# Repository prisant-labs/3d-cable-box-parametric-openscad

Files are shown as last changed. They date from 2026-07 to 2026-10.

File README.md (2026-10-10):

# Parametric Cable Management Box

A cable box you size to your stuff, not the other way round. Configurable
openings on every wall, an optional cable-wrapping post, interior stiffening
fins, floor cutouts, optional Gridfinity interfaces, and a slicing mode that
splits oversized boxes into pieces that clip together.

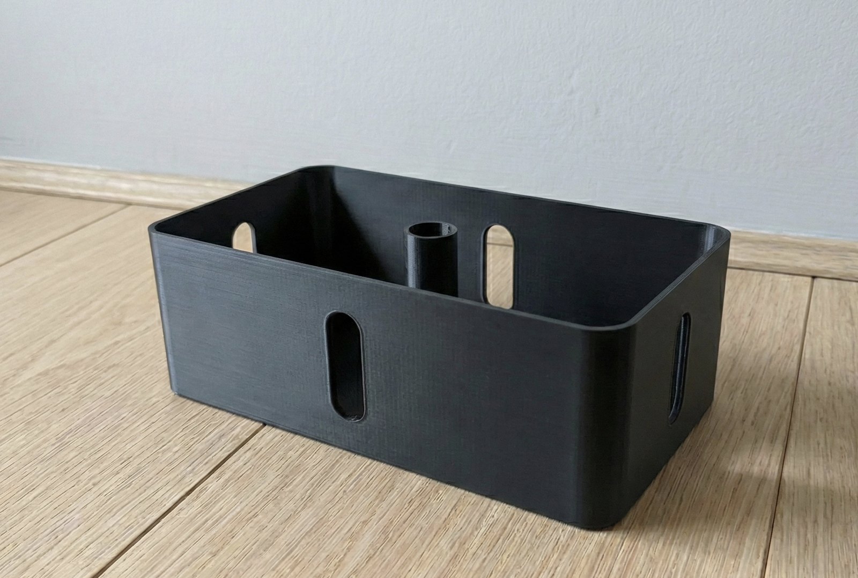
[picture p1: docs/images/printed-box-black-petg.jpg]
A printed cable box in black PETG


*Printed in black PETG with `All_Openings_Up=0`, which sits the openings flush
with the floor so a cable resting on the desk slides straight in.*





## Get a box

**Just want to print one?** Pick a preset in the
[preset library](https://projects.prisantlabs.com/3d-cable-box-parametric-openscad/library/), which has 3D previews and
STL downloads, or take the files straight from [`library/`](library/). Nine
presets cover the common jobs, from a compact desk tidy to a six-outlet surge
strip split for a 180 mm bed. No software needed beyond your slicer.

Both track `main`, so they match the current model. The
[Releases page](https://github.com/prisant-labs/3d-cable-box-parametric-openscad/releases) holds fixed, tested snapshots, and from `v2.0.0-rc.4` on
each release attaches all nine presets as `cable-box-presets.zip`. Until 2.0.0
ships as final, GitHub's "Latest" release is still `v1.4.1`, from before the
2.0.0 changes, so take the newest "Pre-release" for the current geometry.

Printing a feature for the first time, such as a Gridfinity base, snap clips,
or magnets? Print a small [fit test box](docs/PRINTING.md#fit-test-box) with
the same settings first, before you commit to a full box.

**Want to change something?** The model needs
[BOSL2](https://github.com/BelfrySCAD/BOSL2):

```bash
# Windows and macOS
git clone https://github.com/BelfrySCAD/BOSL2.git ~/Documents/OpenSCAD/libraries/BOSL2

# Linux
git clone https://github.com/BelfrySCAD/BOSL2.git ~/.local/share/OpenSCAD/libraries/BOSL2
```

Then open `cable-box-parametric.scad` in [OpenSCAD](https://openscad.org/)
(2021.01 or newer), press <kbd>F3</kbd> for the Customizer, adjust,
<kbd>F6</kbd> to render, then export an STL.

Would rather not install anything? Every release attaches a **standalone
bundle** with BOSL2 inlined. Unzip both files into the same folder and open the
bundled `.scad`.

If you open the plain `.scad` without BOSL2 installed, the model stops with a
message telling you so, rather than rendering nothing and exiting successfully.

**Want to see what everything does first?** Open the
[visual options guide](https://projects.prisantlabs.com/3d-cable-box-parametric-openscad/options-guide.html). Every parameter is rendered
from the model, in one self-contained file you can also
[download](docs/options-guide.html) to use offline.

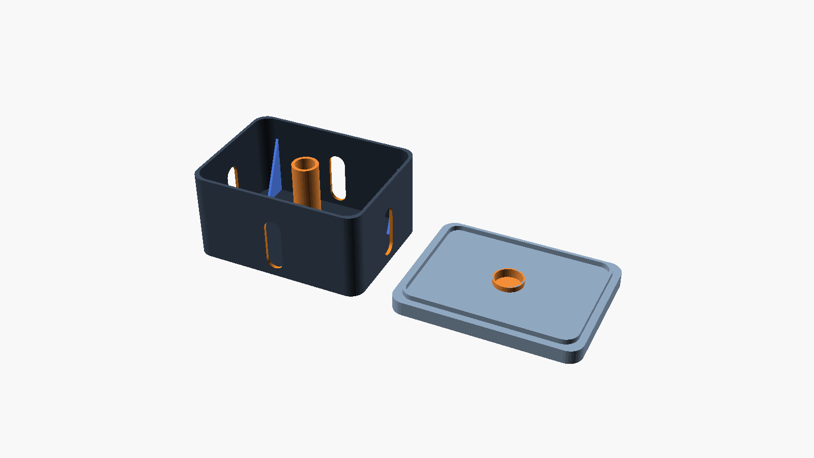
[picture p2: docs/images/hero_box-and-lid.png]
Box and lid


## What it does

| | |
|---|---|
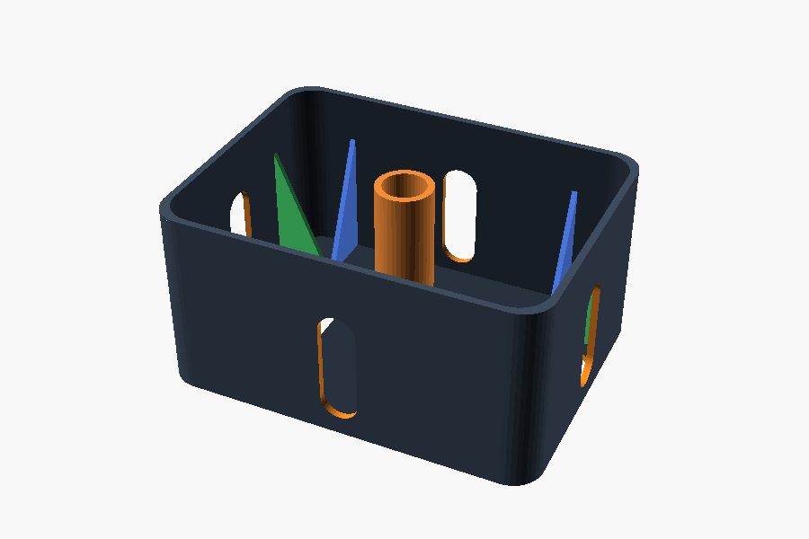
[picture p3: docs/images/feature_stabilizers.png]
Stabilizer fins and floor cutouts
|  | **Fins and floor cutouts.** Interior ribs stiffen long walls and automatically skip positions that would block an opening. Floor cutouts arrange along either axis and split around the centre post. |
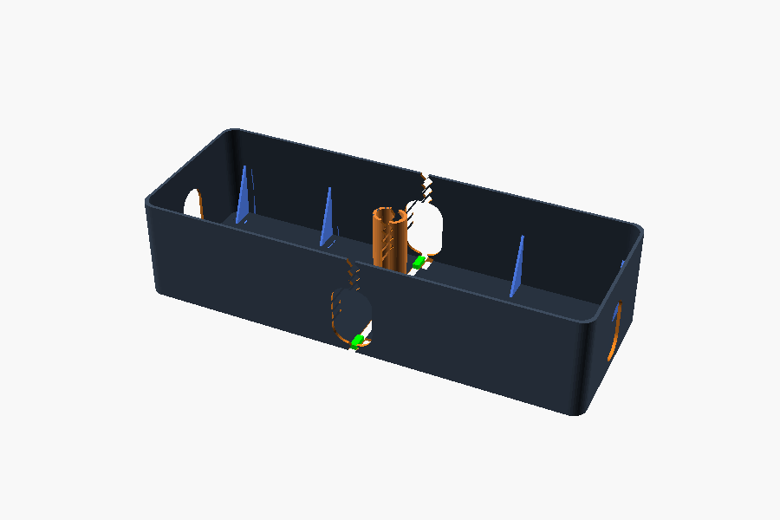
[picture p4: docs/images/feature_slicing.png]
Slicing into two clipping halves
|  | **Bigger than your printer?** Slicing mode splits the box and lid into pieces joined by tab or snap clips, so a 265 mm box prints on a 180 mm bed. |
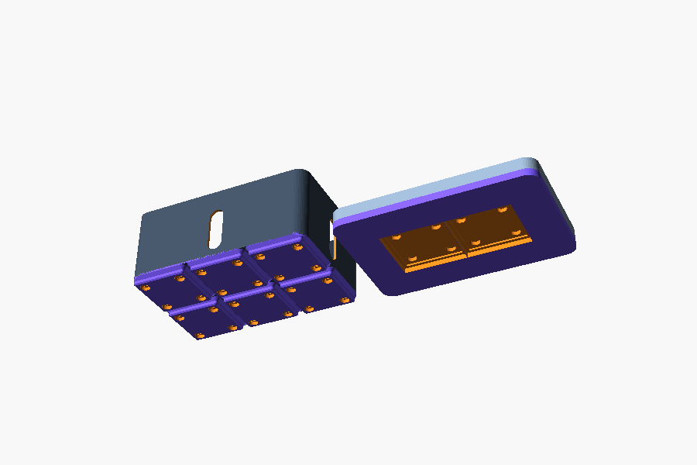
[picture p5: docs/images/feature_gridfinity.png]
Gridfinity interfaces on the underside
|  | **Gridfinity, optionally.** Solid feet built to the spec's profile, so the box drops into a standard 42 mm baseplate, with the footprint rounded up to whole cells. A baseplate socket on the lid lets bins sit on the closed box. Optional magnet and screw pockets, whose bridging layers follow `Print_Layer_Height`. The lid top is experimental for now: test prints show its sockets do not yet print or fit as cleanly as a standard baseplate. |
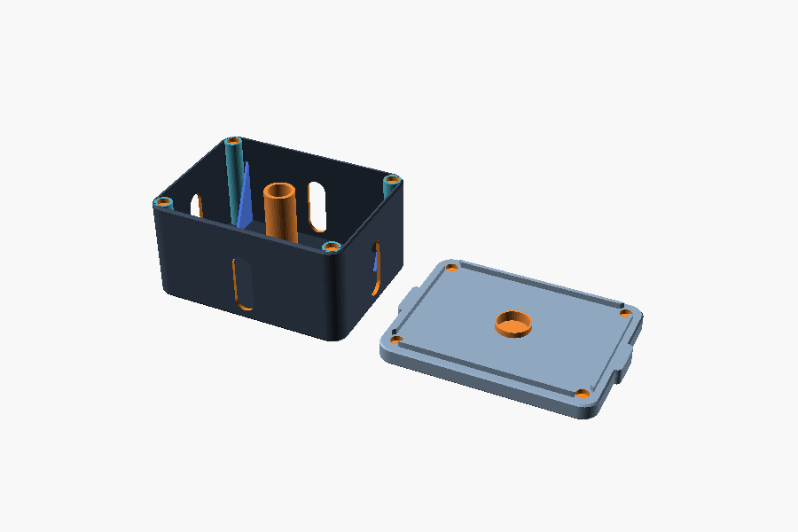
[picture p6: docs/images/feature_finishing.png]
Rounded edges, lid grips and corner magnet bosses
|  | **Finishing touches.** A rounded bottom edge and a chamfered rim, a scallop or tab grip so a tight lid comes off without a tool, and corner magnets that hold the lid shut. For printing without supports, `All_Opening_Top_Style=Teardrop` gives openings 45 degree tops, and `Bottom_Edge_Style` can meet the bed at 45 degrees. All are off by default. |

Plus: per-wall opening sizes and positions, an open or closed-bottom centre
post, adjustable lid fit, and corner radii from crisp to soft.

### Seam joints

Sliced boxes join with one of two clip styles:

- **`Tab`** (default) is a friction fit. Simple, and tuned with `Clip_Tolerance`.
- **`Snap`** is a cantilever clip with an engagement bump. The arm flexes, so it
  absorbs print inaccuracy instead of jamming, and the bump resists pull-out
  rather than relying on interference.

`Snap` is opt-in for now. Clip correctness is the one thing here that rendering
cannot check: a joint too tight to assemble passes every automated test. The
default flips once a print says it should.

Above the floor, each seam is cut as a 45 degree sawtooth through the walls, so
the joined pieces cannot slide vertically and their rims meet flush. The teeth
print without supports, and `Seam_Tooth_Depth=0` gives a flat seam instead.

### Composing with it

The box and lid are BOSL2 attachables, so accessories attach to named features
instead of computed coordinates:

```scad
Render_On_Include = false;   // or -D Render_On_Include=false
include <cable-box-parametric.scad>

m_box()
    attach("wall-back")
        my_bracket();
```

Anchors: `floor`, `rim`, `wall-front`, `wall-back`, `wall-left`, `wall-right`,
`post-top`, plus `lid-face` and `lip` on the lid. `lid-face` names the face that
ends up exposed when the box is closed, so nobody has to re-derive which side of
a face-down-printed lid is up.

## Presets

Nine ready-to-print configurations live in [`library/`](library/), each with a
complete `config.json`, STLs, renders, and notes. They are also browsable with
3D previews at
[the preset library on the docs site](https://projects.prisantlabs.com/3d-cable-box-parametric-openscad/library/).

| Preset | Fits | Size (mm) |
|---|---|---|
| [`usb-charger`](library/usb-charger/) | GaN multi-port charger and cables | 120 x 75 x 45 |
| [`desk-compact`](library/desk-compact/) | Short power strip, few cables | 140 x 80 x 55 |
| [`gridfinity-module`](library/gridfinity-module/) | Gridfinity 3 x 2 desk module | 125.5 x 83.5 x 60 |
| [`laptop-brick`](library/laptop-brick/) | Laptop charger plus 3 cables | 175 x 105 x 70 |
| [`under-desk-passthrough`](library/under-desk-passthrough/) | Cable junction, no post | 180 x 85 x 50 |
| [`monitor-junction`](library/monitor-junction/) | Two monitor bricks | 210 x 95 x 62 |
| [`router-shelf`](library/router-shelf/) | Router or modem plus PSU | 230 x 130 x 75 |
| [`surge-strip-6`](library/surge-strip-6/) | Six-outlet surge protector | 265 x 100 x 62 |
| [`surge-strip-6-sliced`](library/surge-strip-6-sliced/) | Same, split for a 180 mm bed | 265 x 100 x 62 assembled; largest piece 136 x 100 |

All nine are also collected into `cable-box-parametric.json` next to the model,
so opening `cable-box-parametric.scad` and pressing <kbd>F3</kbd> offers every
preset in the Customizer's dropdown.

Load one from the command line, from the merged file:

```bash
openscad -o out.stl cable-box-parametric.scad \
  -p cable-box-parametric.json -P desk-compact
```

Or from a single preset's own copy:

```bash
openscad -o out.stl cable-box-parametric.scad \
  -p library/desk-compact/config.json -P desk-compact
```

Both are OpenSCAD's native parameter-set format, so a set you save from the
desktop Customizer drops straight back in, and settings survive a round trip.

## Documentation

Published at
**[projects.prisantlabs.com/3d-cable-box-parametric-openscad](https://projects.prisantlabs.com/3d-cable-box-parametric-openscad/)**.

| Doc | What's in it |
|---|---|
| [Options guide (HTML)](https://projects.prisantlabs.com/3d-cable-box-parametric-openscad/options-guide.html) | Every parameter, rendered. Self-contained; [download it](docs/options-guide.html) to use offline. |
| [Options guide (Markdown)](docs/OPTIONS_GUIDE.md) | The same, readable on GitHub. |
| [Parameter reference](docs/PARAMETER_REFERENCE.md) | Exhaustive tables for every parameter. |
| [Workflows](docs/WORKFLOWS.md) | Setup, calibration, slicing, troubleshooting. |
| [Printing guide](docs/PRINTING.md) | Materials, orientation, fit test boxes, and fit tuning. |
| [FAQ](docs/FAQ.md) | Common questions and fixes. |
| [Validation rules](docs/VALIDATION_RULES.md) | Every assertion, what triggers it, how to resolve it. |
| [Module reference](docs/MODULE_REFERENCE.md) | Module-by-module geometry breakdown. |
| [Architecture](docs/SCAD_ARCHITECTURE.md) | Data flow and coordinate conventions. |
| [Parameter interactions](docs/PARAMETER_INTERACTIONS.md) | Cross-parameter behaviour. |

## A note on dimensions

`Box_Width`, `Box_Depth`, and `Box_Height` are **outer** dimensions. Usable
interior is smaller by `Wall_Thickness` on each side, and smaller again wherever
stabilizer fins sit. The model echoes the numbers at render time.

Side openings are anchored at their **bottom edge**. The default
`All_Openings_Up = 5` lifts that edge 5 mm above the box floor. Set it to `0`
to put the opening flush with the box bottom, so a cable lying on the desk
passes straight in without climbing a lip.

## Contributing

The most useful contribution right now is a print report. Print a small
[fit test box](docs/PRINTING.md#fit-test-box) and open an issue with the
result, even when it fits, because that is what turns "renders cleanly" into
"prints cleanly".

Presets are the next easiest: add an entry to `PRESETS` in
`scripts/build_library.py` and rerun it. See [`CONTRIBUTING.md`](CONTRIBUTING.md),
[`CODE_OF_CONDUCT.md`](CODE_OF_CONDUCT.md), and [`SECURITY.md`](SECURITY.md).

Behaviour changes need the docs updated in the same PR, and a test scenario if
the change guards a failure mode that would otherwise exit `0`.

## Validation

Model changes are gated by an automated geometry suite, not just a compile check.

```bash
python tests/run_tests.py          # 118 scenarios
bash scripts/scad-smoke.sh         # quick render smoke
bash scripts/check-version.sh      # version consistency
bash scripts/bump-bosl2.sh         # verified BOSL2 dependency upgrades
```

The suite asserts exit codes, assertion text, manifoldness, disconnected-solid
counts, bounding boxes, absence of warnings, and point probes against the
exported mesh. That matters more than it sounds: OpenSCAD will happily return
`0` while producing a model with a detached, unprintable piece in it, or a
correctly-sized part rotated onto the wrong axis.

The runner prints which BOSL2 version OpenSCAD actually loads before running
anything, because a local suite silently testing a different library version
than CI is a real failure mode this project has already hit.

## Licence

[MIT](LICENSE). Print them, sell them, remix them.

Third-party components keep their own terms; see
[`THIRD_PARTY_NOTICES.md`](THIRD_PARTY_NOTICES.md). Gridfinity is by Zack
Freedman and is MIT licensed; the interface geometry here is implemented from
the published specification rather than vendored.

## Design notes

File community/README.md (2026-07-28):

# Community

Community-contributed builds, remixes, and showcases live here.

## What belongs here

- User variants and remixes
- Print photos and setup shots
- Alternative parameter profiles
- Build notes and lessons learned

## Suggested contribution layout

- `community/<github-user-or-handle>/<project-name>/README.md`
- `community/<github-user-or-handle>/<project-name>/images/*`
- `community/<github-user-or-handle>/<project-name>/stl/*` (optional)
- `community/<github-user-or-handle>/<project-name>/config.*` (recommended)

## Contributor README minimum

- Short description and use case
- Parameter highlights
- Printer/material used
- Known fit adjustments
- License/attribution notes if third-party content is included

## Moderation and quality guidance

- Keep content respectful and technically useful.
- Avoid storing sensitive personal information in media or docs.
- Verify that contributed files are license-compatible with the repository policy.

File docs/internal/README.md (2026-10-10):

# Internal Planning Docs

Scoping documents for the work behind each release. They live in the repo
without appearing on the public site: `web/sync-docs.mjs` copies a named list of
pages into the site's content directory, and this directory is not on it, so
nothing here is published unless someone adds it deliberately. (The old
mechanism was `exclude_docs: internal/` in `mkdocs.yml`, which no longer exists.)

Each effort carries an ID and a handle. Always write both on first mention, in
commits, issues, and chat: "E-01 (Gridfinity promotion)", never a bare "E-01".

Status values: **Shipped** in the named release, **Open** for started but
incomplete, **Spec** for written but not begun.

## Efforts

| ID | Handle | Scope | Status | Effort | Depends on |
|---|---|---|---|---|---|
| [E-01](E-01_gridfinity-promotion.md) | **Gridfinity promotion** | Box-underside and lid-topside Gridfinity interfaces | Shipped v1.2.0; lid reworked to a socket in 2.0.0. Geometry replaced by E-12 after the rc.5 prints | S | none |
| [E-02](E-02_bosl2-migration.md) | **BOSL2 migration** | Build on BOSL2 rather than hand-rolled primitives | Shipped: phase 1 v1.3.0, phases 2-3 v1.4.0 | L | none |
| [E-03](E-03_openings-array.md) | **Openings array** | Replace 4 fixed per-wall openings with an array-driven spec | Spec | M | E-02 (easier after) |
| [E-04](E-04_quick-wins.md) | **Quick wins** | Edge treatment, lid removal relief, magnet retention | In `v2.0.0-rc.3`, final in 2.0.0. Opt-in defaults. Edge treatment and magnets confirmed by test prints; relief unprinted | S | none |
| [E-05](E-05_size-by-contents.md) | **Size by contents** | Size the box from what goes in it, not from outer dimensions | Spec | M | none |
| [E-06](E-06_thermal-and-vents.md) | **Thermal and vents** | Ventilation generator plus material guidance for powered contents | Spec | M | E-03 (shares cut logic) |
| [E-07](E-07_preset-library.md) | **Preset library** | A real catalogue of common sizes and configurations | Shipped: catalogue v1.2.0, browser 2.0.0 | M | E-09 (needs artifact automation) |
| [E-08](E-08_web-customizer.md) | **Web customizer** | Browser-based customizer on GitHub Pages | Open. Site shell and preset browser shipped; the WASM playground is not built | M | E-02 (library availability) |
| [E-09](E-09_testing-automation.md) | **Testing automation** | Automated geometry regression testing beyond compile checks | Shipped v1.1.1; 118 scenarios today | M | none |
| [E-10](E-10_versioning.md) | **Versioning** | Version scheme, pre-release flow, traceability from STL to source | Shipped v1.1.1; rc flow used for v1.2.0-rc.1 and v2.0.0-rc.1 through rc.4; releases drafted by `release.yml` | S | none |
| [E-11](E-11_distribution.md) | **Distribution** | MakerWorld, Printables, and the licensing question that gates them | Open. Licence settled (MIT); listing drafted, nothing published | S | E-02 (MakerWorld benefits) |
| [E-12](E-12_gridfinity-to-spec.md) | **Gridfinity to spec** | Rebuild both Gridfinity interfaces on the standard's swept profile, printable without supports | Phase A (box feet) in `v2.0.0-rc.6`, waiting on its print; phase B (lid top) next, for rc.7 | M | none |
| [E-13](E-13_seam-joints.md) | **Seam joints** | A 45 degree sawtooth seam through the walls, so sliced halves cannot slide vertically | In `v2.0.0-rc.6`; waiting on the rc.6 print | S to M | none |
| [E-14](E-14_printability-options.md) | **Printability options** | Opt-in teardrop opening tops, a bottom edge that meets the bed at 45 degrees, and a layer height for the Gridfinity bridging | In `v2.0.0-rc.6`, with every default unchanged; waiting on the rc.6 print | S to M | E-12 phase A (merged) |

Effort key: S = under a day, M = a few days, L = a week or more.

Ideas not yet scoped as an effort, and known problems still open, are in
[BACKLOG.md](BACKLOG.md).

## What is left

The infrastructure efforts are done: testing (E-09), versioning (E-10), the
BOSL2 migration (E-02), the preset library (E-07), and the Gridfinity interfaces
(E-01) have all shipped. What remains splits three ways.

**Answered by test prints, now designed.** The rc.4 and rc.5 test prints
settled the lid fit. They also showed two problems, and both were scoped on
2026-10-07 for the 2.0.0 release-candidate series, ahead of the 2.0.0 release:

- [E-12 (Gridfinity to spec)](E-12_gridfinity-to-spec.md) rebuilds the
  Gridfinity interfaces from E-01 (Gridfinity promotion). They print poorly and
  do not follow the standard's 45 degree profile, as backlog items 15
  (Gridfinity base seating) and 18 (Gridfinity printability) record.
- [E-13 (seam joints)](E-13_seam-joints.md) answers backlog item 20 (seam
  alignment): neither clip style holds sliced halves level. The snap-clip
  default in [E-02-P2 (snap clips)](E-02-P2_snap-clips.md) is decided by the
  same print round.

**Printing without supports.** [E-14 (printability options)](E-14_printability-options.md)
adds three opt-in parameters for printing without supports. It was scoped on
2026-10-08 for 2.1.0, and on 2026-10-09 the maintainer moved it into
`v2.0.0-rc.6`. Every default keeps today's geometry, so no preset changes.

**Feature work, in rough order of value per unit of effort.**

1. **E-04 (quick wins)**, independent of everything and the largest visible
   difference for the smallest change.
2. **E-03 (openings array)**, which E-06 then builds on.
3. **E-06 (thermal and vents)**, sharing E-03's cut-placement logic.
4. **E-05 (size by contents)**, now better informed by the nine presets in
   E-07 than it would have been before them.

**Delivery.** E-11 (distribution) is ready whenever the print clears the claims
in the listing copy. E-08 (web customizer) is the largest single remaining
piece and the only unbuilt part of the site; `library/index.json` was shaped
for it, so its "load a preset" path is already fed.

## Cross-cutting decisions still open

- ~~**Provenance of the original design.**~~ **Decided 2026-10-02: become
  independent rather than credit it going forward.** Releases through
  `v2.0.0-rc.3` derived from a 2022 Creative Commons Attribution design, and
  `THIRD_PARTY_NOTICES.md` says so. The code is rewritten as of 2.0.0. The
  inherited Customizer interface goes in [E-03 (openings array)](E-03_openings-array.md),
  which carries the checklist.

- ~~**License.**~~ **Resolved 2026-07-29: MIT.** Reasoning recorded in
  [E-11 (distribution)](E-11_distribution.md). Matches Gridfinity's own licence,
  suits a model that is really source code, and is GPL-compatible for
  [E-08 (web customizer)](E-08_web-customizer.md).
- ~~**Single-file versus library dependency.**~~ **Resolved 2026-07-31:** real
  BOSL2 dependency, with a two-file bundle attached to releases. See
  [E-02 (BOSL2 migration)](E-02_bosl2-migration.md).
- ~~**Whether `Model_Version` lives in the SCAD.**~~ **Resolved:** yes, added in
  v1.1.1 with a CI consistency gate. See [E-10 (versioning)](E-10_versioning.md).

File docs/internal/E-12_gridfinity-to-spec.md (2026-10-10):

# E-12: Gridfinity to spec

**Handle:** Gridfinity to spec. Rebuild both Gridfinity interfaces on the
standard's swept profile, so the box seats in a real baseplate and both parts
print without supports.

**Status:** Scoped 2026-10-07. Phase A (box feet) implemented 2026-10-08
and shipped in `v2.0.0-rc.6`; phase B (lid-top baseplate) not started, for
rc.7. Replaces the geometry of
[E-01 (Gridfinity promotion)](E-01_gridfinity-promotion.md); E-01's two toggles
and its user-facing parameters stay.
**Effort:** M
**Depends on:** nothing. Ships in the 2.0.0 release-candidate series together
with [E-13 (seam joints)](E-13_seam-joints.md).

## Why

The rc.5 prints and a check of the code on 2026-10-07 found three defects.

1. **The base cannot enter a standard baseplate.** Each cell is a
   square-cornered 41.5 mm block. Its corners reach 29.35 mm from the cell
   centre, but the pocket's rounded corner reaches only 28.04 mm. The pocket
   also narrows to 37.7 mm within 2.15 mm of its top. This settles
   [backlog item 15 (Gridfinity base seating)](BACKLOG.md) by arithmetic,
   without needing a print.
2. **Both interfaces print poorly**, as
   [backlog item 18 (Gridfinity printability)](BACKLOG.md) records. The base is
   hollowed from below, with a 90 degree step and a 37.45 mm ceiling. The lid
   prints face-down, so each socket floor is a 37.45 mm bridge. The box body
   also overhangs its feet with a flat ledge. The ledge was 4.25 mm on the
   50 mm coupon. On the default 100 by 75 mm box it is 8.25 mm on two sides
   and 16.75 mm on the other two.
3. **The base's magnet and screw holes hold nothing.** They sit inside the
   hollow cavity's footprint, so they cut only its 0.45 mm ceiling. This was
   found by arithmetic on `m_gridfinity_bottom_holes`, not by a print.

The research behind this effort is local to the maintainer's checkout:
`_local/research/2026-10-06_gridfinity-spec-and-projects.md`, and the saved
spec and generator sources in `_local/research/gridfinity-reference/`. The spec
numbers below were checked on 2026-10-07 against both the spec diagram and
kennetek's `standard.scad`.

## Decisions (2026-10-07)

1. **Build to the spec profile, solid.** Every reviewed generator builds feet
   and pockets solid by default. A hollow base is always a separately named
   option in those projects, never the default.
2. **The base footprint rounds up to whole cells.** When
   `Enable_Gridfinity_Bottom` is on, the box's outer width and depth become
   the smallest `N * 42 - 0.5` mm that is at least the typed size. The model
   echoes the size it used. This reverses E-01's choice to centre a clipped
   grid under a box of any size.
   - The reason: a box wider than its feet must overhang them, and nothing can
     fill the space under that overhang. Once the box is seated, the
     neighbouring baseplate pockets occupy it.
   - The overhang also blocks those neighbouring pockets, so rounding up costs
     no baseplate area. A 75 mm deep box overhangs 16.75 mm on each side and
     blocks three rows of cells. Rounded up to 83.5 mm, it fills exactly two.
   - Rejected: a 45 degree bevel on the box's bottom edge, which is as tall as
     the margin (up to about 25 mm) and takes a wedge out of the interior.
   - Rejected: a flat ledge printed with supports.
3. **A Gridfinity lid prints pocket-side up, with a solid plug.** When
   `Enable_Gridfinity_Lid_Top` is on, the exported lid is flipped, so its
   pockets face up and print with no bridge.
   - The lid's underside then sits on the bed, so the plug ring is filled
     solid. Otherwise the panel would bridge the whole box opening.
   - A plug that is solid in the model prints as infill, so it costs little
     filament.
   - A Skirt lid gets the same fill and becomes a groove lid.
   - Rejected: Gridfinity feet under the lid with a stacking lip on the box
     rim, as in vector76's `base_lid()`. It suits only grid-sized boxes, and a
     lip on a 1.85 mm wall needs a support wedge.
   - Rejected: catches or hinges, as in the three reference models the
     maintainer named. They abandon the drop-in lid.
4. **One effort with two phases.** The base and the lid share the profile code
   and one fit test, so splitting them would buy nothing.
5. **Ships in the 2.0.0 release-candidate series.** Both phases change the
   output for unchanged inputs, which
   [E-10 (versioning)](E-10_versioning.md) classes as major. Landing them
   before 2.0.0 lets one major version absorb them.

## Decisions (2026-10-08, phase A)

6. **Build each foot with `offset_sweep()`, and emit all the feet as one
   polyhedron.** A benchmark on OpenSCAD 2021.01 with CGAL compared four ways
   to build a foot: `offset_sweep()`, the same sweep computed once, kennetek's
   piecewise sweep, and two convex hulls. At 3 x 2 and 6 x 4 cells they finished
   within about 1 s of each other, so the build method does not matter. The
   cost is CGAL's union of the rounded feet with the box, and 2021.01 unions a
   module's children one at a time. Joining every foot into one polyhedron
   makes it a single union, which gives the same mesh with the feet's render
   time cut by about 45 percent. Pinned to one performance core, the finished
   model, corner clip included, renders the default box with feet in 7.9 s
   against rc.5's 4.3 s, and the 6 x 4 router-shelf box in 20.6 s against
   6.6 s. The harness and results are local to the
   maintainer's checkout, in `_local/research/e12-foot-benchmark/`.
7. **Clip the corner feet to the box's outline (maintainer).** The default
   `Box_Corner_Radius` of 8.1 mm is rounder than a foot's 3.75 mm corner, so
   the four corner feet stood outside the wall. The crossing arcs also left
   slivers that CGAL could not re-import, so every probe on the default box
   failed. Clipping keeps the user's corner radius and makes those feet
   smaller, which a baseplate still accepts. The clip is built the way the
   shell is, so the arcs share vertices. Rejected: capping `Box_Corner_Radius`
   at 3.75 mm when the base is on, which would change how every Gridfinity box
   looks.
8. **The bridging layers sit above the 2.4 mm pocket.** kennetek puts them
   inside the pocket's top 0.4 mm, which leaves a full-width pocket only 2.0 mm
   deep. This effort's acceptance criterion asks for a 6.5 x 2.4 mm pocket, so
   the two 0.2 mm layers run from 2.4 to 2.8 mm and the screw hole starts above
   them.
9. **`Gridfinity_Magnet_Diameter` defaults to `6.25`.** Every pocket adds
   `Gridfinity_Profile_Clearance`, and 6.25 plus the default 0.25 is the spec's
   6.5 mm. Changing the default rather than the formula keeps the meaning of
   every value a user has already set.

## Spec dimensions

All values are in millimetres. They come from the gridfinity.xyz spec diagram
(CC BY-NC-SA), cross-checked against kennetek's MIT `standard.scad`.
Dimensions are facts, so the geometry is written here from the numbers alone.

| Feature | Value |
|---|---|
| Grid pitch | 42 |
| Foot, top footprint per cell | 41.5 square, 3.75 corner radius |
| Foot profile, from the bottom | 0.8 at 45 degrees, 1.8 vertical, 2.15 at 45 degrees (4.75 tall) |
| Foot, bottom footprint | 35.6 square, 0.8 corner radius |
| Baseplate pocket, top footprint per cell | 42 square, 4.0 corner radius |
| Baseplate pocket profile, from the bottom | 0.7 at 45 degrees, 1.8 vertical, 2.15 at 45 degrees (4.65 tall) |
| Magnet pocket | 6.5 diameter, 2.4 deep |
| Hole offset from the cell centre | 13 on each axis |

## Phase A: box feet

- Replace `m_gridfinity_bottom_solid` and `m_gridfinity_bottom_cavities` with
  one solid swept foot per cell.
- Build the sweep with BOSL2's `offset_sweep()` and an `os_profile()` point
  list, if it renders acceptably on OpenSCAD 2021.01 with CGAL. Otherwise, use
  a hand-written sweep, as kennetek does. Benchmark this first, on the largest
  library preset.
- Derive the rounded footprint once, near the top of the model. Every
  reference to `Box_Width` or `Box_Depth` that shapes the box must use the
  derived pair. The echo that reports a changed size must avoid the words
  `WARNING` and `DEPRECATED`, which the suite fails on.
- Cut magnet pockets up from each foot's bottom face, at 13 mm from the cell
  centre on each axis. At the defaults, the effective pocket must be 6.5 mm
  across. Today's parameters give 6.2 + 0.25 = 6.45 mm.
- Screw holes pass up through the foot. Where a magnet pocket sits over a
  screw hole, its ceiling uses stepped bridging layers, so it prints without
  supports. kennetek's `make_hole_printable()` (MIT) shows the technique.
- Keep the existing asserts against bottom openings and the open post, and
  keep the render-time lift by `Gridfinity_Base_Offset`.
- `Gridfinity_Edge_Keepout` no longer affects the base. It still sets the lid
  top's margin when the base is off.

## Phase B: lid-top baseplate

- Cut spec baseplate pockets down into a solid slab. Each pocket's floor is the
  flat top of solid material, the way vector76's `base_lid()` builds it.
- Lid-top magnet pockets go down from each pocket floor, as they do now.
- **Cell count.** When the base is also on, the lid holds the same cells as the
  base, so a second box stacks on the first. The lid's outer footprint is then
  `N * 42 + 3.5` mm, which leaves 1.75 mm beside the outermost pockets. When
  only the lid top is on, the keepout rule stays.
- **Solid plug.** Fill the plug (or, for a Skirt lid, the region inside the
  skirt) solid to `Lid_Lip_Gap_Height`. The magnet-boss notches and the post
  socket stay as cuts. They become short bridges of about 12 mm and 15 mm.
- **Flip.** Export the lid rotated 180 degrees about X, so the plug's face sits
  on z = 0. The preview layout and the `lid-face` anchor in `m_lid_part` must
  follow the flip.
- **Seam clips.** On a sliced lid, the flip moves the seam clips off the bed.
  They must start on the bed in the flipped orientation. Coordinate this with
  [E-13 (seam joints)](E-13_seam-joints.md).

## Tests

Write each scenario first, and confirm it fails against rc.5, as `AGENTS.md`
requires.

- **Conformance to the standard, not only to itself.** A new assembly test
  builds a reference foot and a reference pocket from the spec numbers typed
  into the test file, independent of the model's constants. The rc.4 coupon
  seated in the model's own socket, which proved only that the model agreed
  with itself.
  - The model's feet seated in the reference pocket overlap nothing, and a
    "seated" probe shows they reach full depth.
  - The reference foot seated in the model's lid pocket overlaps nothing, and
    reaches full depth.
- **Stacking.** One box's feet seated in another box's lid-top pockets overlap
  nothing.
- **Profile probes.** Material and empty probes check the foot's width at the
  profile's corners: 0.8, 2.6, and 4.75 mm above the foot's bottom.
- **Footprint.** Bounding-box checks show the rounded size, for example
  75 mm typed giving 83.5 mm.
- **Solids.** The box with feet and the lid with pockets each export as one
  solid, sliced and unsliced.
- **No regression.** With both toggles off, every part is mesh-identical to
  rc.5 under the canonical comparison that `build_library.py` uses.

## Acceptance criteria

- [x] The model's feet seat fully in a spec-built reference pocket with no
      overlap. Phase A: `tests/assembly/gridfinity_seated.scad`.
- [ ] A spec-built reference foot seats fully in the lid-top pocket with no
      overlap.
- [ ] One box's feet seat in another box's lid-top pockets.
- [x] The base footprint rounds up to whole cells, and the model echoes the
      size it used.
- [ ] Neither part has a flat overhang or bridge wider than about 15 mm in its
      print orientation. The box meets this after phase A; the lid waits for
      phase B.
- [x] The magnet pockets are 6.5 by 2.4 mm at the defaults. Probes check the
      pocket's position and depth; the 6.5 mm diameter rests on the parameter
      arithmetic, because a probe cannot tell it from rc.5's 6.45.
- [x] With both toggles off, every part is mesh-identical to rc.5. Checked
      for phase A on seven configurations: box, lid, box and lid, a slice, an
      edge-treated box, a lid-top-only lid, and the router-shelf preset.
- [x] `docs/VALIDATION_RULES.md`, `docs/PARAMETER_REFERENCE.md`,
      `docs/PRINTING.md` (print orientation), and `docs/FAQ.md` change in the
      same commit as the model. Phase B must update them again.

## Human print test

Phase A prints from `v2.0.0-rc.6`. Phase B prints from rc.7.

- [ ] rc.6: a box with Gridfinity feet seats in a real baseplate, either
      bought or printed from kennetek's generator.
- [ ] rc.6: the box prints without supports on the maintainer's P1S.
- [ ] rc.7: a standard Gridfinity bin seats in the lid-top pockets.
- [ ] rc.7: the lid prints without supports on the maintainer's P1S.
- [ ] rc.7: the solid-plug lid still fits its box at the default 0.15 mm
      gap.

## Risks

- **Render time.** Measured for phase A (Decision 6): acceptable, and a
  hand-written sweep would not have been faster.
- **A seam through a foot.** With an odd cell count, a slice seam runs through
  a foot. At the defaults, the seam at x = 0 halves the middle foot. Each half
  prints flat and the halves rejoin when the pieces are joined, and
  `gridfinity_bottom_sliced` shows each piece is still one solid. A printed
  sliced box on a baseplate has not been tried.
- **The footprint touches every size reference.** One derived pair, a search
  for every `Box_Width` and `Box_Depth` use, and the full suite contain this.
- **The flip changes the lid's frame.** Relief, magnets, seam clips, and
  slicing are all written in the face-down frame. Scenarios for a Gridfinity
  lid need probes written in the flipped frame.

## Licensing

Dimensions come from the spec diagram, which is CC BY-NC-SA. The geometry is
written here from those numbers, not copied. Techniques may come from kennetek's
and vector76's MIT projects. ostat's project has been GPLv3 since 2024-12-26,
so it is for reading only.

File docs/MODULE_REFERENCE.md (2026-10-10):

# Module Reference

This page describes each custom module in `cable-box-parametric.scad`, what it builds, and where it is used.

## Top-Level Render Flow

- Entry point: `full_render()`
- Main branches:
  - Slicing disabled: render `m_box_with_openings()` and/or `m_lid()`
  - Slicing enabled: render `m_box_slice(i)` and/or `m_lid_slice(i)`

## Core Box and Lid

### `m_box_base()`

Builds base box solids and subtractive cavities before side openings are cut.

Includes:

- Outer shell and inner hollow shell
- Optional center post outer/inner solids
- Optional stabilizers
- Optional bottom openings subtract
- Optional Gridfinity feet, with their magnet pockets and screw holes subtracted

Used by:

- `m_box_with_openings()`

### `m_box_with_openings()`

Wraps `m_box_base()` and subtracts side openings for enabled walls.

Behavior:

- Applies global offsets and per-side offsets
- Uses per-side width/height overrides when override values are greater than `0`

Used by:

- non-sliced render path
- `m_box_slice()`

### `m_lid()`

Builds the lid: the body from `m_lid_body()`, plus the optional center-post
collar and socket, magnet pockets, Gridfinity lid top, and finger relief.

Behavior:

- Handles the post socket if `Enable_Post=true`. The socket bore is
  `Post_Diameter + 2*Lid_Lip_Gap`, so the post has the same clearance as the
  lip.

Used by:

- non-sliced render path
- `m_lid_slice()`

### `m_lid_body()`

Builds the lid's slab and its lip, in the style `Lid_Style` selects. Both
styles share the footprint `Lid_Outer_Width` x `Lid_Outer_Depth` and the total
height `Lid_Height + Lid_Lip_Gap_Height`.

- `Skirt`: one shell with a pocket cut into its top `Lid_Lip_Gap_Height`. The
  pocket is the box's outline plus `Lid_Lip_Gap` per side, so the skirt wraps
  the outside of the wall.
- `Plug`: a slab with a ring on top. The ring's outside is the box interior
  minus `Lid_Lip_Gap` per side, it is `Wall_Thickness` thick, and it is
  notched around the magnet bosses when `Enable_Lid_Magnets=true`.

Before 2.0.0-rc.5 the lip was a ring that overlapped the outer half of the box
wall, so the lid stood on the rim. The `assembly_*` scenarios seat the lid on
the box through `tests/assembly/lid_seated.scad` and fail on any overlap.

### `m_opening(side, width, height, corner_radius)`

Generates a side opening profile and extrudes through wall thickness.

Behavior:

- Orientation depends on `side`
- `corner_radius < 0` uses fully rounded slot ends
- `corner_radius = 0` produces a square-corner opening
- `corner_radius > 0` produces a rounded rectangle (clamped to valid half-extents)
- Works with vertical, horizontal, and square dimensions
- With `All_Opening_Top_Style="Teardrop"`, the two top corner circles of the
  hull become BOSL2 `teardrop()` shapes capped at the circle's top
  (`cap_h = r`), so the top prints without support and the opening keeps its
  height. `teardrop()` extrudes along Y with its point at +Z, so the side walls
  spin it onto X. Square openings are unchanged

## Stabilizers

### `m_stabilizer_fin(width, depth, height)`

Creates one triangular-wedge fin as a polyhedron.

### `m_stabilizers_front_back()`

Places stabilizers on front/back walls.

Key logic:

- Alignment modes: `Centered`, `Distributed`, `Custom`
- `Centered`/`Custom` pitch is controlled by `Stabilizer_FB_Spacing`
- Optional opening avoid zones per wall
- Avoid fallback: if all candidate positions are suppressed and distributed positions exist, it falls back to distributed

### `m_stabilizers_left_right()`

Places stabilizers on left/right walls with matching alignment/avoid behavior.

Key logic:

- Alignment modes: `Centered`, `Distributed`, `Custom`
- `Centered`/`Custom` pitch is controlled by `Stabilizer_LR_Spacing`
- Optional opening avoid zones per wall
- Avoid fallback: if all candidate positions are suppressed and distributed positions exist, it falls back to distributed

### `m_stabilizers()`

Wrapper that dispatches both stabilizer placement modules when enabled.

## Bottom Openings

### `m_bottom_opening_shape(width, length, corner_radius)`

Builds one bottom opening footprint with optional rounded corners.

### `m_bottom_openings()`

Primary dispatcher for bottom openings.

Chooses:

- arrangement axis handling (`Along X`, `Along Y`)
- secondary-axis alignment
- post-avoid path vs normal path

When post-avoid is enabled, primary and secondary alignment settings still apply while openings are kept outside the post-clearance zone.

### `m_place_openings_along_x(opening_size, y_pos, available_x)`

Places arrayed bottom openings along X with primary alignment logic.

### `m_place_openings_along_y(opening_size, x_pos, available_y)`

Places arrayed bottom openings along Y with primary alignment logic.

### `m_place_openings_avoid_post_x(opening_size, y_pos)`

Splits opening placement around center post clearance when arranged along X.

### `m_place_openings_avoid_post_y(opening_size, x_pos)`

Splits opening placement around center post clearance when arranged along Y.

## Slicing and Clips

### `m_floor_clip_male()`

Creates one male clip tab for box slice seams. `m_place_floor_clips` stands it
on `z=0`, so it spans z 0 to `Clip_Tab_Height` and the piece sits flat on its
floor. Before 2.0.0-rc.5 it was centred on the floor and hung 0.575 mm below
it.

### `m_floor_clip_female()`

Creates one female clip pocket using `Clip_Tolerance` and `SPACER` clearances.

### `m_place_floor_clips(x_pos, is_male)`

Places floor seam clips across depth based on `Clips_Per_Edge`.

### `m_edge_treated_shell(size, fillet, chamfer, bottom_style = "Fillet")`

The outer shell of the box or the lid slab. With both treatments at `0` it is
the `cuboid()` it has always been, which is how an untreated model is guaranteed
unchanged rather than merely expected to be. With a treatment it becomes a BOSL2
`offset_sweep()` over the same rounded rectangle, which resolves how a
horizontal fillet meets the vertical corner radius. `offset_sweep` expresses "no
profile" by omitting the argument, so the cases are enumerated rather than
passed a flat value.

`bottom_style` picks the bottom profile through `bottom_edge_profile()`. Only
the box passes `Bottom_Edge_Style`. The lid keeps the default, so that setting
never reaches the lid.

### `bottom_edge_profile(style, r)`

A function that returns the `offset_sweep()` bottom profile for a
`Bottom_Edge_Style`: `os_circle(r)` for `Fillet`, `os_teardrop(r)` for
`Teardrop`, and `os_chamfer(width = r)` for `Chamfer`. The teardrop is a
one-eighth arc that ends in a 45 degree chamfer, inset `0.59 * r` at the bed
instead of `r`. Every profile is at most `r` deep and `r` tall.

### `m_gridfinity_bottom_solid()` and `m_box_outline_prism(h)`

The Gridfinity feet under the box. One foot is swept once, at load time, into
`GF_FOOT_VNF` with BOSL2 `offset_sweep()`. `m_gridfinity_bottom_solid()` copies
it to every cell and emits all the copies as one polyhedron, because CGAL on
OpenSCAD 2021.01 unions separate children one at a time. It then clips the feet
to the box's outline with `m_box_outline_prism()`. That prism is built the same
way `m_edge_treated_shell()` builds the walls, so the corner arcs of the two
share vertices exactly. A clip whose arcs only nearly matched the wall's would
leave slivers that CGAL cannot read back.

### `m_gridfinity_bottom_holes()`

Magnet pockets cut up from each foot's bottom face, two stepped bridging layers
above each pocket, and the screw hole from there to the box's underside. The
first bridging layer is a slot across the pocket and the second a square, so
each layer's material spans a supported edge. Each layer is
`Print_Layer_Height` tall, so it matches one sliced layer.

### `m_lid_relief(is_cut)`

Finger relief on the lid's outer face, one shape per enabled wall, at the wall
centre. `is_cut = true` yields the scallop, a cylinder whose axis lies on the
face so the groove is a half cylinder and `Lid_Relief_Depth` is both its depth
and its half width. `is_cut = false` yields the tab, a rounded block centred on
the face so it overlaps rather than merely touching, for the same reason the
seam clips overlap their slice.

### `m_magnet_corner_positions()`

Places children at the four inside corners, each pushed `WELD` into the two
walls it sits against. The positions are symmetric in both axes, which is what
makes box and lid pockets align however the lid is flipped.

### `m_box_magnet_bosses()`, `m_box_magnet_pockets()`, `m_lid_magnet_pockets()`

The magnet features. Bosses run the full box height rather than stopping under
the rim, so they print from the bed up instead of overhanging, and stiffen the
corner. The box pocket opens at the rim; the lid pocket opens on the face that
meets it and reaches down into the slab, leaving the lid's exposed face solid.

### `m_place_lid_clips(x_pos, is_male)`

Places lid seam clips with lid-specific Z and depth extents.

The clip sits `SPACER` (0.04 mm) below the top of the lid panel rather than
flush with it. Flush, the clip's top face and the panel's top face are one
coplanar face, and on the slice seam the clip's corners become extra collinear
vertices along a straight edge; OpenSCAD then tessellates zero-area triangles
there, which slicers tolerate but CGAL rejects on re-import. Male and female
clips share the offset, so the fit is unaffected.

### `m_box_slice(slice_num)`

Cuts the box into one slice and applies seam clip logic. With
`Seam_Tooth_Depth > 0` each seam is cut by `m_seam_cutter` using
`box_seam_bands`; at `0` it takes the original flat cube cutters unchanged.

### `m_lid_slice(slice_num)`

Cuts the lid into one slice and applies seam clip logic, using
`lid_seam_bands` for its seam teeth.

### `m_seam_cutter(x_seam, keep_left, bands, z_lo, z_hi, reach)`

Removes everything on one side of a seam: the right side when `keep_left` is
true, the left side otherwise. Its edge is a profile in the XZ plane, extruded
along Y. Inside each `[s, e]` band of z the edge is a 45 degree sawtooth,
closed off by 45 degree lines at both ends; outside the bands it is a straight
vertical cut. The two pieces' edges sit `Clip_Tolerance` apart inside the
bands.

The sawtooth has no undercut, so the pieces still engage by pushing together
along X, as the floor clips do. A jigsaw or dovetail cut would only slide
together along Y, which the floor clips cannot.

### `box_seam_bands(x_seam)` and `lid_seam_bands(x_seam)`

Return the z bands that carry teeth at a seam.

- Box: the walls from the floor's top face to the rim, less the height range
  of any front or back opening that crosses the seam's tooth strip.
- Lid: the slab below the band the lid's seam clips occupy, or no bands when a
  front or back lid relief sits on the seam.

Bands shorter than one tooth depth are dropped.

## Attachment Interface

`m_box()` and `m_lid_part()` expose the box and lid as BOSL2 attachables, so
accessories can be placed against a named feature rather than a coordinate
expression.

```scad
Render_On_Include = false;   // or pass -D Render_On_Include=false
include <cable-box-parametric.scad>

m_box()
    attach("wall-back")
        my_bracket();
```

### `m_box(anchor, spin, orient)`

Defaults to `anchor=BOTTOM`, which reproduces the standard placement with the
box sitting on `z=0`. The declared envelope includes any Gridfinity base.

| Anchor | Where it is |
|---|---|
| standard `TOP`, `BOTTOM`, `LEFT`, `RIGHT`, `FRONT`, `BACK` | the outer bounding volume |
| `"floor"` | interior floor surface, pointing up |
| `"rim"` | top of the wall, pointing up |
| `"wall-front"`, `"wall-back"`, `"wall-left"`, `"wall-right"` | inner face of that wall at floor level, pointing into the interior |
| `"post-top"` | top of the centre post, pointing up |

### `m_lid_part(anchor, spin, orient)`

| Anchor | Where it is |
|---|---|
| `"lid-face"` | the face that ends up **exposed** when the box is closed, pointing away from the lid |
| `"lip"` | the free edge of the engagement lip, a skirt or a plug, which meets the box |

`"lid-face"` is worth understanding. The lid prints face-down: its engagement
lip points up, into the box, so the exposed face is the model's `z=0` face and
anything mounted on it grows downward. Getting this backwards is a real bug this
project has already shipped once, in the v1.2.0 Gridfinity lid interface. The
anchor exists so nobody has to re-derive it.

## Final Dispatcher

### `full_render()`

This is the only top-level renderer called at file end.

Behavior summary:

- If `Enable_Slicing=false`:
  - render unsliced box/lid by `Part_To_Render`
- If `Enable_Slicing=true` and `Slice_Piece_To_Render=0`:
  - preview all slices spaced by `Slice_Preview_Spacing`
- If `Enable_Slicing=true` and `Slice_Piece_To_Render>0`:
  - render only selected slice index

## Practical Change Guidance

When editing geometry, validate in this order:

1. `m_box_base()` and `m_lid()` produce valid unsliced solids
2. Side openings subtract correctly in `m_box_with_openings()`
3. Sliced paths still produce manifold outputs (`m_box_slice`, `m_lid_slice`)
4. Assertions still guard invalid states
5. Run smoke scripts after every behavior change

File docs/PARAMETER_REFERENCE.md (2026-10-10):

# Parameter Reference

This document is the canonical reference for every Customizer section and parameter in `cable-box-parametric.scad`.

## Scope and Source of Truth

- Model source: `cable-box-parametric.scad`
- Repository: `https://github.com/prisant-labs/3d-cable-box-parametric-openscad`
- License: `MIT`
- Third-party attribution: `THIRD_PARTY_NOTICES.md`

If this document and the SCAD file ever disagree, treat the SCAD file as the functional source and update this document.

## Conventions

- Units: millimeters unless stated otherwise.
- `0` as override value usually means "use default/global value".
- "Primary" alignment means along the arrangement axis.
- "Secondary" alignment means perpendicular to the arrangement axis.

## Section Index

1. Overall
2. Box
2a. Edge Treatment
3. Post
4. Lid
4a. Lid Relief
4b. Lid Magnets
5. Openings
6. Left Openings Overrides
7. Right Openings Overrides
8. Back Openings Overrides
9. Front Openings Overrides
10. Stabilizers - Main Settings
11. Stabilizers - Front/Back Walls
12. Stabilizers - Left/Right Walls
13. Bottom Openings - Main
14. Bottom Openings - Alignment
15. Bottom Openings - Custom Margins
16. Slicing - For Smaller Print Beds
17. Gridfinity
18. Printing
19. Hidden

## 1) Overall

| Parameter | Type | Default | Allowed values | Description | Notes |
|---|---|---:|---|---|---|
| `Part_To_Render` | enum | `"Box Only"` | `"Box Only"`, `"Lid Only"`, `"Box and Lid"` | Chooses which model body is generated. | In non-slicing mode, box and lid are separated in view for export. |

### `Part_To_Render` options

| Option | Behavior |
|---|---|
| `"Box Only"` | Renders only the box body. |
| `"Lid Only"` | Renders only the lid. |
| `"Box and Lid"` | Renders both bodies in one scene. |

## 2) Box

| Parameter | Type | Default | Description | Practical guidance |
|---|---|---:|---|---|
| `Box_Width` | number | `100` | Outer box width (X axis). | Increase for longer cable bundles or power bricks. |
| `Box_Depth` | number | `75` | Outer box depth (Y axis). | Increase for front/back routing space. |
| `Box_Height` | number | `50` | Outer box height (Z axis). | Set high enough for cable bend radius and connectors. |
| `Box_Corner_Radius` | number | `8.1` | Roundness of outer vertical edges. | Effective ceiling is `(min(Box_Width, Box_Depth) - Wall_Thickness*2) / 2`, set by the inner cavity rather than the outer shell. Larger values are clamped and reported via `echo`. |
| `Wall_Thickness` | number | `1.85` | Wall thickness for shell and post walling. | Typical FDM baseline: `1.2` to `2.4` depending nozzle/material. |

## 2a) Edge Treatment

Horizontal edges are square by default. These soften them. Both sizes default
to `0`, and at `0` the model renders exactly as it did before these existed.

| Parameter | Type | Default | Description | Practical guidance |
|---|---|---:|---|---|
| `Bottom_Edge_Fillet` | number | `0` | Size of the treatment on the box's outer bottom edge, in the shape `Bottom_Edge_Style` picks. | Around `1.0` softens the profile and visually absorbs elephant foot. Capped at `Wall_Thickness`, and ignored entirely when a Gridfinity base is active, because that profile is dimensioned by the standard. |
| `Bottom_Edge_Style` | enum | `"Fillet"` | Shape of that bottom edge: `"Fillet"`, `"Teardrop"`, or `"Chamfer"`. | `Fillet` is a quarter round, and its lowest layers overhang the bed, so keep it modest. `Teardrop` is a one-eighth round that ends in a 45 degree chamfer, so it keeps the rounded look and prints without an overhang. `Chamfer` is a plain 45 degree bevel. All three are `Bottom_Edge_Fillet` deep and tall, and only the box's bottom edge uses this setting. |
| `Top_Edge_Chamfer` | number | `0` | Chamfer on the box's top rim and on both exposed lid edges. | Around `0.6` takes the sharp edge off the rim you handle every time the lid comes off. Capped at `Wall_Thickness`, since the rim is only that wide. Ignored on the lid when a Gridfinity lid top is active. |

## 3) Post

| Parameter | Type | Default | Description | Interactions |
|---|---|---:|---|---|
| `Enable_Post` | boolean | `true` | Adds a center post for cable organization. | Affects bottom opening post-avoid behavior and lid post interface. |
| `Closed_Post` | boolean | `false` | Makes the post floor solid instead of open through the box bottom. | When `false` the post is a tube open at both ends. When `true` the bore starts above the floor, leaving a `Wall_Thickness` base. |
| `Post_Diameter` | number | `15` | Outer post diameter. | Also drives center clearance used by bottom post-avoid logic. |

## 4) Lid

| Parameter | Type | Default | Description | Tuning strategy |
|---|---|---:|---|---|
| `Lid_Style` | enum | `"Plug"` | `"Plug"` drops a ring just inside the box wall; `"Skirt"` wraps a wall around the outside of the box. | Plug keeps the lid's overhang as a finger grip, is notched around magnet bosses, and asserts if stabilizer fins or the post would reach it. Skirt touches nothing inside the box. |
| `Lid_Height` | number | `8.1` | Height of lid wall above top plane. | Increase for stronger lid walls and clip volume in sliced mode. |
| `Lid_Lip_Gap` | number | `0.15` | Clearance on each side between the lip and the box wall it fits against. Also opens the lid's post socket by the same amount. | Tight fit: reduce by `0.05`; loose fit: increase by `0.05`. The default fitted well with both lid styles on a Bambu Lab P1S printing PLA+. |
| `Lid_Lip_Gap_Height` | number | `3` | How far the lip, skirt or plug, reaches past the rim into the box. | Taller lip improves hold; too tall may increase insertion force. With a Plug, stabilizer fins must stop this far below the rim. |

The lid's footprint is `Box_Width + 2*(Wall_Thickness + Lid_Lip_Gap)` by
`Box_Depth + 2*(Wall_Thickness + Lid_Lip_Gap)` for both styles, which is
exactly a skirt's outside. A lip covers the top `Lid_Lip_Gap_Height` of any
side opening that runs to the rim.

## 4a) Lid Relief

A friction-fit lid has nothing to grip. These give the lid somewhere to be held.

| Parameter | Type | Default | Description | Practical guidance |
|---|---|---:|---|---|
| `Lid_Relief_Style` | string | `"None"` | `None`, `Scallop` or `Tab`. | `Scallop` is a concave groove in the lid's outer face: tidier, and it does not change the envelope. `Tab` is a protruding grip: more effective, and it widens the lid by `Lid_Relief_Depth` on each enabled side. |
| `Lid_Relief_Width` | number | `20` | Length of the relief along the wall. | Must stay clear of the rounded corners; the model asserts if it does not. |
| `Lid_Relief_Depth` | number | `2.5` | How far a scallop cuts in, or a tab stands out. | A scallop is a half cylinder, so this is both its depth and its half width; it must be under half of `Lid_Height`. |
| `Lid_Relief_On_Left` | boolean | `true` | Relief on the left wall. | Inert while `Lid_Relief_Style` is `None`. |
| `Lid_Relief_On_Right` | boolean | `true` | Relief on the right wall. | Mirrors the `Opening_On_*` convention. |
| `Lid_Relief_On_Front` | boolean | `false` | Relief on the front wall. | |
| `Lid_Relief_On_Back` | boolean | `false` | Relief on the back wall. | |

A side is skipped automatically when an opening on that wall reaches the box
rim. The relief is in the lid and openings are in the box, so they normally
cannot meet; a full-height opening is the exception, and a tab standing over a
hole grips nothing. The rim check uses the opening's real top edge, so it
counts that wall's `Move_Opening_*_Up` as well as `All_Openings_Up`.

`Lid_Relief_Width` is checked against each enabled wall's own length:
`Box_Width` for Front and Back, `Box_Depth` for Left and Right.

## 4b) Lid Magnets

| Parameter | Type | Default | Description | Practical guidance |
|---|---|---:|---|---|
| `Enable_Lid_Magnets` | boolean | `false` | Mating magnet pockets in the box and lid. | Held in bosses at the four inside corners, because the rim is only `Wall_Thickness` wide and a 6 mm magnet does not fit in it. Corners are also free of openings, stabilizers, the post and slice seams. |
| `Lid_Magnet_Diameter` | number | `6.2` | Pocket diameter. | Takes a nominal 6 mm magnet. Magnet diameters vary by supplier; increase if a press fit cracks the boss. |
| `Lid_Magnet_Depth` | number | `2.4` | Pocket depth in each half. | Each pocket takes its own magnet: one magnet per pocket, up to 2.4 mm thick at the default. The lid keeps material above its pocket, so the magnet is captured rather than visible. |
| `Lid_Magnet_Wall` | number | `1.2` | Material around each pocket. | Also sets the boss diameter, which is `Lid_Magnet_Diameter + 2 * Lid_Magnet_Wall`. |

**Insert the magnets with opposing poles facing.** The geometry is symmetric in
both axes so the pockets align however the lid is flipped onto the box, which
also means it cannot enforce polarity for you.

Bosses run the full box height rather than hanging from the rim, so they print
off the bed with no overhang and stiffen the corner.

## 5) Openings

| Parameter | Type | Default | Description | Interactions |
|---|---|---:|---|---|
| `All_Opening_Width` | number | `10` | Default opening width on enabled side walls. | Used unless side-specific width override is greater than `0`. |
| `All_Opening_Height` | number | `30` | Default opening height on enabled side walls. | Must be `> 0`, and `<= Box_Height` while any side opening is on. This is the true opening height; the cut is anchored at its bottom edge, not centered on the box floor. |
| `All_Opening_Corner_Radius` | number | `-1` | Default corner radius for side openings. | `-1` keeps fully rounded ends; `0` is square; positive values are clamped to valid half-extents. |
| `All_Opening_Top_Style` | enum | `"Round"` | Shape of each side opening's top: `"Round"` or `"Teardrop"`. | `Round` arcs flatten near the top, and that part prints as an overhang. `Teardrop` turns each rounded top corner into a 45 degree flank with a short flat cap, so the top prints without support. The opening keeps its typed width and height. The cap is about `0.41` times the width for fully rounded ends. A square opening is unchanged. Applies to all four walls. |
| `All_Openings_Right` | number | `0` | Global side-opening offset along each wall's local left/right direction. | Combines with each side-local `Move_Opening_*_to_Right` parameter. |
| `All_Openings_Up` | number | `5` | Height of each side opening's bottom edge above the box floor. | `0` sits the opening flush with the box bottom, so a cable resting on the desk passes straight in. Raise it to lift openings off the surface. Combines with side-specific vertical offsets. An opening lifted past the rim is cut open as a notch, and the model reports it with an `echo`. |
| `Opening_On_Right` | boolean | `true` | Enables right wall opening. | Uses global size unless right override is set. |
| `Opening_On_Left` | boolean | `true` | Enables left wall opening. | Uses global size unless left override is set. |
| `Opening_On_Front` | boolean | `true` | Enables front wall opening. | Uses global size unless front override is set. |
| `Opening_On_Back` | boolean | `true` | Enables back wall opening. | Uses global size unless back override is set. |

## 6) Left Openings Overrides

| Parameter | Type | Default | Description |
|---|---|---:|---|
| `Override_Opening_Width_Left` | number | `0` | Left opening width override; `0` keeps global width. |
| `Override_Opening_Height_Left` | number | `0` | Left opening height override; `0` keeps global height. |
| `Override_Opening_Corner_Radius_Left` | number | `-1` | Left opening corner radius override; `-1` keeps global corner radius. |
| `Move_Opening_Left_to_Right` | number | `0` | Left wall opening depth shift; positive moves toward front (`-Y`). |
| `Move_Opening_Left_Up` | number | `0` | Left opening vertical offset. |

## 7) Right Openings Overrides

| Parameter | Type | Default | Description |
|---|---|---:|---|
| `Override_Opening_Width_Right` | number | `0` | Right opening width override; `0` keeps global width. |
| `Override_Opening_Height_Right` | number | `0` | Right opening height override; `0` keeps global height. |
| `Override_Opening_Corner_Radius_Right` | number | `-1` | Right opening corner radius override; `-1` keeps global corner radius. |
| `Move_Opening_Right_to_Right` | number | `0` | Right wall opening depth shift; positive moves toward back (`+Y`). |
| `Move_Opening_Right_Up` | number | `0` | Right opening vertical offset. |

## 8) Back Openings Overrides

| Parameter | Type | Default | Description |
|---|---|---:|---|
| `Override_Opening_Width_Back` | number | `0` | Back opening width override; `0` keeps global width. |
| `Override_Opening_Height_Back` | number | `0` | Back opening height override; `0` keeps global height. |
| `Override_Opening_Corner_Radius_Back` | number | `-1` | Back opening corner radius override; `-1` keeps global corner radius. |
| `Move_Opening_Back_to_Right` | number | `0` | Back wall opening lateral shift; positive moves toward left (`-X`). |
| `Move_Opening_Back_Up` | number | `0` | Back opening vertical offset. |

## 9) Front Openings Overrides

| Parameter | Type | Default | Description |
|---|---|---:|---|
| `Override_Opening_Width_Front` | number | `0` | Front opening width override; `0` keeps global width. |
| `Override_Opening_Height_Front` | number | `0` | Front opening height override; `0` keeps global height. |
| `Override_Opening_Corner_Radius_Front` | number | `-1` | Front opening corner radius override; `-1` keeps global corner radius. |
| `Move_Opening_Front_to_Right` | number | `0` | Front wall opening lateral shift; positive moves toward right (`+X`). |
| `Move_Opening_Front_Up` | number | `0` | Front opening vertical offset. |

## 10) Stabilizers - Main Settings

| Parameter | Type | Default | Description | Interactions |
|---|---|---:|---|---|
| `Enable_Stabilizers` | boolean | `true` | Enables interior support fins. | If `false`, all stabilizer parameters are ignored. |
| `Stabilizer_Width` | number | `1.5` | Fin thickness along wall direction. | Increasing count and width together can reduce usable interior area. |
| `Stabilizer_Depth` | number | `15` | Fin extension from wall into interior. | Larger values add stiffness but can obstruct cable routing. |
| `Stabilizer_Height` | number | `35` | Fin height from floor upward. | Keep below full box height if upper interior clearance is needed. With the default Plug lid, fins must stop `Lid_Lip_Gap_Height` below the rim. |

## 11) Stabilizers - Front/Back Walls

| Parameter | Type | Default | Allowed values | Description |
|---|---|---:|---|---|
| `Stabilizers_Front_Back_Count` | integer | `3` | `0+` | Number of fins on each of front and back walls. |
| `Stabilizers_Front_Back_Alignment` | enum | `"Centered"` | `"Centered"`, `"Distributed"`, `"Custom"` | Placement strategy for front/back fins. |
| `Stabilizer_FB_Spacing` | number | `3` | `>= 0` | Gap between adjacent front/back fins in `Centered` and `Custom` modes. |
| `Stabilizer_FB_Margin_Left` | number | `15` | any | Left margin used in `Distributed` and `Custom`. |
| `Stabilizer_FB_Margin_Right` | number | `15` | any | Right margin used in `Distributed` and `Custom`. |
| `Stabilizer_Avoid_Front_Opening` | boolean | `true` | true/false | Skips front-wall fin positions that overlap opening area. |
| `Stabilizer_Avoid_Back_Opening` | boolean | `true` | true/false | Skips back-wall fin positions that overlap opening area. |

### `Stabilizers_Front_Back_Alignment` options

| Option | Behavior |
|---|---|
| `"Centered"` | Builds a centered fin cluster using `Stabilizer_FB_Spacing`. |
| `"Distributed"` | Distributes fins between left/right margins. |
| `"Custom"` | Starts from the custom start margin and uses fixed pitch (`Stabilizer_Width + Stabilizer_FB_Spacing`) when it fits; otherwise falls back to distributed placement inside margins. |

## 12) Stabilizers - Left/Right Walls

| Parameter | Type | Default | Allowed values | Description |
|---|---|---:|---|---|
| `Stabilizers_Left_Right_Count` | integer | `0` | `0+` | Number of fins on each of left and right walls. |
| `Stabilizers_Left_Right_Alignment` | enum | `"Centered"` | `"Centered"`, `"Distributed"`, `"Custom"` | Placement strategy for left/right fins. |
| `Stabilizer_LR_Spacing` | number | `3` | `>= 0` | Gap between adjacent left/right fins in `Centered` and `Custom` modes. |
| `Stabilizer_LR_Margin_Front` | number | `15` | any | Front margin used in `Distributed` and `Custom`. |
| `Stabilizer_LR_Margin_Back` | number | `15` | any | Back margin used in `Distributed` and `Custom`. |
| `Stabilizer_Avoid_Left_Opening` | boolean | `true` | true/false | Skips left-wall fin positions that overlap opening area. |
| `Stabilizer_Avoid_Right_Opening` | boolean | `true` | true/false | Skips right-wall fin positions that overlap opening area. |

### `Stabilizers_Left_Right_Alignment` options

| Option | Behavior |
|---|---|
| `"Centered"` | Builds a centered fin cluster using `Stabilizer_LR_Spacing`. |
| `"Distributed"` | Distributes fins between front/back margins. |
| `"Custom"` | Starts from the custom start margin and uses fixed pitch (`Stabilizer_Width + Stabilizer_LR_Spacing`) when it fits; otherwise falls back to distributed placement inside margins. |

## 13) Bottom Openings - Main

| Parameter | Type | Default | Allowed values | Description | Interactions |
|---|---|---:|---|---|---|
| `Enable_Bottom_Openings` | boolean | `false` | true/false | Enables floor cutouts in the box bottom. | If `false`, all bottom opening params are ignored. |
| `Bottom_Openings_Count` | integer | `3` | `1+` recommended | Number of floor openings. | With post avoid enabled, count is split across both sides of post. |
| `Bottom_Opening_Axis` | enum | `"Along X"` | `"Along X"`, `"Along Y"` | Axis used to arrange opening sequence. | Defines which margins are primary vs secondary. |
| `Bottom_Opening_Width` | number | `15` | any positive | Short dimension of each opening. | Combined with orientation to derive actual X/Y footprint. |
| `Bottom_Opening_Depth` | number | `30` | any positive | Long dimension of each opening. | Combined with orientation to derive actual X/Y footprint. |
| `Bottom_Opening_Orientation` | enum | `"Along Y"` | `"Along X"`, `"Along Y"` | Rotates opening shape independent of arrangement axis. | Allows slot rotation without changing arrangement direction. |
| `Bottom_Opening_Corner_Radius` | number | `5` | `>= 0` | Rounding radius for opening corners. | Effective radius is clamped to opening half-extents. |
| `Bottom_Opening_Spacing` | number | `0` | `0+` | Gap between neighboring openings. | `0` enables auto-spacing from alignment mode. |

### `Bottom_Opening_Axis` options

| Option | Behavior |
|---|---|
| `"Along X"` | Places multiple openings across box width. |
| `"Along Y"` | Places multiple openings across box depth. |

### `Bottom_Opening_Orientation` options

| Option | Behavior |
|---|---|
| `"Along X"` | Rotates each opening so long axis points along X. |
| `"Along Y"` | Rotates each opening so long axis points along Y. |

## 14) Bottom Openings - Alignment

| Parameter | Type | Default | Allowed values | Description |
|---|---|---:|---|---|
| `Bottom_Opening_Alignment_Primary` | enum | `"Centered"` | `"Centered"`, `"Distributed"`, `"Start"`, `"End"`, `"Custom"` | Placement mode on arrangement axis. |
| `Bottom_Opening_Alignment_Secondary` | enum | `"Centered"` | `"Centered"`, `"Start"`, `"End"`, `"Custom"` | Placement mode on perpendicular axis. |
| `Bottom_Opening_Avoid_Post` | boolean | `true` | true/false | Splits and offsets openings around post when `Enable_Post=true`. |
| `Bottom_Opening_Post_Margin` | number | `2` | `>= 0` | Minimum gap from post outer wall to nearest opening edge when post avoidance is enabled. |

### `Bottom_Opening_Alignment_Primary` options

| Option | Behavior |
|---|---|
| `"Centered"` | Centers total opening pattern in available area. |
| `"Distributed"` | Evenly distributes openings between computed bounds. |
| `"Start"` | Anchors pattern to start bound (left/front depending axis). |
| `"End"` | Anchors pattern to end bound (right/back depending axis). |
| `"Custom"` | Uses custom margins as explicit primary bounds. |

### `Bottom_Opening_Alignment_Secondary` options

| Option | Behavior |
|---|---|
| `"Centered"` | Centers openings on perpendicular axis. |
| `"Start"` | Anchors openings to start side using relevant margin. |
| `"End"` | Anchors openings to end side using relevant margin. |
| `"Custom"` | Centers the opening line within the custom margin window (left/right or front/back based on axis). |

## 15) Bottom Openings - Custom Margins

| Parameter | Type | Default | Description | Used by |
|---|---|---:|---|---|
| `Bottom_Opening_Margin_Left` | number | `10` | Distance from inner left wall. | `Along X` primary (`Start`/`Custom`), `Along Y` secondary (`Start` and `Custom` window). |
| `Bottom_Opening_Margin_Right` | number | `10` | Distance from inner right wall. | `Along X` primary (`End`/`Custom`), `Along Y` secondary (`End` and `Custom` window). |
| `Bottom_Opening_Margin_Front` | number | `10` | Distance from inner front wall. | `Along Y` primary (`Start`/`Custom`), `Along X` secondary (`Start` and `Custom` window). |
| `Bottom_Opening_Margin_Back` | number | `10` | Distance from inner back wall. | `Along Y` primary (`End`/`Custom`), `Along X` secondary (`End` and `Custom` window). |

## 16) Slicing - For Smaller Print Beds

| Parameter | Type | Default | Description | Constraints and notes |
|---|---|---:|---|---|
| `Enable_Slicing` | boolean | `false` | Enables split-part generation with mating clips. | Recommended when full width exceeds printable bed area. |
| `Slice_Count` | integer | `2` | Number of slices across width. | Must be `>= 2` for meaningful slicing. |
| `Slice_Piece_To_Render` | integer | `0` | `0` previews all pieces; non-zero renders one specific slice index. | Must be an integer in range `0..Slice_Count`. |
| `Clip_Tolerance` | number | `0.2` | Clearance added to female clip geometry. | Increase if clips are too tight. |
| `Clips_Per_Edge` | integer | `2` | Number of clips along each split edge. | Higher values improve alignment but add assembly friction. |
| `Clip_Tab_Width` | number | `10` | Clip extent along split edge. | Increase for strength; reduce if edge space is limited. |
| `Clip_Tab_Depth` | number | `4` | Clip insertion depth. | Deeper clips improve retention but may over-constrain fit. |
| `Clip_Tab_Height` | number | `3` | Clip tab height. | Larger values increase engagement force. Floor clips start at the floor's bottom face, so anything above `Wall_Thickness` rises inside the box rather than hanging below the piece. |
| `Slice_Preview_Spacing` | number | `5` | Gap between pieces in all-slices preview. | Visual layout only; does not affect exported single-part geometry. Snap clips add their travel on top, so pieces never touch in the preview. |
| `Clip_Style` | enum | `"Tab"` | `"Tab"` is the original friction fit; `"Snap"` is a BOSL2 cantilever snap clip. | See the snap clip section below. |
| `Seam_Tooth_Depth` | number | `3` | Depth of the 45 degree sawtooth cut through the walls at each seam. The teeth stop joined pieces sliding vertically. `0` gives a flat seam. | Must be `>= 0`, and less than half a slice width minus `Clip_Tolerance`. See the seam teeth section below. |

### Seam teeth (`Seam_Tooth_Depth`)

Above the floor, each seam zigzags at 45 degrees through the walls, the post,
and any fin it crosses. The teeth have no undercut, so the pieces still push
together along X, the way the floor clips go in. Once joined, the teeth stop
the pieces sliding vertically, and the floor clips stop them sliding along the
seam. Pulling the pieces apart is resisted only by a Snap clip or by glue.

- The tooth period is twice the depth: 6 mm at the default 3 mm.
- The two pieces' profiles sit `Clip_Tolerance` apart, measured along X. That
  gap is also the most a joined pair can move vertically.
- Through the floor the seam stays flat, so the floor clips keep their
  positions. A Gridfinity base is also cut flat.
- Where a front or back opening crosses a seam, the teeth stop at the
  opening's height range, because teeth there would leave slivers against its
  rounded edges. On the default box the seam crosses both openings, so the
  teeth run 15 mm above them and about 3 mm below.
- On the lid, teeth run through the slab below the band the lid's seam clips
  occupy. A front or back lid relief on the seam keeps the lid's seam flat.
- Every tooth face is at most 45 degrees from vertical, so the pieces print
  without supports.

### Slice rendering behavior

| `Slice_Piece_To_Render` value | Result |
|---|---|
| `0` | Renders all slices in a preview layout. |
| `1..Slice_Count` | Renders only the selected slice index (box and/or lid based on `Part_To_Render`). |

### Snap clips (`Clip_Style = "Snap"`)

The original `"Tab"` clip is a rectangle in a slightly larger rectangular hole,
held by friction. `Clip_Tolerance` is its only tuning knob and it trades "will
not go in" against "falls apart" with nothing in between.

`"Snap"` uses a real cantilever clip with an engagement bump. The arm flexes, so
it absorbs print inaccuracy instead of jamming, and the bump resists pull-out
rather than relying on interference.

| Parameter | Type | Default | Description |
|---|---|---:|---|
| `Clip_Snap_Length` | number | `8` | How far the clip travels into its socket. **Must exceed `Clip_Tab_Width / 2`**; below that the arm has no room to flex and the geometry cannot be built. |
| `Clip_Snap` | number | `0.4` | Depth of the engagement bump. Larger holds harder and is harder to separate. |
| `Clip_Arm_Thickness` | number | `1.0` | Arm thickness, which sets stiffness. Too thin snaps off; too thick will not flex. |
| `Clip_Compression` | number | `0.1` | Extra width on the ears for a tighter fit. |
| `Clip_Lock` | boolean | `false` | Makes the joint effectively permanent once assembled. |

Under `"Snap"`, `Clip_Tab_Width` becomes the clip's base width, `Clip_Tab_Height`
its extrusion depth, and `Clip_Tolerance` the clearance added to the socket.
`Clip_Tab_Depth` is not used; snap clips need their own travel, which is what
`Clip_Snap_Length` provides.

The default is deliberately still `"Tab"`. Clip geometry is the one part of this
model whose correctness cannot be established by rendering it: manifoldness,
solid counts, and probes all pass for a joint far too tight to assemble or too
loose to hold. `"Snap"` becomes the default once a print says it should.

## 17) Gridfinity

Two independent, optional interfaces that let the box join a Gridfinity setup.
Both default to off and change no geometry when disabled.

| Parameter | Type | Default | Description | Interactions |
|---|---|---:|---|---|
| `Enable_Gridfinity_Bottom` | boolean | `false` | Adds solid Gridfinity feet under the box, built to the spec's profile, so it drops into a 42 mm baseplate. | Rounds the footprint up to whole cells (see below), and the lid grows with it. Mutually exclusive with `Enable_Bottom_Openings`. Requires `Closed_Post=true` when the post is enabled. Adds `4.75 mm` to total height. |
| `Enable_Gridfinity_Lid_Top` | boolean | `false` | Adds a Gridfinity baseplate to the lid's exposed face: a plate with sockets, so bins or another box sit on the closed box. | Adds `4.75 mm` to lid height. |
| `Gridfinity_Profile_Clearance` | number | `0.25` | Fit clearance on the lid-top sockets, and on every magnet pocket and screw hole. | The feet need none: a spec foot already leaves `0.25 mm` all round in a spec pocket. Increase if lid sockets are tight. |
| `Gridfinity_Edge_Keepout` | number | `4` | Margin from the lid edge before the first lid-top cell. | Prevents thin, fragile cells at the lid's perimeter. The base ignores it, because its feet fill the rounded footprint. |
| `Enable_Gridfinity_Magnet_Screw` | boolean | `false` | Adds magnet pockets to whichever interfaces are enabled; the bottom base also gets screw holes. The lid gets pockets only, because a through screw hole would breach the closed box. Lid pockets open at each socket floor. | Foot pockets open on the foot's bottom face, so magnets go in after printing. |
| `Gridfinity_Magnet_Diameter` | number | `6.25` | Magnet diameter the pockets are cut for. | Each pocket adds `Gridfinity_Profile_Clearance`, so the default gives the spec's `6.5 mm` pocket for a `6 mm` magnet. |
| `Gridfinity_Magnet_Depth` | number | `2.4` | Magnet pocket depth. | In a foot, two bridging layers, each `Print_Layer_Height` tall, sit above the pocket, so the depth can be at most `4.75 - 2 * Print_Layer_Height`: `4.35 mm` at the default. In the lid, capped so `0.8 mm` of material always remains above the pocket. |
| `Gridfinity_Screw_Diameter` | number | `3.2` | Through screw hole diameter. | Sized for M3, and adds `Gridfinity_Profile_Clearance`. In a foot it runs up to the box's underside, and the floor above stays closed. |

### How the base is laid out

With `Enable_Gridfinity_Bottom` on, the footprint rounds up to whole cells.
`Box_Width` and `Box_Depth` each become the smallest `(N - 1) * 42 + 41.5` mm
that is at least the typed value, which is the outside of `N` spec feet. The
model echoes the size it built when that differs from what you typed:

```
ECHO: "Gridfinity base: box footprint rounded up to 125.5 x 83.5 mm (3 x 2 cells) from Box_Width x Box_Depth = 100 x 75"
```

The default `100 x 75` footprint therefore becomes `125.5 x 83.5`, a 3 x 2
grid. Rounding up costs no baseplate area. A box wider than its feet would
overhang them, and on a baseplate that overhang blocks the neighbouring cells
anyway.

Every foot is solid. Where the box corner is rounder than a foot's `3.75 mm`
corner, as at the default `Box_Corner_Radius` of `8.1`, the four corner feet are
trimmed to the box's outline. They are then smaller than a spec foot, which a
baseplate still accepts.

The lid top keeps the older layout: as many whole cells as fit inside the lid
less `Gridfinity_Edge_Keepout` on each side, centred.

### Height convention

The base is **added below** the box, not carved out of the floor. `Box_Height`
continues to describe the box body, so enabling Gridfinity never silently
reduces interior volume; it increases total height instead. The model is lifted
so the exported object still sits on `z=0`.

### Why `Closed_Post` is required

With an open post, the bore runs through the box floor. A Gridfinity base under
that floor would block it, leaving a bore that goes nowhere. Rather than
silently produce that, the model asserts. Set `Closed_Post=true`, or disable the
post.

## 18) Printing

| Parameter | Type | Default | Description | Interactions |
|---|---|---:|---|---|
| `Print_Layer_Height` | number | `0.2` | The layer height you slice at. | Today only the two bridging steps above each Gridfinity foot's magnet pocket read it. Each step is one layer tall. A slicer samples each layer near its middle height, so a step shorter than your real layers can fall between samples and vanish, and the pocket's ceiling then sags. Set it to your layer height. Checked only when `Enable_Gridfinity_Bottom` and `Enable_Gridfinity_Magnet_Screw` are both on: it must be above `0` and at most `0.6 mm`. |

## 19) Hidden

| Parameter | Type | Default | Description |
|---|---|---:|---|
| `Model_Version` | string | current release | Echoed at render so an exported STL can be traced back to its source. |
| `Render_On_Include` | boolean | `true` | Set `false` to use the file as a library: modules and anchors become available without geometry appearing. See the attachment section in `MODULE_REFERENCE.md`. |
| `$fn` | integer | `40` | Circle/arc resolution for cylinders and rounded geometry. |
| `GF_*` | various | Gridfinity spec | Gridfinity standard dimensions (pitch, the foot's footprint and profile, socket sizes, hole offsets). Hidden because changing one produces a part that no longer mates with other Gridfinity gear, but still overridable with `-D` if you need to. |
| `SPACER` | number | `0.04` | Internal modeling offset used for robust boolean operations and tiny clearances. |

## Built-In Validation

The model enforces these assertions. `docs/VALIDATION_RULES.md` explains each one
and how to resolve it.

Box and wall:

- `Box_Width`, `Box_Depth`, and `Box_Height` must be `> 0`.
- `Wall_Thickness` must be `> 0` and `Wall_Thickness*2` must be less than `min(Box_Width, Box_Depth)`.
- `Box_Corner_Radius` must be `>= 0`.
- With `Bottom_Edge_Fillet` above `0`, `Bottom_Edge_Style` must be `Fillet`,
  `Teardrop`, or `Chamfer`.

Post:

- `Post_Diameter` must exceed `Wall_Thickness*2` so the post has a wall.
- `Post_Diameter` must be less than `min(Inner_Width, Inner_Depth)`.

Lid:

- `Lid_Style` must be `Skirt` or `Plug`.
- With `Lid_Style=Plug`, the interior must hold two `Wall_Thickness` ring walls plus `Lid_Lip_Gap` on each side.
- With `Lid_Style=Plug` and stabilizers on, `Stabilizer_Height + Wall_Thickness` must not exceed `Box_Height - Lid_Lip_Gap_Height`.
- With `Lid_Style=Plug` and the post on, `Post_Diameter/2 + Lid_Lip_Gap` must not reach the plug ring's inside face.

Stabilizers:

- `Stabilizer_Height + Wall_Thickness` must not exceed `Box_Height`.
- `Stabilizer_Depth*2` must be less than `min(Inner_Width, Inner_Depth)`.
- `Stabilizer_Width` must be `> 0`.
- Stabilizer counts must be `>= 0`.
- `Stabilizer_FB_Spacing` and `Stabilizer_LR_Spacing` must be `>= 0`.

Openings:

- `All_Opening_Height` and `All_Opening_Width` must both be `> 0`.
- `All_Opening_Height` must not exceed `Box_Height`.
- Side opening width/height overrides must be `>= 0`.
- Opening corner radius defaults/overrides must be `>= -1`.
- While any side opening is on, `All_Opening_Top_Style` must be `Round` or
  `Teardrop`.

Bottom openings:

- `Bottom_Openings_Count` must be `>= 1` when bottom openings are enabled.
- `Bottom_Opening_Width` and `Bottom_Opening_Depth` must be `> 0` when enabled.
- `Bottom_Opening_Post_Margin` must be `>= 0`.

Slicing and clips:

- `Slice_Piece_To_Render` must be an integer in range `0..Slice_Count`.
- When slicing is enabled, `Slice_Count` must be `>= 2`.
- When slicing is enabled, `Clips_Per_Edge` must be `>= 1`.
- `Clip_Tolerance` must be `>= 0`.
- `Clip_Tab_Width`, `Clip_Tab_Depth`, and `Clip_Tab_Height` must be greater than `0`.
- When slicing is enabled, `Seam_Tooth_Depth` must be `>= 0`, and
  `Seam_Tooth_Depth + Clip_Tolerance` must be less than half a slice width.
- When slicing is enabled and the lid-top Gridfinity interface is not active,
  `Lid_Height` must be at least `Clip_Tab_Height` plus 0.04 mm, so the lid's
  seam clips stay inside the lid.

Gridfinity:

- `Enable_Gridfinity_Bottom` cannot be combined with `Enable_Bottom_Openings`,
  and it requires `Closed_Post=true` when the post is on.
- With the base and magnets on, `Print_Layer_Height` must be above `0` and at
  most `0.6 mm`.
- With the base and magnets on, `Gridfinity_Magnet_Depth` must be `> 0` and at
  most `4.75 - 2 * Print_Layer_Height` (`4.35 mm` at the default), so the
  pocket and its two bridging layers fit inside a foot.

## Clamped Rather Than Asserted

`Box_Corner_Radius` is clamped instead of rejected, because a too-large radius
has an obvious correct interpretation (round the corners as much as the geometry
allows). When clamping occurs the model emits an `echo` naming the requested and
the applied value, so the difference is visible in the OpenSCAD console.

The footprint under a Gridfinity base is rounded up the same way, with an
`echo` naming the typed and the built size. See "How the base is laid out"
above.

## Recommended Baseline Profiles

### General-purpose desktop cable box

- `Box_Width=120`
- `Box_Depth=80`
- `Box_Height=55`
- `Wall_Thickness=1.8`
- `Lid_Lip_Gap=0.15`
- `Enable_Post=true`

### Power-brick-heavy setup

- `Box_Width=160`
- `Box_Depth=100`
- `Box_Height=60`
- `All_Opening_Width=14`
- `All_Opening_Height=36`
- `Enable_Stabilizers=true`
- `Stabilizers_Front_Back_Count=4`

### Small print bed fallback

- `Enable_Slicing=true`
- `Slice_Count=3`
- `Slice_Piece_To_Render=1` (export each slice individually)
- `Clip_Tolerance=0.25` (start conservative, tune after test print)

## Documentation Maintenance Rules

When parameters are added, removed, renamed, or default values change:

1. Update this file in the same commit as SCAD changes.
2. Update `docs/FAQ.md` if behavior impact is likely user-visible.
3. Update `README.md` if workflow or folder structure changes.

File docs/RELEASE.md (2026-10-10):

# Release Checklist

A version here promises something specific: the same parameters produce the same
geometry. See [E-10 (versioning)](internal/E-10_versioning.md) for what each
level of bump means. The steps below exist because a version that lies makes a
bug report untraceable.

## Before you start

Set `OPENSCADPATH` if this machine has more than one BOSL2 install, or OpenSCAD
may silently load a stale copy and the renders will not match CI:

```bash
export OPENSCADPATH="$HOME/Documents/OpenSCAD/libraries"
```

Confirm which one is being used before trusting any output.

## 1. Decide the level

- **Patch** - a fix that leaves geometry unchanged for every existing parameter
  set. Metadata, docs, and generated artifacts count here.
- **Minor** - new parameters or features whose defaults leave existing geometry
  untouched.
- **Major** - the same parameter set now renders differently. Changing a default
  is a major bump, even when the new default is better.

## 2. Bump the version

- [ ] `Model_Version` in `cable-box-parametric.scad`.
- [ ] Add the matching `## [x.y.z] - YYYY-MM-DD` section to `CHANGELOG.md`.
      `scripts/check-version.sh` reads the topmost released section, so put the
      new one at the top.

## 3. Regenerate everything that embeds the version

Three artifacts carry `Model_Version` and are generated, so they go stale
silently:

```bash
python scripts/regen_missing_bosl2_fixture.py    # tests/fixtures/missing_bosl2.scad
python scripts/build_bundle.py                   # dist/ standalone bundle + sidecar
python scripts/build_library.py                  # presets, renders, GLBs, indexes
```

`build_library.py` is slow because it re-renders STLs. Use `--no-stl` when only
metadata or renders changed. It reports how many renders it wrote versus left
alone; unchanged renders are deliberately not rewritten, because OpenSCAD's
rasteriser is not byte-deterministic and would otherwise dirty every image.

Two more generators do not embed the version, but they go stale the same way.
Rerun them when default geometry or the preview palette changes:

```bash
python scripts/build_options_guide.py            # docs/images/options/ + options-guide.html
python scripts/build_readme_images.py            # README hero and feature images
```

- [ ] Regenerate whichever apply, and check `git status` matches expectations.
- [ ] If a preset's parameters changed, rebuild without `--no-stl`.

## 4. Verify

```bash
bash scripts/check-version.sh      # scad, changelog and tag must agree
python tests/run_tests.py          # full geometry suite
```

- [ ] Version consistency check passes.
- [ ] Test suite passes.
- [ ] Preview still draws. The suite renders only through CGAL, so it cannot
      see the F5 preview. Export a preview PNG of a feature-heavy box, with
      magnets, Gridfinity feet, and teardrop openings on, and confirm that it
      shows the box. An `intersection()` inside a repeated cutter once pushed
      preview past OpenSCAD's 100,000-element limit and drew an empty scene:

      ```bash
      openscad -o /tmp/preview.png cable-box-parametric.scad \
        -D 'Enable_Gridfinity_Bottom=true' -D 'Closed_Post=true' \
        -D 'Enable_Gridfinity_Magnet_Screw=true' -D 'Enable_Lid_Magnets=true' \
        -D 'All_Opening_Top_Style="Teardrop"'
      ```
- [ ] Docs reflect any parameter or behaviour change
      (`PARAMETER_REFERENCE.md`, `FAQ.md`, `README.md`).
- [ ] Licence and third-party notices current (`THIRD_PARTY_NOTICES.md`).
- [ ] For a major or minor bump, validate one physical print for fit and wall
      integrity. Clip geometry in particular cannot be validated by rendering:
      manifoldness and solid counts pass for a joint far too tight to assemble.

## 5. Tag and publish

A workflow does this now, not a person with a zip tool. Human judgement stays
in two places: deciding the tag, and reading the drafted notes before anyone
else can.

- [ ] Merge the release pull request, so `main` carries everything being
      released and has passed CI.
- [ ] Tag `main` with an annotated tag: `git tag -a vX.Y.Z -m "..."` (or
      `vX.Y.Z-rc.N` for a release candidate).
- [ ] Push the tag: `git push origin vX.Y.Z`.
- [ ] Watch the `release` workflow run. It repeats the version check, the
      geometry suite, and the standalone-bundle render, then packages the
      assets below and opens a **draft** release with generated notes
      attached. Nothing is public at this point.
- [ ] Open the draft and read the notes. `scripts/release_notes.py` writes
      them from `CHANGELOG.md`; see "Promoting a release candidate to final"
      below for what it does differently on a candidate versus a final tag.
      Edit the notes if a reader who was not in the room needs more context
      than the changelog prose gives.
- [ ] Confirm the attached assets match the list below, then publish.

You can dry-run the workflow without tagging anything, from the Actions tab:
`workflow_dispatch` takes a `tag` input and runs every step except creating
the release itself.

### Release assets

`scripts/package_release.py` builds these and the workflow attaches them to
the draft:

- `cable-box-parametric.scad` - requires BOSL2.
- `cable-box-parametric.json` - all nine presets' parameter sets, for the
  Customizer.
- `cable-box-standalone-bundle.zip` - the bundle plus its `builtins.scad`
  sidecar, which must stay in the same folder, plus a short `README.txt`
  saying so.
- `cable-box-presets.zip` - every preset's `config.json`, `notes.md`, and its
  three STLs (box, lid, box-and-lid). Earlier releases attached two sample
  STLs by hand and the other seven presets had none; this replaces that with
  all nine, every time.

### Promoting a release candidate to final

A candidate tag (`vX.Y.Z-rc.N`) and the final tag (`vX.Y.Z`) read
`CHANGELOG.md` differently, because a candidate ships before anyone has
folded its changes into a dated section.

- **Candidate notes** are stitched together: a header naming it a release
  candidate for `X.Y.Z` and saying further print validation would be helpful
  before the final release; then
  whatever is still in `[Unreleased]`, under "New in this candidate"; then
  the `[X.Y.Z]` section if one exists, both under one heading, "Full X.Y.Z
  changelog so far". `[Unreleased]` can span several candidates, so the
  script cannot know what is new since the previous one.
- **Before publishing a candidate**, add a short "What's new since rc.N"
  summary at the top of the draft, by hand. Readers of a candidate mostly
  want that, and only a person can judge it.
- **Final notes** are just the `[X.Y.Z]` section, verbatim.
  `scripts/release_notes.py` refuses to write them while `[Unreleased]` still
  has entries, because a final release that leaves work behind in
  `[Unreleased]` is a release whose own notes lost part of it.

Before tagging a final release:

- [ ] Move every entry out of `[Unreleased]` and into the `[X.Y.Z]` section,
      merging with whatever earlier candidates already put there.
- [ ] Set that section's date to the real release date, replacing the
      placeholder.
- [ ] Confirm `Model_Version` in `cable-box-parametric.scad` still reads
      `X.Y.Z`. Promotion changes the changelog, not the version.
- [ ] Tag `vX.Y.Z`. Both `scripts/check-version.sh` and
      `scripts/release_notes.py` now read a changelog with nothing left in
      `[Unreleased]`.

## 6. Snapshot

```bash
bash scripts/backup-release.sh vX.Y.Z
```

- [ ] Writes `_local/backup/vX.Y.Z/` and refreshes the mirror. Local only, never
      committed. Git and the Releases page are the authoritative archive; this
      covers losing access to GitHub itself.

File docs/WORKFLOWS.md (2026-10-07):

# Workflows and Tuning Guide

This guide focuses on repeatable workflows for configuring, printing, and validating the parametric cable box.

## 1) Quick Start Workflow

1. Open `cable-box-parametric.scad` in OpenSCAD.
2. Open Customizer (`Window -> Customizer`, or `F3`).
3. Configure dimensions in sections: `Overall`, `Box`, `Post`, `Lid`, and `Openings`.
4. Press `F6` (full render).
5. Export STL for the current `Part_To_Render` value.
6. Repeat for `Box Only` and `Lid Only` if needed.

### Starting from a preset instead of the defaults

`cable-box-parametric.json` sits beside the model and carries all nine presets,
so the Customizer's preset dropdown lists them as soon as the model is open.
Pick the closest one and adjust from there rather than starting from scratch.

From the command line:

```bash
openscad -o out.stl cable-box-parametric.scad \
  -p cable-box-parametric.json -P desk-compact
```

This is OpenSCAD's native parameter-set format, so a set saved from the
Customizer can be loaded straight back in, or sent to someone else, or attached
to a bug report.

## 2) Dimensional Planning Workflow

Before changing parameters, measure:

- Largest cable connector width and height.
- Cable bend radius requirement near wall openings.
- Power brick footprint (if stored inside).
- Mounting/placement envelope on desk, shelf, or wall.

Translate measurements:

- `Box_Width` and `Box_Depth` from footprint plus clearance.
- `Box_Height` from tallest interior object plus routing margin.
- `All_Opening_Width` from thickest cable/connector dimension plus slack.
- `All_Opening_Height` from number of cables per wall and routing spread.

## 3) Lid Fit Calibration Workflow

### Objective
Achieve a consistent, repeatable friction fit across your printer/material profile.

### Steps

1. Start with the default `Lid_Lip_Gap=0.15`, a clearance on each side, and
   choose `Lid_Style` (`Skirt` or `Plug`) before you tune it.
2. Print a [fit test box](PRINTING.md#fit-test-box), or a draft pair, at
   final layer height and wall count.
3. Test fit after cooling to room temperature.
4. If too tight, increase by `0.05`.
5. If too loose, decrease by `0.05`.
6. Re-test until desired fit is reached.
7. Record your final value per filament type.

### Typical ranges

- PLA: `0.10` to `0.20`
- PETG: `0.15` to `0.30`
- ABS/ASA: `0.20` to `0.35`

Use these as starting points only. They are not measured, and since 2.0.0
the value is per side rather than a total.

## 4) Side Opening Workflow

### Baseline pattern

1. Set global values: `All_Opening_Width`, `All_Opening_Height`.
2. Enable walls using `Opening_On_*` toggles.
3. Use `All_Openings_Right` and `All_Openings_Up` for global shifts.

### Per-side refinement

1. Set side override width/height (`Override_Opening_*`) only when needed.
2. Use side-local offsets (`Move_Opening_*`) for asymmetry.
3. Keep overrides at `0` when global values are sufficient.

### Validation checklist

- Confirm openings do not intersect rounded corners too aggressively.
- Verify opening height still satisfies model assertion (`height > width` globally).
- Verify opening placement does not conflict with stabilizer zones unless intended.

## 5) Stabilizer Workflow

### When to enable

Use stabilizers when:

- Box walls are tall/thin.
- Internal loads are non-trivial.
- Opening cutouts remove too much wall stiffness.

### Configuration sequence

1. Enable `Enable_Stabilizers=true`.
2. Set geometry: `Stabilizer_Width`, `Stabilizer_Depth`, `Stabilizer_Height`.
3. Configure front/back count and alignment.
4. Configure left/right count and alignment.
5. Enable opening avoidance toggles for affected walls.

### Practical tuning

- Increase count before increasing depth for less interior intrusion.
- Keep depth moderate if routing many cables internally.
- Use `Distributed` with margins to avoid corner crowding.

## 6) Bottom Openings Workflow

### Strategy

Define geometry first, then placement.

1. Set `Enable_Bottom_Openings=true`.
2. Set geometry: width, depth, orientation, corner radius.
3. Choose arrangement axis (`Bottom_Opening_Axis`).
4. Choose primary/secondary alignments.
5. Set spacing (`0` for auto, or explicit value).
6. Apply margins for `Start`, `End`, or `Custom` modes.

### Post interaction

If center post is enabled and `Bottom_Opening_Avoid_Post=true`, openings are split around the post clearance region. This overrides centered behavior for post-safe placement.

## 7) Slicing Workflow (Small Print Beds)

### Use case

Enable slicing when full box/lid dimensions exceed your print bed width.

### Steps

1. Set `Enable_Slicing=true`.
2. Set `Slice_Count` to fit your bed dimensions.
3. Keep `Slice_Piece_To_Render=0` to preview all slices.
4. Switch `Slice_Piece_To_Render` to each index and export STLs one at a time.
5. Print and test one mating seam before full production.

### Clip tuning

- Tight assembly: increase `Clip_Tolerance` by `0.05`.
- Loose assembly: decrease `Clip_Tolerance` by `0.05`.
- Weak seam: increase `Clips_Per_Edge` or `Clip_Tab_Width`.
- Pieces slide vertically: keep `Seam_Tooth_Depth` above `0`, so the wall
  teeth lock them level. `Clip_Tolerance` also sets the teeth's clearance.

## 8) Printing Baseline

### Suggested starting profile (FDM)

- Nozzle: `0.4`
- Layer height: `0.2`
- Perimeters/Walls: `3+`
- Infill: `15%` to `25%`
- Top/Bottom layers: `4+`

### Orientation

- Box: open side up.
- Lid: top cosmetic surface orientation based on visual preference.
- Sliced parts: orient to maximize seam accuracy and clip strength.

## 9) CI Smoke Workflow

### GitHub Actions

- Workflow file: `.github/workflows/scad-smoke.yml`
- Trigger: push affecting `.scad` files or manual dispatch
- Runs OpenSCAD smoke renders on Ubuntu

### Local

- Windows: run `scripts/scad-smoke.ps1`
- Linux/macOS: run `bash scripts/scad-smoke.sh`
- If needed on Bash environments, set `OPENSCAD_BIN` to your OpenSCAD executable path.

Smoke checks include:

- Baseline render
- Lid-only render
- Slicing preview render
- Expected fail case (`Slice_Piece_To_Render` out of range while slicing is enabled)

## 10) Troubleshooting Matrix

| Symptom | Likely cause | Action |
|---|---|---|
| Lid too tight | `Lid_Lip_Gap` too low | Increase by `0.05` and re-test. |
| Lid too loose | `Lid_Lip_Gap` too high | Decrease by `0.05` and re-test. |
| Side openings misaligned | Global + local offsets stacking | Reset one offset layer, then reapply intentionally. |
| Stabilizers intersect opening area | Avoid toggles disabled or margins too small | Enable avoid toggles and/or increase margins. |
| Floor openings collide with post | Post avoid disabled | Set `Bottom_Opening_Avoid_Post=true`. |
| Slice clips too hard to join | `Clip_Tolerance` too low | Increase tolerance incrementally. |
| Slice clips sloppy | `Clip_Tolerance` too high | Reduce tolerance and reprint seam test. |

## 11) Documentation and Contribution Workflow

When you add or change parameters:

1. Update `cable-box-parametric.scad` comments.
2. Update `docs/PARAMETER_REFERENCE.md`.
3. Update `docs/FAQ.md` for new troubleshooting cases.
4. Update `README.md` if user workflow changes.
5. If sharing user-generated builds or forks, place them in `community/`.

Do not hand-add files to `library/`. Everything there is generated: add an entry
to `PRESETS` in `scripts/build_library.py` and rerun it, which regenerates that
preset's `config.json`, STLs, GLB previews, renders and notes, plus
`library/README.md`, the machine-readable `library/index.json`, and the merged
`cable-box-parametric.json`. Hand-edited files there are overwritten on the next
build, and the point of generating them is that a preset cannot drift from the
model.

`library/index.json` is what the docs site's preset browser reads. It records
each preset's overrides and printed envelope, and the model's full parameter
defaults once at the top, so the effective parameter set is the defaults with
the overrides applied. It carries a `schema` number; bump `INDEX_SCHEMA` in
`scripts/build_library.py` when its shape changes incompatibly, and the site
refuses a version it does not know rather than rendering it wrong.

The GLB previews need [trimesh](https://trimesh.org) (`pip install trimesh`).
It is optional: without it the conversion is skipped with a note and everything
else builds normally. Skip it with `--no-glb`.

The conversion canonicalises each mesh before writing it. OpenSCAD emits the
same geometry in a different facet order on every run, so a straight conversion
produced a different GLB each rebuild and dirtied 27 tracked binaries that had
not changed. Sorting vertices and faces into one defined order removes that
exactly, which is why an unchanged model reconverts to byte-identical files.

It then rotates the mesh from Z-up into glTF's Y-up convention. OpenSCAD models
the printed object Z-up, sitting on the bed at z=0, and trimesh writes vertices
through unchanged, so without the rotation every preview lies on its back in a
viewer. The STLs are unaffected and stay Z-up, which is what a slicer wants; the
rotation exists only in the GLB.

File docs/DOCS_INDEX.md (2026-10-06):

# Documentation Index

Every page in the documentation set and every generated file beside it, with
one line on what each covers, so you can find the right page before you open
one.

- `index.md`: Site landing page for the docs site and local builds.
- `OPTIONS_GUIDE.md`: Every parameter rendered from the model, with images.
- `options-guide.html`: The same guide as one self-contained file that works offline.
- `PARAMETER_REFERENCE.md`: Complete section-by-section and variable-by-variable parameter reference.
- `MODULE_REFERENCE.md`: Module-by-module geometry reference and render flow.
- `SCAD_ARCHITECTURE.md`: Core architecture, data flow, and coordinate-system details.
- `VALIDATION_RULES.md`: Assertion constraints, triggers, and resolution guidance.
- `PARAMETER_INTERACTIONS.md`: Cross-parameter behavior and tuning order.
- `WORKFLOWS.md`: Practical setup, calibration, slicing, and troubleshooting workflows.
- `PRINTING.md`: Printing-specific baseline settings and process guidance,
  including Gridfinity, magnets, edge treatment, and the fit test box.
- `FAQ.md`: Common questions and issue resolution.
- `RELEASE.md`: Release checklist, from version bump through the drafted
  GitHub release that `.github/workflows/release.yml` creates from a tag.
- `../library/README.md`: The nine presets, what each fits, and their sizes.
  The same catalogue with 3D previews and downloads is the
  [preset library](../library/), which resolves to the browser on the docs site
  and to the generated directory when browsing the repository.
- `../library/index.json`: The catalogue as data, generated alongside the
  presets. Each preset's overrides, printed envelope, feature flags and file
  paths, plus the model's full parameter defaults once at the top.
- `../cable-box-parametric.json`: All nine presets as one OpenSCAD parameter-set
  file, so the Customizer lists them when the model is opened. Generated.
- `../web/astro.config.mjs`: Docs site navigation/config (Astro Starlight).
- `../web/sync-docs.mjs`: Syncs this directory into the site at build time, so
  `docs/` stays the single source of truth.
- `.github/workflows/docs-pages.yml`: GitHub Pages publish workflow.
- `.github/workflows/scad-smoke.yml`: GitHub Actions OpenSCAD smoke workflow.
- `scripts/scad-smoke.ps1` / `scripts/scad-smoke.sh`: Local smoke render scripts.

## Local Docs Preview

```bash
cd web
npm ci
npm run dev
```

Open `http://localhost:4321`.

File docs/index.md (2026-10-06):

# Ultimate Cable Box Documentation

This site documents the **primary model**: `cable-box-parametric.scad`.

It is intended to be as implementation-close as possible, so parameter behavior matches what the SCAD actually generates.

## Start Here

- [Parameter reference](PARAMETER_REFERENCE.md): every parameter, section by section
- [Options guide](OPTIONS_GUIDE.md): every option rendered, with images
- [Workflows](WORKFLOWS.md): practical setup and tuning
- [Printing](PRINTING.md): print recommendations and the fit test box
- [FAQ](FAQ.md): common issues and fixes

## Deep Technical Docs

- [Module reference](MODULE_REFERENCE.md): geometry and module breakdown
- [SCAD architecture](SCAD_ARCHITECTURE.md): data flow and render architecture
- [Validation rules](VALIDATION_RULES.md): assertion constraints and why they exist
- [Parameter interactions](PARAMETER_INTERACTIONS.md): high-impact parameter interactions

## Presets

The [preset library](../library/) is nine ready-to-print configurations, each
sized for something you already own. Every entry has an orbitable 3D view of
each part, the parameters that define it, and STL, GLB and `config.json`
downloads. Everything there is generated from the model, so a preset cannot
drift from it.

## Scope Notes

- This docs set describes the primary model at the repo root.
- Gridfinity (base and lid interfaces), snap-fit seam clips, and the preset
  library are part of the model and documented here. Features still awaiting
  physical print validation are marked as such where they appear.

## Local Build

The site is built with [Astro Starlight](https://starlight.astro.build/) from `web/`, which syncs its content from this directory at build time:

```bash
cd web
npm ci
npm run dev
```

Then open `http://localhost:4321`.

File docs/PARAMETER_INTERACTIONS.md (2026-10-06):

# Parameter Interactions

This page captures interactions that most affect model behavior and print outcomes.

## Side Openings

### Global vs per-side dimensions

- Global: `All_Opening_Width`, `All_Opening_Height`, `All_Opening_Corner_Radius`
- Per-side width/height overrides apply when override value is greater than `0`.
- Per-side corner-radius overrides apply when override value is `>= 0`.

Practical effect:

- Override set to `0` means "inherit global".

Corner-radius behavior:

- `All_Opening_Corner_Radius = -1` keeps fully rounded slot ends.
- Side override radius `>= 0` takes precedence (`0` square, `>0` rounded rectangle).

### Global and local offsets combine

Global offset terms are added to side-local terms, but axis semantics differ by wall.

Implication:

- If placement looks wrong, zero global offsets first and tune side-local offsets independently.

The vertical terms combine the same way. An opening's top edge is
`All_Openings_Up + Move_Opening_<wall>_Up + its height`. When that passes
`Box_Height`, the opening is cut open to the rim as a notch and the model
reports it with an `echo`. When it comes within `Wall_Thickness` of the rim,
the lid relief on that wall is skipped.

## Stabilizers and Side Openings

Opening-avoid toggles suppress stabilizers that would overlap opening zones:

- `Stabilizer_Avoid_Front_Opening`
- `Stabilizer_Avoid_Back_Opening`
- `Stabilizer_Avoid_Left_Opening`
- `Stabilizer_Avoid_Right_Opening`

Interaction risks:

- High fin counts + wide openings can remove many fins, making spacing appear irregular.

Tuning order:

1. Set opening sizes/positions
2. Set stabilizer count/alignment
3. Use avoid toggles
4. Adjust spacing (`Stabilizer_FB_Spacing`, `Stabilizer_LR_Spacing`) for `Centered`/`Custom`
5. Adjust margins

## Bottom Openings and Center Post

When both are enabled:

- `Enable_Post=true`
- `Enable_Bottom_Openings=true`
- `Bottom_Opening_Avoid_Post=true`
- Tune `Bottom_Opening_Post_Margin` for required clearance around the post.

Openings are split around center clearance.

Interaction risks:

- High opening count plus large post diameter can crowd one side.
- Orientation and axis combinations can make expected spacing non-intuitive.

## Bottom Axis vs Orientation

These are independent controls:

- `Bottom_Opening_Axis`: sequence direction
- `Bottom_Opening_Orientation`: opening rotation

Result:

- You can arrange along X while each slot is rotated along Y, and vice versa.

## Alignment + Margins

Primary and secondary alignments consume margins differently depending on axis.

Examples:

- `Along X`: left/right margins are primary bounds
- `Along Y`: front/back margins are primary bounds

## Slicing and Clip Fit

Key interaction group:

- `Clip_Tolerance`
- `Clip_Tab_Width`
- `Clip_Tab_Depth`
- `Clip_Tab_Height`
- `Clips_Per_Edge`

Behavior:

- Larger tolerance loosens fit.
- More clips improve registration but increase insertion/removal force and cumulative fit error.

Recommended tuning sequence:

1. Keep default clip dimensions
2. Tune `Clip_Tolerance` first
3. Adjust `Clips_Per_Edge` second
4. Adjust tab geometry only if needed

## Slicing Preview vs Single Slice Export

- `Slice_Piece_To_Render = 0`: preview all slices
- `Slice_Piece_To_Render > 0`: exportable single index

Common mistake:

- Exporting with `0` when intent was one printable part.

## Lid Fit Parameters

- `Lid_Style` chooses whether the lip wraps the outside of the box (`Skirt`) or drops inside the wall (`Plug`)
- `Lid_Lip_Gap` controls mating clearance on each side, for both styles and for the post socket
- `Lid_Lip_Gap_Height` and `Lid_Height` affect engagement and rigidity

Interaction pattern:

- Tightening `Lid_Lip_Gap` may require small increases in height or stronger cooling control for consistent fit.
- A Skirt fits against the box's outside face and a Plug against its inside face, so the same `Lid_Lip_Gap` can feel different between them on one printer. Tune each with its own fit test box.
- With `Lid_Style=Plug`, the ring is notched around `Enable_Lid_Magnets` bosses, and `Stabilizer_Height` and `Post_Diameter` must leave it room; the model asserts otherwise.
- Any side opening that runs to the rim loses its top `Lid_Lip_Gap_Height` under a seated lid, with either style.

## Post and Lid

With `Enable_Post=true`, both box and lid include post-interface geometry.

Interaction implications:

- `Post_Diameter` affects center clearance and mating geometry.
- `Closed_Post` modifies box post cavity behavior but does not remove lid-side post logic.

## Edge Treatment and Gridfinity

Key interaction group:

- `Bottom_Edge_Fillet`
- `Top_Edge_Chamfer`
- `Enable_Gridfinity_Bottom`
- `Enable_Gridfinity_Lid_Top`

Behavior:

- A Gridfinity interface owns the face it sits on, and its profile is
  dimensioned by the Gridfinity standard. Softening that perimeter would move a
  mating surface, so the treatment is suppressed there rather than applied and
  hoped for.
- Suppression is gated on whether an interface actually rendered, not on the
  `Enable_` parameter. A box too small for even one 42 mm cell renders no base,
  and keeps its fillet.
- The box bottom and the lid's exposed face are the two suppressed cases. The
  box rim is never suppressed, because no Gridfinity feature touches it.

## Lid Relief and Side Openings

Key interaction group:

- `Lid_Relief_Style`, `Lid_Relief_On_*`
- `All_Opening_Height`, `Override_Opening_Height_*`, `All_Openings_Up`

Behavior:

- Relief is cut into the lid; openings are cut into the box. At default sizes
  they are nowhere near each other, so most configurations need no thought.
- They meet only when an opening runs to the box rim. Then the relief on that
  wall is dropped: a tab would stand over a hole and a scallop would open into
  it, and neither gives anything to grip.
- The skip is automatic and silent. If a relief you asked for is missing, check
  whether that wall's opening reaches the rim.

## Lid Magnets and Everything Else

Key interaction group:

- `Enable_Lid_Magnets`, `Lid_Magnet_Diameter`, `Lid_Magnet_Wall`
- `Post_Diameter`, `Enable_Slicing`, `Box_Corner_Radius`

Behavior:

- Magnets sit in bosses at the four inside corners. That placement is what keeps
  them clear of everything else: openings sit on wall centres, stabilizers carry
  end margins, the post is central, and slice seams sit at interior x.
- The only collisions left are with the post on a small box, and with the
  opposite corner on a very small one. Both assert rather than merging silently.
- `Box_Corner_Radius` does not need to accommodate the boss. The boss is pushed
  `WELD` into both walls, so it fuses whether or not the rounded corner reaches
  it.
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

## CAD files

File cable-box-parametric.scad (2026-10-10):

/*
Parametric Cable Management Box (OpenSCAD)
Repository: https://github.com/prisant-labs/3d-cable-box-parametric-openscad
License: MIT
SPDX-License-Identifier: MIT

See README.md for usage, docs/PARAMETER_REFERENCE.md for full parameter docs,
and THIRD_PARTY_NOTICES.md for third-party attributions.
*/

// Requires BOSL2: https://github.com/BelfrySCAD/BOSL2
// Install it into your OpenSCAD library folder, or use the single-file bundle
// attached to each GitHub Release, which has BOSL2 inlined and needs nothing.
// BOSL2 is BSD-2-Clause; see THIRD_PARTY_NOTICES.md.
include <BOSL2/std.scad>
include <BOSL2/joiners.scad>

// Fail early and legibly when BOSL2 is missing.
//
// Without this, a missing library produces "Can't open include file" followed by
// a wall of "Ignoring unknown module" warnings, no geometry, and exit code 0.
// Nothing in that says what to install, and the zero exit makes it look like it
// worked. BOSL_VERSION comes from BOSL2 itself, so its absence is the signal.
assert(!is_undef(BOSL_VERSION),
       "BOSL2 is not installed, and this model needs it. Either install BOSL2 into your OpenSCAD library folder (see the README), or download the standalone bundle attached to any release, which has BOSL2 inlined and needs nothing.");

/*[Overall]*/
// Which model output to render.
Part_To_Render = "Box Only"; //["Box Only", "Lid Only", "Box and Lid"]

/*[Box]*/
// Outer width of the box body (mm).
Box_Width = 100;
// Outer depth of the box body (mm).
Box_Depth = 75;
// Outer height of the box body (mm).
Box_Height = 50;
// Corner radius for outer box edges (mm). Clamped to what the inner cavity allows.
Box_Corner_Radius = 8.1;
// Wall thickness for box and post shell (mm).
Wall_Thickness = 1.85;

/*[Edge Treatment]*/
// Size of the treatment on the box's outer bottom edge (mm), in the shape
// Bottom_Edge_Style picks. 0 keeps the hard 90 degree edge. Softens the profile
// and visually absorbs elephant foot.
// Ignored when Enable_Gridfinity_Bottom is on, because the base owns that edge.
Bottom_Edge_Fillet = 0;
// Shape of that bottom edge. Fillet is a quarter round, whose lowest layers
// overhang the bed, so keep it modest. Teardrop keeps the round look but meets
// the bed at 45 degrees. Chamfer is a plain 45 degree bevel.
Bottom_Edge_Style = "Fillet"; //["Fillet", "Teardrop", "Chamfer"]
// Chamfer on the box's top rim and on both exposed lid edges (mm). 0 keeps the
// hard edge. The rim is what you handle every time the lid comes off.
Top_Edge_Chamfer = 0;

/*[Post]*/
// Add a center post for cable wrapping.
Enable_Post = true;
// If true, the post floor is solid instead of open through the box bottom.
Closed_Post = false;
// Outer diameter of the center post (mm).
Post_Diameter = 15;

/*[Lid]*/
// How the lid locates on the box. Plug drops a ring just inside the box wall
// and leaves the lid's edge overhanging as a finger grip; it is notched around
// magnet bosses, and stabilizer fins must stop below it. Skirt wraps a short
// wall around the outside of the box. Both are friction fits tuned with
// Lid_Lip_Gap.
Lid_Style = "Plug"; //["Plug", "Skirt"]
// Thickness of the lid's flat panel (mm). The lip stands Lid_Lip_Gap_Height
// above it.
Lid_Height = 8.1;
// Clearance on each side between the lid's lip and the box wall it fits
// against (mm). Increase if the fit is tight. The lid's post socket gets the
// same clearance.
Lid_Lip_Gap = 0.15;
// How far the lip, skirt or plug, reaches past the rim into the box (mm).
Lid_Lip_Gap_Height = 3;

/*[Lid Relief]*/
// Finger purchase in the lid edge, so a tight lid comes off without a tool.
// Scallop is a concave groove, tidier. Tab is a protruding grip, more
// effective. None keeps the current geometry.
Lid_Relief_Style = "None"; //["None", "Scallop", "Tab"]
// Length of the relief along the wall (mm).
Lid_Relief_Width = 20;
// How far a scallop cuts in, or a tab stands out (mm).
Lid_Relief_Depth = 2.5;
// Which walls carry it. A side is skipped automatically when an opening on that
// wall reaches the box rim, because the two would meet there.
Lid_Relief_On_Left = true;
Lid_Relief_On_Right = true;
Lid_Relief_On_Front = false;
Lid_Relief_On_Back = false;

/*[Lid Magnets]*/
// Magnet retention between box and lid, in four bosses at the inside corners.
// Corners because the rim is only Wall_Thickness wide and a magnet does not fit
// it, and because corners are free of openings, stabilizers, the post and slice
// seams by construction rather than by avoidance logic.
// Magnets must be inserted with opposing poles facing; the geometry is
// symmetric and cannot enforce that for you.
Enable_Lid_Magnets = false;
// Magnet pocket diameter (mm). 6.2 takes a nominal 6 mm magnet.
Lid_Magnet_Diameter = 6.2;
// Pocket depth in each half (mm). Two of these stack when the box is closed.
Lid_Magnet_Depth = 2.4;
// Material around each pocket (mm), which also sets the boss diameter.
Lid_Magnet_Wall = 1.2;

/*[Openings]*/
// Default opening width for all enabled side openings (mm).
All_Opening_Width=10;
// Default opening height for all enabled side openings (mm).
All_Opening_Height=30;
// Default corner radius for all side openings (mm). Use -1 for fully rounded ends.
All_Opening_Corner_Radius=-1;
// Shape of each side opening's top. Round arcs near the top print as an
// overhang. Teardrop turns each rounded top corner into a 45 degree flank with a
// short flat cap, so it prints without support; the opening keeps its typed
// width and height. A square opening (corner radius 0) is unchanged.
All_Opening_Top_Style="Round"; //["Round", "Teardrop"]
// Global side-opening offset along each wall's local left/right direction (mm).
All_Openings_Right=0;
// Height of each side opening's bottom edge above the box floor (mm). 0 sits it flush with the box bottom.
All_Openings_Up=5;
Opening_On_Right=true;
Opening_On_Left=true;
Opening_On_Front=true;
Opening_On_Back=true;

/*[Left Openings Overrides]*/
// Left opening width override (mm). Use 0 to keep default width.
Override_Opening_Width_Left=0;
// Left opening height override (mm). Use 0 to keep default height.
Override_Opening_Height_Left=0;
// Left opening corner radius override (mm). Use -1 to keep default corner radius.
Override_Opening_Corner_Radius_Left=-1;
// Left wall opening depth shift (mm). Positive moves toward front (-Y).
Move_Opening_Left_to_Right=0;
// Left opening vertical offset (mm).
Move_Opening_Left_Up=0;

/*[Right Openings Overrides]*/
// Right opening width override (mm). Use 0 to keep default width.
Override_Opening_Width_Right=0;
// Right opening height override (mm). Use 0 to keep default height.
Override_Opening_Height_Right=0;
// Right opening corner radius override (mm). Use -1 to keep default corner radius.
Override_Opening_Corner_Radius_Right=-1;
// Right wall opening depth shift (mm). Positive moves toward back (+Y).
Move_Opening_Right_to_Right=0;
// Right opening vertical offset (mm).
Move_Opening_Right_Up=0;

/*[Back Openings Overrides]*/
// Back opening width override (mm). Use 0 to keep default width.
Override_Opening_Width_Back=0;
// Back opening height override (mm). Use 0 to keep default height.
Override_Opening_Height_Back=0;
// Back opening corner radius override (mm). Use -1 to keep default corner radius.
Override_Opening_Corner_Radius_Back=-1;
// Back wall opening lateral shift (mm). Positive moves toward left (-X).
Move_Opening_Back_to_Right=0;
// Back opening vertical offset (mm).
Move_Opening_Back_Up=0;

/*[Front Openings Overrides]*/
// Front opening width override (mm). Use 0 to keep default width.
Override_Opening_Width_Front=0;
// Front opening height override (mm). Use 0 to keep default height.
Override_Opening_Height_Front=0;
// Front opening corner radius override (mm). Use -1 to keep default corner radius.
Override_Opening_Corner_Radius_Front=-1;
// Front wall opening lateral shift (mm). Positive moves toward right (+X).
Move_Opening_Front_to_Right=0;
// Front opening vertical offset (mm).
Move_Opening_Front_Up=0;

/*[Stabilizers - Main Settings]*/
// Add wall fins for extra rigidity.
Enable_Stabilizers = true;
// Fin thickness along the wall (mm).
Stabilizer_Width = 1.5;
// Fin depth from wall into the box interior (mm).
Stabilizer_Depth = 15;
// Fin height from box floor upward (mm).
Stabilizer_Height = 35;
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

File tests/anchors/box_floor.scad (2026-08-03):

// The "floor" anchor must land on the interior floor surface, pointing up, so a
// marker attached to it sits inside the box rather than under it or on the rim.
include <../../cable-box-parametric.scad>

m_box()
    attach("floor")
        cuboid([20, 20, 10]);

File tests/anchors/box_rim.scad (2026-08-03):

// The "rim" anchor must land on top of the wall, so a marker sits above the box.
include <../../cable-box-parametric.scad>

m_box()
    attach("rim")
        cuboid([20, 20, 10]);

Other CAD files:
tests/anchors/lid_face.scad
tests/assembly/gridfinity_seated.scad
tests/assembly/lid_seated.scad
tests/assembly/slices_joined.scad
tests/fixtures/missing_bosl2.scad

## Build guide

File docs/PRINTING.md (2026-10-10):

# Printing Guide

Settings, orientation, and fit tuning for printing the box and lid, plus the
small calibration prints that check a fit before you commit to a full box.

## Baseline FDM Settings

- Nozzle: `0.4 mm`
- Layer height: `0.20 mm`
- Walls/perimeters: `3+`
- Top/bottom layers: `4+`
- Infill: `15%` to `25%`
- Material: PLA or PETG recommended for first-fit calibration

## Orientation

- Box: print it as exported, open top facing up.
- Lid: print it as exported. The lid turns over in use, so the face on the bed
  becomes the top of the closed box and gets the bed's finish. The lip, the
  magnet pockets, and the post socket all face up and print without support.
- Sliced parts: print each piece as exported, so the seam faces stay vertical
  and the clips keep their designed dimensions.

## Fit Test Box

A small box made with your own settings checks a fit before you spend the
filament on a full box. Start from your configuration and change only the
size and the extras:

- `Box_Width=50`, `Box_Depth=50`, `Box_Height=12`, and `Lid_Height=4`
- `Enable_Post=false`, `Enable_Stabilizers=false`, and every `Opening_On_*`
  set to `false`
- `Part_To_Render="Box and Lid"`, so both parts export together

Keep every value that affects the fit: `Wall_Thickness`, `Box_Corner_Radius`,
`Lid_Style`, `Lid_Lip_Gap`, and `Clip_Tolerance`.

To test one feature, turn on only that feature. Use `Enable_Lid_Magnets=true`
for the magnets. For a seam, use `Box_Width=80`, `Box_Height=15`,
`Enable_Slicing=true`, `Slice_Count=2`, and `Slice_Piece_To_Render=0`, which
exports both halves side by side. For Gridfinity, test a one-cell box against
real Gridfinity parts: set `Box_Width=41.5` and `Box_Depth=41.5`, because the
base rounds a 50 mm box up to 2 x 2 cells.

## Fit Calibration Procedure

1. Print a [fit test box](#fit-test-box), or one full box and lid pair, in
   the target material and with your usual settings.
2. Test the fit after the parts cool fully.
3. Adjust `Lid_Lip_Gap` by `0.05 mm` increments.
4. Repeat until the fit is right, then use the same value for the real box.

The default `Lid_Lip_Gap` of `0.15 mm` fitted well with both lid styles, with
and without magnets, on a Bambu Lab P1S printing PLA+.

## Slicing Mode Print Procedure

1. Enable slicing and choose `Slice_Count`.
2. Export each piece with `Slice_Piece_To_Render=1..Slice_Count`.
3. Print one seam pair first: a two-slice [fit test box](#fit-test-box), or
   the two pieces that share a seam.
4. Tune `Clip_Tolerance` by `0.05 mm` as needed. It sets the clearance of
   both the clips and the seam teeth.
5. Print the full set only after the seam fits.
6. Push the pieces together along the seam. The teeth hold them level, and the
   floor clips hold them in line. For a permanent box, put cyanoacrylate glue
   on the tooth faces before joining; the 45 degree faces give about 1.4 times
   the glue area of a flat seam.

Every piece sits flat on its floor, so sliced pieces print without support.
The seam teeth are at most 45 degrees from vertical, so they need no support
either.
Releases up to and including 2.0.0-rc.4 centred each male floor clip on the
floor, and 0.575 mm of it hung below the piece. A slicer then stood the whole
piece on its clips. Re-export any sliced pieces from those releases.

## Side Openings

- Round tops, the default, flatten near the top of each arc, and that part
  prints as an overhang anchored on one side. It spans about 1.5 mm of height
  at the default 10 mm width, and about 3.5 mm at 24 mm.
- `All_Opening_Top_Style=Teardrop` turns each rounded top corner into a 45
  degree flank with a short flat cap, so the top prints without support. The
  opening keeps its typed width and height. The cap is a bridge about 0.41
  times the opening's width, 4 mm at the default, and slicers print a bridge
  anchored at both ends well.
- A square opening, `All_Opening_Corner_Radius=0`, already has a straight
  bridge for a top, so `Teardrop` leaves it unchanged.

## Gridfinity

- The box's feet are solid and stand on the bed. Their sides lean out at 45
  degrees or rise straight, so they need no support. Releases through
  2.0.0-rc.5 hollowed the base from below and left a 37 mm bridge in every
  cell.
- With the base on, the footprint rounds up to whole cells, so the box's walls
  stand directly on the outer feet and no ledge overhangs them. Releases
  through 2.0.0-rc.5 left a flat ledge of 4 mm or more around the base, which
  printed as loose loops without supports.
- Foot magnet pockets open onto the bed, so the magnets go in after printing.
  Above each pocket, two bridging layers carry the pocket's ceiling across the
  screw hole. Each is `Print_Layer_Height` tall, 0.2 mm by default. Set it to
  the layer height you slice at. A slicer samples each layer near its middle
  height, so a step shorter than your real layers can be skipped, which
  defeats the technique.
- The lid socket opens onto the bed when the lid prints as exported, so it
  needs no support. Its floor, about 37 mm across, prints as a bridge. In test
  prints that bridge sagged, and a sagging floor makes the socket shallower, so
  tune bridging here.
- The feet are built to the spec's numbers, and a spec foot leaves 0.25 mm all
  round in a spec baseplate pocket. Test a one-cell box against a real
  baseplate before a full box anyway.

## Magnets

- Pockets open at the box rim and at the lid's mating face, so both print
  facing up and the magnets go in after printing. No pause is needed.
- Each pocket takes one magnet: a nominal 6 mm disc up to 2.4 mm thick.
- Insert the magnets with opposing poles facing. The pockets are symmetric, so
  the model cannot enforce polarity. Glue one pair at a time and check that the
  pair attracts before the adhesive sets.
- If a press fit cracks a boss, raise `Lid_Magnet_Diameter` slightly or
  thicken `Lid_Magnet_Wall`.

## Edge Treatment

- With the default `Bottom_Edge_Style=Fillet`, `Bottom_Edge_Fillet` curves the
  box's bottom edge inward toward the bed, so its lowest layers overhang the
  bed slightly. Look at those layers on a small test box before you use a
  large fillet on a full box.
- `Bottom_Edge_Style=Teardrop` keeps the rounded look but finishes in a 45
  degree chamfer at the bed, so the first layers do not overhang.
  `Bottom_Edge_Style=Chamfer` is a plain 45 degree bevel, which also hides
  elephant's foot.
- `Top_Edge_Chamfer` faces up and prints without support.

## Common Print Quality Notes

- If walls feel weak, increase `Wall_Thickness` or perimeter count.
- If clips fracture, increase `Clip_Tab_Width` or use tougher material.
- If top corners warp (ABS/ASA), use enclosure and bed adhesion aids.
- If the tops of rounded openings droop, set `All_Opening_Top_Style=Teardrop`.
  If a square opening's top bridge sags, reduce bridge speed and increase
  cooling.

## Post-Processing

- Deburr opening edges lightly before cable routing.
- Dry-fit lid and seams before full cable load.
- If required, lightly sand mating features; avoid over-removal.

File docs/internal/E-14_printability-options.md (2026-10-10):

# E-14: Printability options

**Handle:** Printability options. Three opt-in parameters that remove the
overhangs a support-free print still has: the tops of the wall openings, the
bottom edge fillet, and the bridging layers in each Gridfinity foot.

**Status:** Implemented 2026-10-09 and shipped in `v2.0.0-rc.6`; waiting on
the rc.6 print round. Scoped 2026-10-08, and the maintainer accepted all five
decisions on 2026-10-09.
**Effort:** S to M, as three independent S parts.
**Depends on:** [E-12 (Gridfinity to spec)](E-12_gridfinity-to-spec.md)
phase A for part 14c. Ships inside 2.0.0 rather than as 2.1.0; the release
plan below says why.

## Why

Most of the model already prints without supports. The magnet bosses run up
from the floor, the seam teeth stay within 45 degrees of vertical, and E-12
phase A gave the box solid feet with 45 degree sides. A code read on
2026-10-08 found three places that still overhang, or that work only at one
slicer setting.

- **Side openings.** `m_opening` builds each opening as a hull of four
  circles. With the default fully rounded ends, the top of each opening is a
  semicircle. Near its top the arc is flatter than 45 degrees, over a height of
  `r * (1 - cos 45)`, about `0.29 * r`. That is 1.5 mm at the default 10 mm
  width and 3.5 mm at 24 mm, the widest preset opening. All nine presets use
  fully rounded ends, at widths from 12 to 24 mm. A slicer prints that part of
  the arc as an overhang anchored on one side, and that is where strands droop.
- **Bottom edge fillet.** `m_edge_treated_shell` sweeps `Bottom_Edge_Fillet`
  with `os_circle()`, so the fillet meets the bed almost horizontally.
  `docs/PRINTING.md` already warns that its lowest layers overhang the bed.
- **Gridfinity bridging.** Above each foot's magnet pocket, two stepped layers
  carry the pocket's ceiling. Their height is the hidden constant
  `GF_BRIDGE_LAYER = 0.2`. Slicers sample each layer near its middle height, so
  a 0.2 mm step can fall between the samples of a 0.28 mm layer. The slicer
  then drops that step, and the bridging no longer works. The Risks section
  says how the rc.1 print confirms this.

## Considered and dropped: a stabilizer slope guard

On 2026-10-08 a fourth part was proposed: an advisory echo when
`Stabilizer_Depth` exceeds `Stabilizer_Height`. The reasoning was that the fin
would then overhang past 45 degrees. That reasoning was wrong.
`m_stabilizer_fin` puts the full `Stabilizer_Depth` rectangle on the floor and
narrows to a line on the wall at the top. Each layer sits inside the layer
below it, so the sloped face points upward like a ramp. A shallow fin shows
visible steps on that face, but it never overhangs. No change is needed.

## Decisions (proposed 2026-10-08, accepted 2026-10-09)

The maintainer accepted all five as written.

1. **Every new parameter defaults to today's geometry.** The defaults are
   `"Round"`, `"Fillet"`, and `0.2`. Under
   [E-10 (versioning)](E-10_versioning.md), a parameter whose default preserves
   output is additive, a minor bump on its own. Inside 2.0.0 it therefore
   changes no existing preset.
2. **A teardrop opening keeps its typed height.** The flat cap sits exactly
   where the round top is today. Part 14a explains why.
3. **One global opening style, with no per-wall overrides.**
   [E-03 (openings array)](E-03_openings-array.md) replaces the per-wall
   opening block, so every per-wall parameter added now is one more that E-03
   has to migrate.
4. **The layer-height parameter gets a general name, `Print_Layer_Height`.**
   Today only the Gridfinity bridging reads it. A narrower name would need a
   rename when a second feature reads it, and a rename is a major bump.
5. **Default changes wait for E-03.** Making `Teardrop` the default changes
   output for unchanged inputs, which is a major bump. E-03 is already the
   planned major that breaks the opening interface, so the default changes
   there at no extra cost. The bottom edge default, if it changes, rides the
   same major release.

## 14a. Teardrop tops for side openings

**Parameter.** `All_Opening_Top_Style`, in the Openings tab, with the values
`["Round", "Teardrop"]` and the default `"Round"`.

**Shape.** `Round` is today's hull. `Teardrop` replaces each of the hull's two
top corner circles with a capped teardrop: the circle, two 45 degree flanks,
and a flat cap at the height of the circle's top. The two bottom circles stay
round, because the bottom of a hole needs no support.

| Opening | Top today | Top with `Teardrop` |
|---|---|---|
| Fully rounded, `r = w / 2` (the default) | A semicircle | Two 45 degree flanks and a flat cap `2 * (sqrt(2) - 1) * r` wide, about `0.41 * w` |
| Partial radius, `0 < r < w / 2` | Two quarter arcs and a straight bridge `w - 2 * r` wide | Two 45 degree flanks; the straight bridge grows to `w - 2 * r + 0.83 * r` |
| Square, `r = 0` | A straight bridge | Unchanged |

The flat cap is a bridge anchored at both ends, which slicers print well. At
the preset widths it is 5.0 mm wide at 12 mm and 9.9 mm wide at 24 mm.

**Why the cap stays at the typed height.** The teardrop stays inside the typed
width and height, so `opening_top(side)` does not change. Three things read
it:

- The rim-notch echo, which reports an opening whose top edge is above the
  rim.
- `opening_reaches_rim()`, which skips a lid relief on any wall whose opening
  reaches the rim.
- `box_seam_bands()`, where the E-13 (seam joints) teeth skip the height
  band, up to `opening_top(side)`, of any front or back opening that crosses a
  seam. Teeth through an opening would cut slivers against its edges.

A pointed teardrop would rise `(sqrt(2) - 1) * r` above the typed height,
about 5 mm at 24 mm wide. It would silently change which openings reach the
rim. A pointed teardrop that lowers its circle to keep the height was also
rejected. It removes the cap's bridge, but it narrows the upper part of the
opening that the user sized for cables.

**Build.** The two top corners are BOSL2 `teardrop(h, r, ang = 45, cap_h = r)`.
BOSL2's `teardrop()` extrudes along Y with its point toward +Z, which fits the
front and back walls. The left and right walls add `spin = 90`. The corners
are hulled with the two bottom `cyl()` corners, as today. The build uses no
`intersection()`, so preview's CSG tree stays small. Still export a preview
PNG of a box with all four openings set to `Teardrop`, because E-12 phase A
blanked the preview with a cutter that repeated for each hole.

**Openings this does not change.** An opening that reaches the rim is a notch,
so it has no top to change. Bottom openings lie on the bed, so they keep their
shape.

**Validation.** Assert that `All_Opening_Top_Style` is `"Round"` or
`"Teardrop"`, naming the parameter, in the style of the `Lid_Style` assert at
line 545.

**Tests.**

- `opening_top_teardrop_cuts_shoulders`: the default box with
  `All_Opening_Top_Style="Teardrop"`. For the default front opening, the top
  circle has `r = 5` and its centre at z = 30, and the cap is at z = 35. A probe
  in the front wall at x = 2.2 and z = 34.7 is outside the circle, 5.19 mm from
  its centre, and inside the flank, whose half-width there is 2.37. Expect
  empty; `Round` leaves material there, so the scenario fails against `main`.
  In the same scenario, a material probe at x = 0 and z = 35.2 proves that the
  cap did not rise.
- `opening_top_teardrop_partial_radius`: `All_Opening_Corner_Radius=3` on a
  20 mm opening. One shoulder probe at a top corner, worked out the same way.
- Both scenarios expect one solid.
- `validation_opening_top_style_unknown`: an unknown style fails and names
  the parameter.

As built, `m_opening` sinks every cut 0.04 mm (`SPACER`), so the scenarios
use a circle centre of 29.96 and a cap of 34.96, and probes with margins of
at least 0.06 mm.

## 14b. Bottom edge style

**Parameter.** `Bottom_Edge_Style`, next to `Bottom_Edge_Fillet`, with the
values `["Fillet", "Teardrop", "Chamfer"]` and the default `"Fillet"`.
`Bottom_Edge_Fillet` keeps its name and sets the size for every style. A
rename would be a major bump.

**Shape.** Each style is a bottom profile for the `offset_sweep()` calls in
`m_edge_treated_shell`, chosen by one helper function.

| Style | BOSL2 profile | Inset at the bed | Height |
|---|---|---|---|
| `Fillet` | `os_circle(r = Bottom_Edge_Fillet)`, as today | `r` | `r` |
| `Teardrop` | `os_teardrop(r = Bottom_Edge_Fillet)` | `2 * (1 - sqrt(2) / 2) * r`, about `0.59 * r` | `r` |
| `Chamfer` | `os_chamfer(width = Bottom_Edge_Fillet)` | `r` | `r` |

`os_teardrop` is a one-eighth arc down from the wall, followed by a 45 degree
chamfer to the bed. Above `0.29 * r` it matches the fillet, so it keeps the
rounded look. `Chamfer` also serves as elephant's-foot relief. Both functions
exist at the pinned `BOSL2_REF` (`afe82db`).

**Scope.** This changes only the box's bottom edge. The lid's slab is built
by the same `m_edge_treated_shell`, so the style is passed in as an argument
from the box's call only, and the lid keeps the default. A mesh comparison
with `Bottom_Edge_Style` set on a chamfered lid confirms that. As built, the
lid's exposed edge is a round of radius `Top_Edge_Chamfer`, not a chamfer;
[backlog item 21 (lid edge is round)](BACKLOG.md) records it. With the
Gridfinity base on,
`Bottom_Fillet_Effective` is 0, so every style is suppressed, as the fillet is
today. The existing asserts still bound every style, because each style's
inset and height are at most `r`: `Bottom_Edge_Fillet <= Wall_Thickness`, and
`Bottom_Edge_Fillet + Top_Edge_Chamfer < Box_Height`.

**Validation.** Assert that `Bottom_Edge_Style` is one of the three values,
naming the parameter. Gate the assert on `Bottom_Edge_Fillet > 0`, because the
style means nothing without a fillet.

**Tests.** At the default 1.85 mm wall, the fillet is capped at 1.85 mm, and
the differences between styles are only tenths of a millimetre. The scenarios
therefore set `Wall_Thickness=3` and `Bottom_Edge_Fillet=3`. The insets below
are measured in from the outer face, along a straight side.

- `bottom_edge_teardrop_meets_bed_at_45`: `Bottom_Edge_Style="Teardrop"`. At
  z = 0.05 to 0.1, the fillet's surface is 2.23 mm in and the teardrop's is
  1.66 mm in. A probe 1.9 to 2.0 mm in expects material, and it fails against
  `main`.
- `bottom_edge_chamfer`: `Bottom_Edge_Style="Chamfer"`. At z = 2.0, the
  fillet's surface is 0.17 mm in and the chamfer's is 1.0 mm in. A probe 0.3 to
  0.5 mm in expects empty, and it fails against `main`.
- Both scenarios expect one solid. A sliced `Teardrop` piece was checked by
  hand for one solid.
- `validation_bottom_edge_style_unknown`: an unknown style with a fillet set
  fails and names the parameter.

## 14c. Print layer height for the Gridfinity bridging

**Parameter.** `Print_Layer_Height`, default `0.2`, in a new Printing tab
placed just before the Hidden section. Its comment says: "The layer height you
slice at. Today only the two bridging steps above each Gridfinity foot's
magnet pocket read it."

**Change.** `Print_Layer_Height` replaces `GF_BRIDGE_LAYER` at every use: the
constant at line 342, the magnet-depth assert at lines 659 to 662, and
`m_gridfinity_bottom_holes` at lines 1749 to 1763. The constant is then
removed. E-12 phase B adds no stepped bridges, according to its plan. If phase
B does need one, it uses the same constant, so that this rename stays
mechanical.

**The rule for users.** Each step must be at least one real layer tall, so the
slicer samples it at least once. Setting `Print_Layer_Height` to the layer
height you slice at meets that rule. A larger value also works, at the cost of
a thicker step. A smaller value can lose a step.

**Validation.** Gate both checks on `Enable_Gridfinity_Bottom` and
`Enable_Gridfinity_Magnet_Screw`, because nothing else reads the value yet.

- `Print_Layer_Height` must be greater than 0 and at most 0.6 mm. A 0.6 mm
  layer is 75 percent of a 0.8 mm nozzle, the largest common size.
- The existing depth assert becomes
  `Gridfinity_Magnet_Depth + 2 * Print_Layer_Height <= GF_BASE_HEIGHT`, and
  its message names both parameters.

**Tests.**

- `gridfinity_bridge_steps_follow_layer_height`: the Gridfinity base with
  magnets and `Print_Layer_Height=0.28`. Measured up from the foot's bottom,
  the slot step spans 2.40 to 2.68 mm and the square step 2.68 to 2.96 mm. Put
  a probe inside the slot's footprint but outside the square's, 2.2 mm from the
  hole centre along the slot, at z = 2.62 to 2.66. It expects empty. At 0.2 mm
  that height falls in the square step and is material, so the scenario fails
  against `main`.
- `validation_print_layer_height_zero`: `Print_Layer_Height=0` with the
  Gridfinity base and magnets on. It expects exit code 1 and a message naming
  `Print_Layer_Height`.
- `validation_gridfinity_magnet_depth_too_deep` keeps passing, because its
  message still names `Gridfinity_Magnet_Depth`.

## Acceptance criteria

- [x] Each new scenario fails against `main` before its part lands, as
      `AGENTS.md` requires. All eight failed first, for the predicted reason.
- [x] With every new parameter at its default, every part is mesh-identical
      to `main` under the canonical comparison. Eleven configurations were
      checked: the seven E-12 phase A used, the Gridfinity feet with magnets,
      a chamfered lid with and without `Bottom_Edge_Style` set, and square
      openings under `Teardrop`. The full library build wrote 0 renders and
      left 28 alone, and its 27 rewritten STLs were canonically identical.
- [x] Every non-default style exports as one solid, sliced and unsliced.
- [x] A preview PNG of a box with four `Teardrop` openings, Gridfinity feet,
      and both kinds of magnets shows the box, with a normalized tree of 127
      elements. `docs/RELEASE.md` step 4 now carries this check.
- [x] The same change updates `docs/VALIDATION_RULES.md`,
      `docs/PARAMETER_REFERENCE.md`, `docs/PRINTING.md`, `docs/FAQ.md`,
      `docs/MODULE_REFERENCE.md`, and `CHANGELOG.md`. `docs/PRINTING.md`
      replaces its bottom-fillet warning with the new styles, and it adds the
      opening tops and the layer-height rule. `docs/MODULE_REFERENCE.md`
      covers the new bottom-profile helper.
- [x] `README.md`'s feature table names the three new options.
- [x] `scripts/build_options_guide.py` gains entries and images for
      `Teardrop` openings and for the `Teardrop` and `Chamfer` bottom edges.
- [x] `tests/fixtures/missing_bosl2.scad` is regenerated, and the library
      metadata build is re-run. `library/index.json` gains the three defaults.
- [x] The scenario count, now 118, is updated wherever it appears:
      `AGENTS.md`, `README.md`,
      [E-09 (testing automation)](E-09_testing-automation.md), and
      `docs/internal/README.md`.

## Human print test (v2.0.0-rc.6)

The coupons are built with the maintainer's calibration tooling in
`_local/calibration/`, which is not in the repository.

- [ ] **Openings.** A short box with 22 mm openings, the router-shelf width,
      printed once with `Round` tops and once with `Teardrop` tops. The
      `Teardrop` tops show no drooped strands. The `Round` box is the control.
- [ ] **Bottom edge.** A 40 x 40 x 15 mm box with `Wall_Thickness=3` and
      `Bottom_Edge_Fillet=3`, printed in each style. `Teardrop` and `Chamfer`
      show no curled or lifted first layers.
- [ ] **Bridging.** A one-cell Gridfinity box with magnets, sliced at 0.28 mm
      with `Print_Layer_Height=0.28`, and again at the default 0.2 as a
      control. Add one sliced at 0.16 mm with `Print_Layer_Height=0.16`. The
      matched pockets bridge cleanly, and a 6 x 2 mm magnet still seats fully.

## Release plan

**Changed on 2026-10-09: E-14 ships in `v2.0.0-rc.6`, not as 2.1.0.** The
maintainer asked for a tagged release carrying E-14. 2.0.0 was not final, so a
2.1.0 tag could not come first, and the maintainer chose the 2.0.0 series. The
plan written on 2026-10-08 kept E-14 out of 2.0.0 to avoid adding scope there.
That concern now applies only to the defaults: every E-14 default keeps
today's geometry, so the 2.0.0 major gains three options and changes no preset.

1. **Done 2026-10-09.** One pull request carries all three parts. Its eight
   scenarios failed against `main` first, then passed. The full suite ran on
   OpenSCAD 2021.01 with CGAL, the mesh-identity criterion held, and the docs
   changed in the same pull request.
2. **Tag `v2.0.0-rc.6`** with E-12 phase A, E-13 (seam joints), and E-14.
   `Model_Version` stays `2.0.0`. The draft gets a hand-written "What's new
   since rc.5" and a "Known issues" section before it is published as a
   prerelease.
3. **Print the coupons** in the human print test above, in the same round as
   E-12's and E-13's rc.6 prints. If a print fails, fix the part in a later
   candidate.
4. **E-12 phase B ships in rc.7.** E-14 does not wait for it.
5. **2.0.0 final** follows `docs/RELEASE.md`, "Promoting a release candidate
   to final", once the print rounds pass.

**Later: the default changes.** Making `Teardrop` the default opening top, or
the default bottom edge style, is a major bump under E-10. E-03 (openings
array) is already the planned major that replaces the opening block, so both
defaults change there, and E-03's opening row gains a top-style field.

## Candidate fourth part (proposal, not in scope)

**14d. A teardrop Scallop relief on the lid.** `m_lid_relief` cuts the
`Scallop` as a horizontal cylinder of radius `Lid_Relief_Depth`, 2.5 mm by
default, at half the lid's height. The upper arc of a horizontal cylindrical
cut overhangs whichever way the lid lies on the bed. The same teardrop
treatment would fix it, with the point toward +Z in the lid's print
orientation. E-12 phase B flips that orientation, so this part must come after
the flip, which ships in 2.0.0.

The gain is small. At the default depth, the part of the arc flatter than 45
degrees spans about 0.7 mm of height, and
[E-04 (quick wins)](E-04_quick-wins.md) records the relief as never printed.
It stays out of scope until the maintainer chooses it.

## Risks

- **Slicer sampling.** Part 14c assumes that a slicer samples each layer at
  its middle height. PrusaSlicer, Bambu Studio, and OrcaSlicer do; Cura does
  at its default "Middle" slicing tolerance. The 0.28 mm print in the human
  print test is what confirms the rule.
- **Preview.** Every new cutter must stay free of `intersection()`. E-12 phase
  A showed that an intersection inside a repeated cutter can exceed preview's
  100,000-element limit, and no scenario would notice.
- **More material removed above each opening.** The teardrop shoulders remove
  a little wall above each opening. The cap stays at the typed height, so the
  wall above the opening keeps its height, and the shoulders reach no higher
  than the top of the round version.
- **Default changes are deferred, not free.** Anyone who wants the
  supportless shapes must opt in until E-03 lands. The options guide and
  `docs/PRINTING.md` should point at the new parameters, so users find them.

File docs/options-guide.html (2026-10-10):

Parametric Cable Box

# Every option, shown

A visual reference for the parametric cable management box. Each parameter below is rendered from the model itself, so what you see is what it builds.

Model 2.0.0 OpenSCAD 2021.01+ MIT licensed Self-contained, works offline

## Getting started

Two ways in, depending on whether you want to adjust anything.

If you want | Do this
A ready-to-print file | Grab an STL from library/ or from the GitHub Releases page. No software needed beyond a slicer.
To change the dimensions | Open cable-box-parametric.scad in OpenSCAD, press F3 for the Customizer, adjust, then F6 to render and export.
To start from a preset | Load a config.json from library/ in the Customizer's preset dropdown, then tweak.

Dimensions are outer dimensions. Box_Width, Box_Depth, and Box_Height describe the outside of the shell. Usable interior is smaller by Wall_Thickness on each side, and smaller again wherever stabilizer fins sit.

## Overall

What gets generated.

Box Only

Lid Only

Lid Only

Box and Lid

Box and Lid

## Box

Shell dimensions and wall.

Default 100 x 75 x 50

Default 100 x 75 x 50

Wide: 200 x 75 x 50

Tall: 100 x 75 x 90

Tall: 100 x 75 x 90

Corner radius 2 (crisp)

Corner radius 8.1 (default)

Corner radius 25 (soft)

Corner radius 25 (soft)

Wall 1.2 mm

Wall 3.0 mm

## Centre post

The cable-wrapping core.

Post enabled (default)

Post disabled

Post disabled

Post diameter 30

Closed_Post: solid floor under the post

Closed_Post: solid floor under the post

## Lid

Fit and engagement.

Default lid: Lid_Style Plug, a ring inside the wall

Lid_Style Skirt wraps the box

Lid_Height 16

Lid_Height 16

Lid_Lip_Gap_Height 8

## Edges, lid grip and magnets

Optional finishing features. All are off by default.

Bottom_Edge_Fillet 1.5

Bottom_Edge_Fillet 1.5

Bottom_Edge_Style Teardrop: meets the bed at 45 degrees

Bottom_Edge_Style Chamfer

Top_Edge_Chamfer 0.8

Top_Edge_Chamfer 0.8

Lid_Relief_Style Scallop

Lid_Relief_Style Tab

Lid_Relief_Style Tab

Enable_Lid_Magnets: corner bosses

## Side openings

Where cables enter and leave.

Default: 10 wide x 30 tall, 5 up from the floor

Width 30

Height 15

Height 15

All_Openings_Up 0: flush with the floor

All_Openings_Up 12: lifted further off the floor

Corner radius 0: square corners

Corner radius 0: square corners

Corner radius -1: fully rounded (default)

All_Opening_Top_Style Teardrop: tops print without support

All_Opening_Top_Style Teardrop: tops print without support

Front and back only

Front and back only

Per-side override: wide front opening

## Stabilizer fins

Interior ribs that stiffen the walls.

Disabled

Disabled

3 fins, centred (default)

5 fins, distributed

All four walls

All four walls

Taller and deeper fins

## Floor openings

Cutouts through the box floor.

Disabled (default)

Disabled (default)

3 openings along X

3 openings along X

Arranged along Y

6 openings, distributed

## Slicing for small beds

Split the model into pieces that push together. Floor clips hold them in line, and 45-degree teeth in the walls hold them level.

2 pieces, preview layout

2 pieces, preview layout

3 pieces

Exporting a single piece

Exporting a single piece

4 clips per seam

Flat seam, without teeth

Flat seam, without teeth

## Gridfinity

Optional interfaces, both shown from below.

Disabled (default)

Feet under the box, rounded up to whole cells

Feet under the box, rounded up to whole cells

Profile on the lid

Both, with magnet and screw holes

Both, with magnet and screw holes

Generated from cable-box-parametric.scad 2.0.0 by scripts/build_options_guide.py. Rebuild it after changing the model so the images stay honest.

Gridfinity is by Zack Freedman, MIT licensed. Geometry here is implemented from the published specification.

Toggle theme

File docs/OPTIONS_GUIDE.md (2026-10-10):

# Options Guide

Visual reference for every parameter, rendered from the model at `2.0.0`.

A self-contained HTML version with the images embedded is at [`options-guide.html`](options-guide.html); it works offline.

For the exhaustive parameter tables, see [`PARAMETER_REFERENCE.md`](PARAMETER_REFERENCE.md).

## Overall

What gets generated.

### Box Only

`Part_To_Render=Box Only`

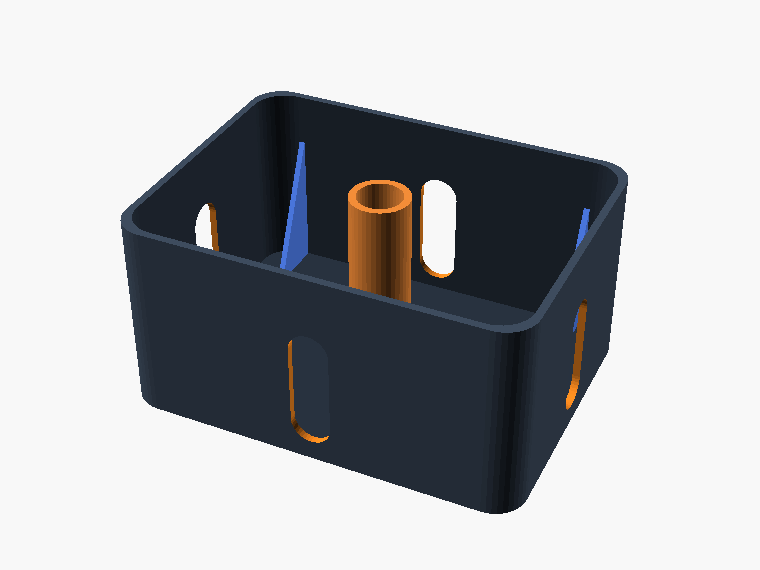
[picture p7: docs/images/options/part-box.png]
Box Only


### Lid Only

`Part_To_Render=Lid Only`

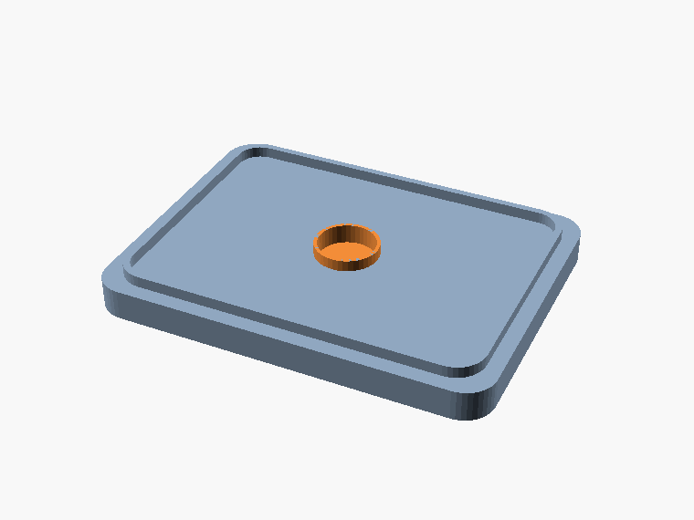
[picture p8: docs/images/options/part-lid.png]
Lid Only


### Box and Lid

`Part_To_Render=Box and Lid`

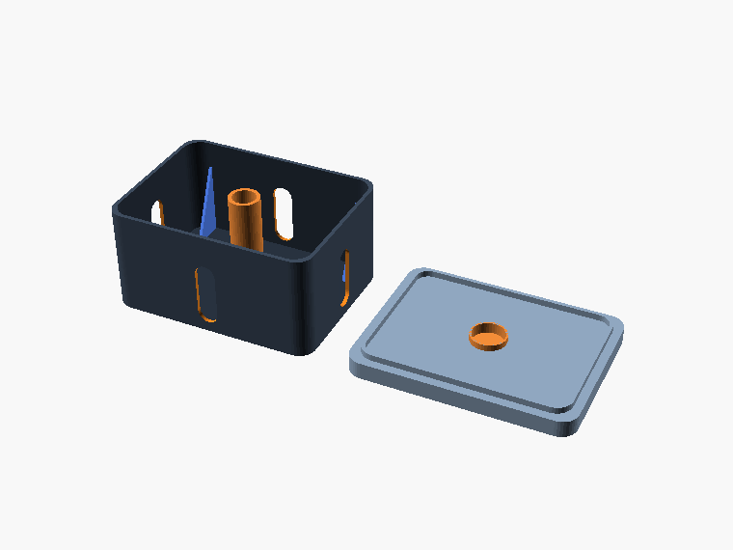
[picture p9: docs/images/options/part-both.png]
Box and Lid


## Box

Shell dimensions and wall.

### Default 100 x 75 x 50

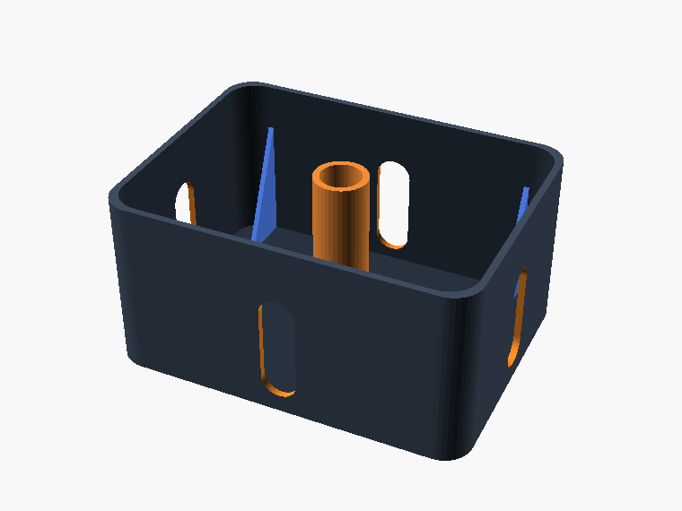
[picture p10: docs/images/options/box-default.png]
Default 100 x 75 x 50


### Wide: 200 x 75 x 50

`Box_Width=200`

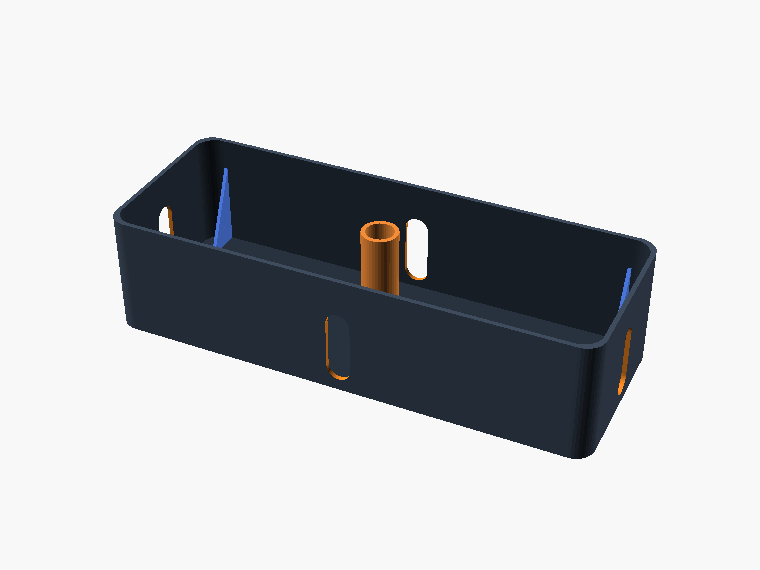
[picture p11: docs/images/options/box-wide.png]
Wide: 200 x 75 x 50


### Tall: 100 x 75 x 90

`Box_Height=90`

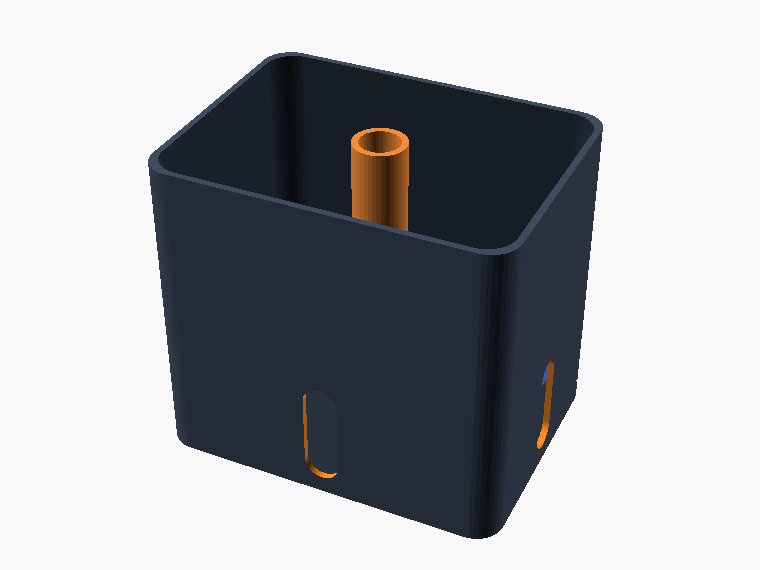
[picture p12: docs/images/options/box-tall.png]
Tall: 100 x 75 x 90


### Corner radius 2 (crisp)

`Box_Corner_Radius=2`

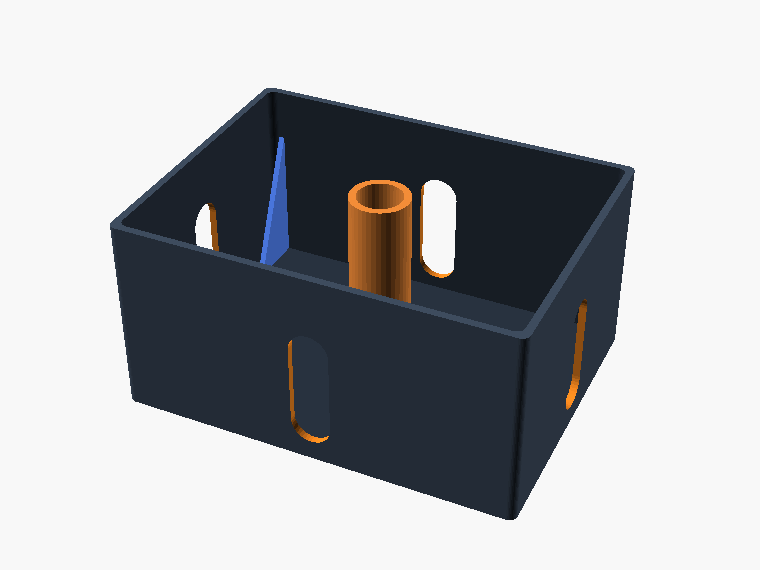
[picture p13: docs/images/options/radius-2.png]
Corner radius 2 (crisp)


### Corner radius 8.1 (default)

Corner radius 8.1 (default)

### Corner radius 25 (soft)

`Box_Corner_Radius=25`

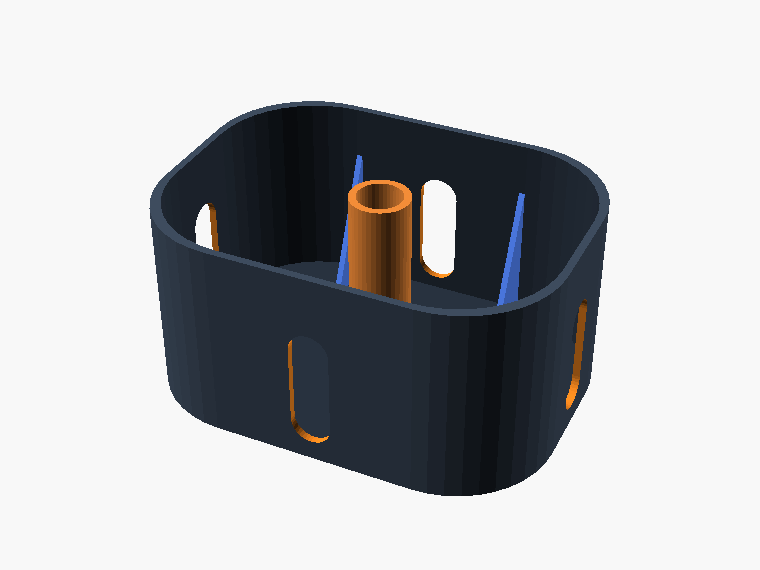
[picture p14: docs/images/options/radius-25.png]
Corner radius 25 (soft)


### Wall 1.2 mm

`Wall_Thickness=1.2`

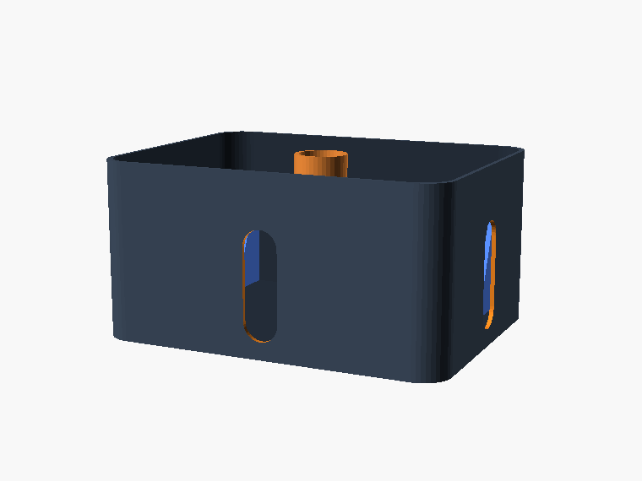
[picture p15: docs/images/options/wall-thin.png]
Wall 1.2 mm


### Wall 3.0 mm

`Wall_Thickness=3.0`

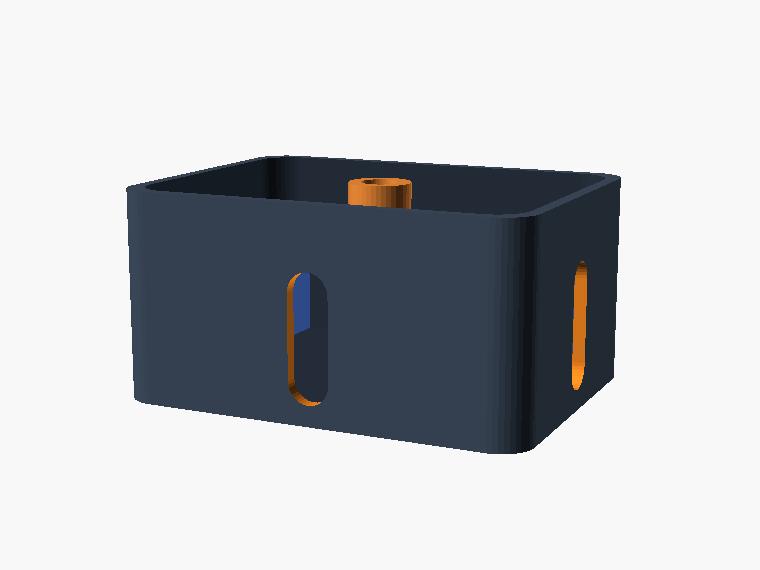
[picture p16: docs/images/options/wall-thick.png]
Wall 3.0 mm


## Centre post

The cable-wrapping core.

### Post enabled (default)

Post enabled (default)

### Post disabled

`Enable_Post=False`

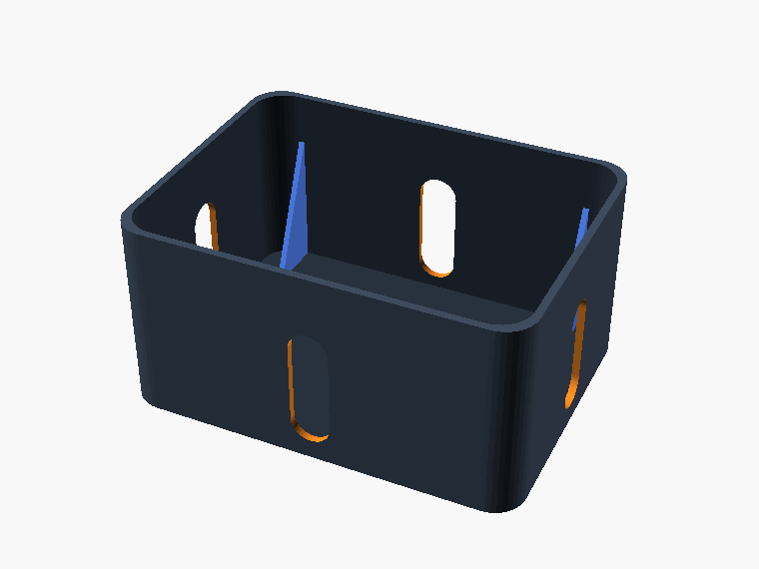
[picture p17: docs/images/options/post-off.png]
Post disabled


### Post diameter 30

`Post_Diameter=30`

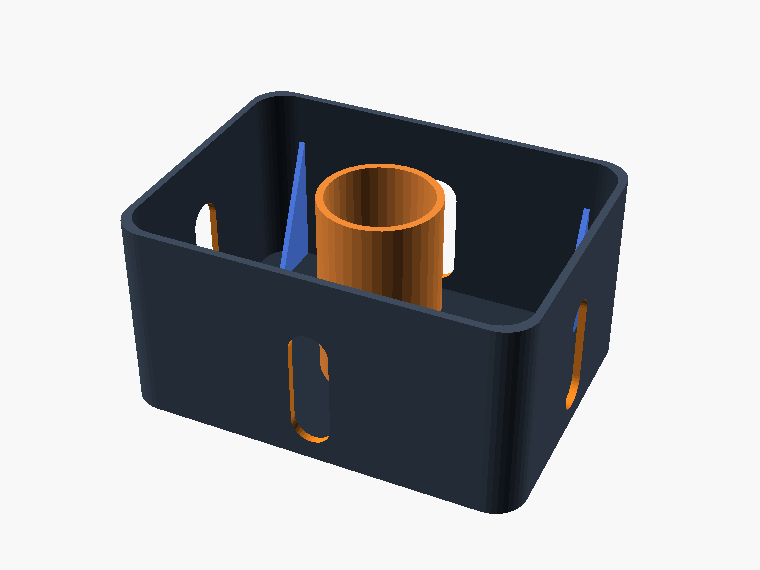
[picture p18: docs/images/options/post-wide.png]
Post diameter 30


### Closed_Post: solid floor under the post

`Closed_Post=True`

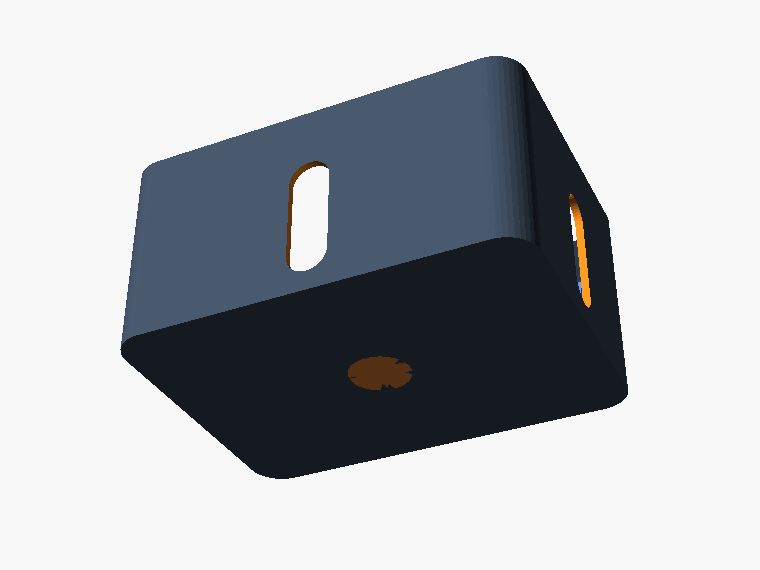
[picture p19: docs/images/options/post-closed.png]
Closed_Post: solid floor under the post


## Lid

Fit and engagement.

### Default lid: Lid_Style Plug, a ring inside the wall

`Part_To_Render=Lid Only`

Default lid: Lid_Style Plug, a ring inside the wall

### Lid_Style Skirt wraps the box

`Part_To_Render=Lid Only`, `Lid_Style=Skirt`

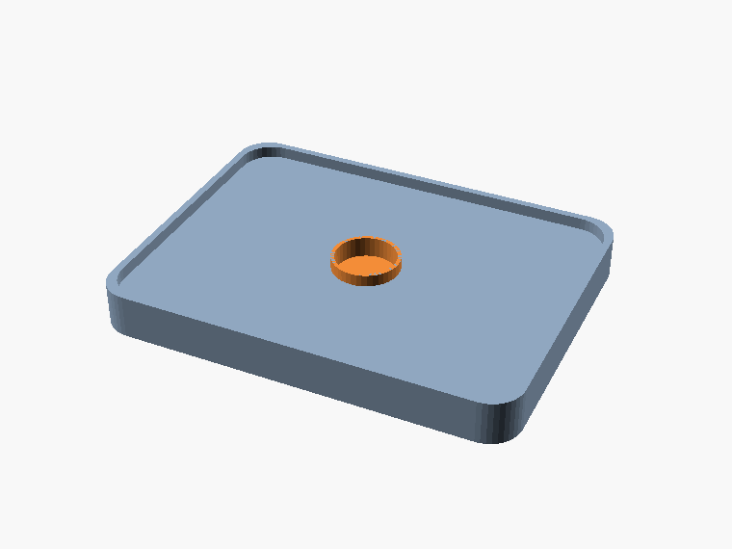
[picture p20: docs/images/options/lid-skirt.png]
Lid_Style Skirt wraps the box


### Lid_Height 16

`Part_To_Render=Lid Only`, `Lid_Height=16`

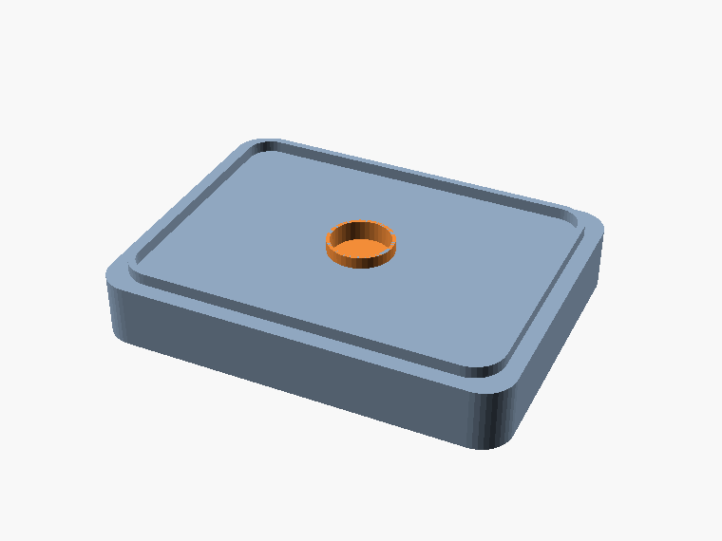
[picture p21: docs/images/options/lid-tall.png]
Lid_Height 16


### Lid_Lip_Gap_Height 8

`Part_To_Render=Lid Only`, `Lid_Lip_Gap_Height=8`

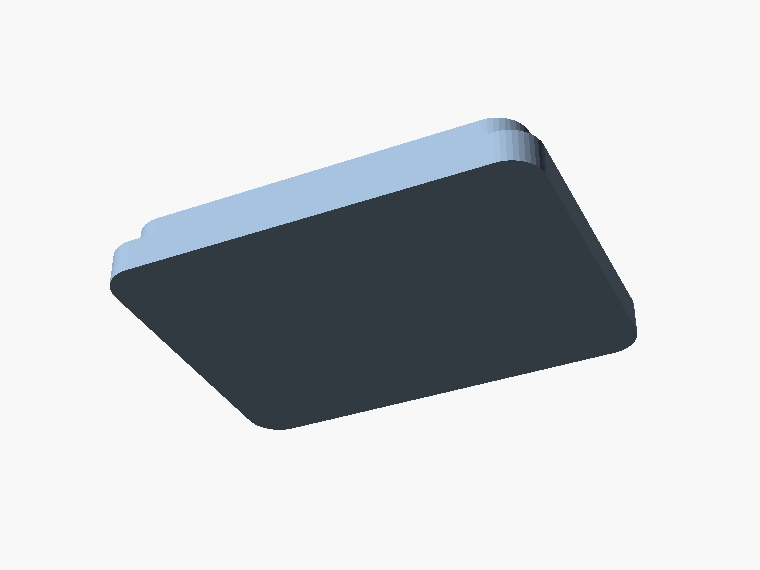
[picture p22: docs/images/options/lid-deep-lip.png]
Lid_Lip_Gap_Height 8


## Edges, lid grip and magnets

Optional finishing features. All are off by default.

### Bottom_Edge_Fillet 1.5

`Bottom_Edge_Fillet=1.5`

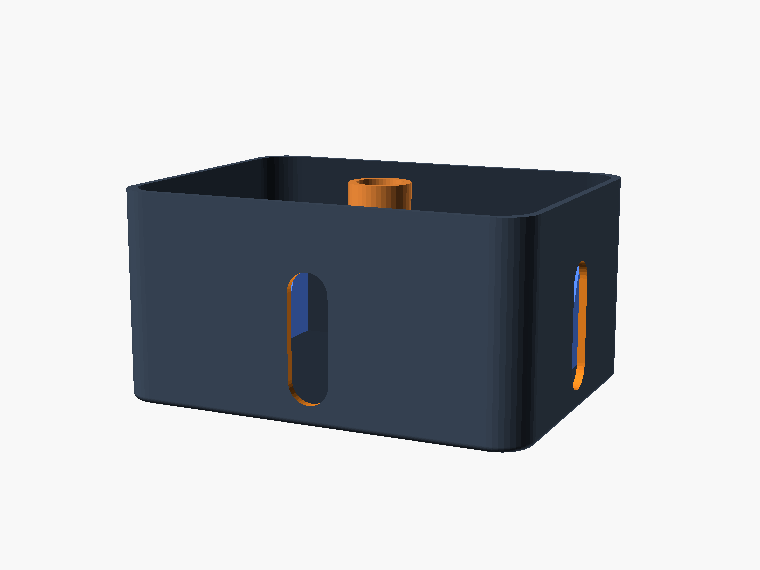
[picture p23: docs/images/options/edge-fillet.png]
Bottom_Edge_Fillet 1.5


### Bottom_Edge_Style Teardrop: meets the bed at 45 degrees

`Bottom_Edge_Fillet=1.5`, `Bottom_Edge_Style=Teardrop`

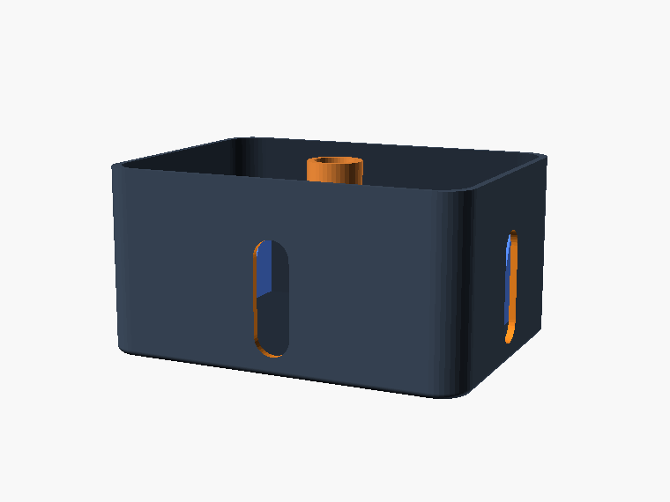
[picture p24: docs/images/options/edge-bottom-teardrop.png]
Bottom_Edge_Style Teardrop: meets the bed at 45 degrees


### Bottom_Edge_Style Chamfer

`Bottom_Edge_Fillet=1.5`, `Bottom_Edge_Style=Chamfer`

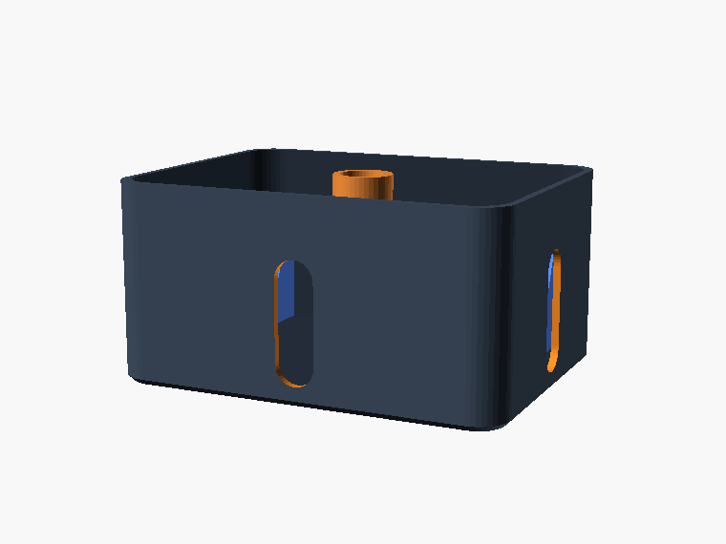
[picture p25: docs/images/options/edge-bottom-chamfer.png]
Bottom_Edge_Style Chamfer


### Top_Edge_Chamfer 0.8

`Top_Edge_Chamfer=0.8`

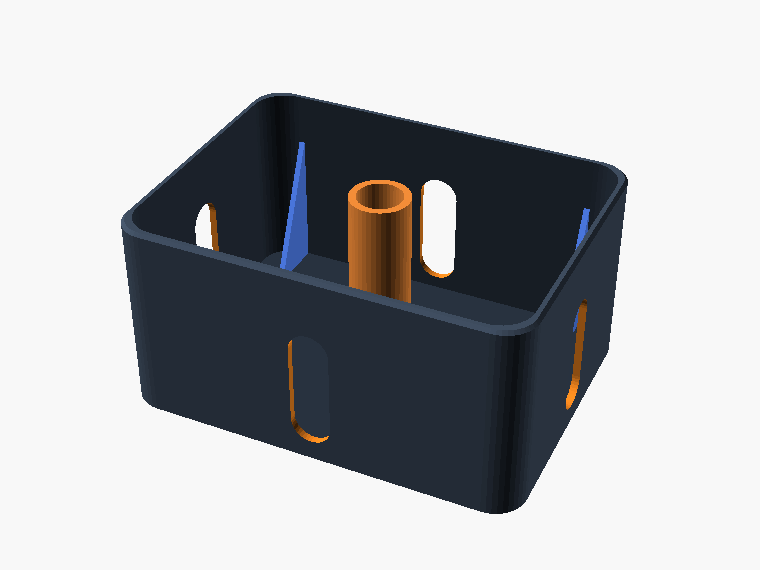
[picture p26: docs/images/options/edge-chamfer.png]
Top_Edge_Chamfer 0.8


### Lid_Relief_Style Scallop

`Part_To_Render=Lid Only`, `Lid_Relief_Style=Scallop`

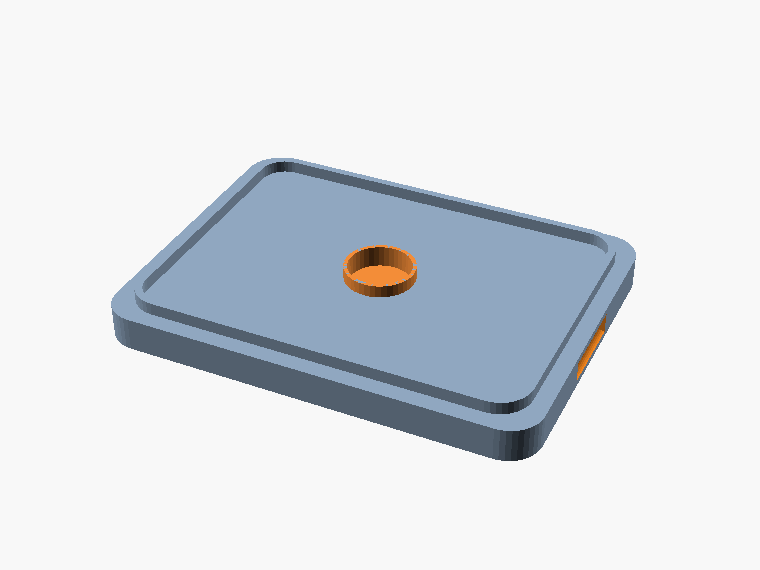
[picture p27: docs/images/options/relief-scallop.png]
Lid_Relief_Style Scallop


### Lid_Relief_Style Tab

`Part_To_Render=Lid Only`, `Lid_Relief_Style=Tab`

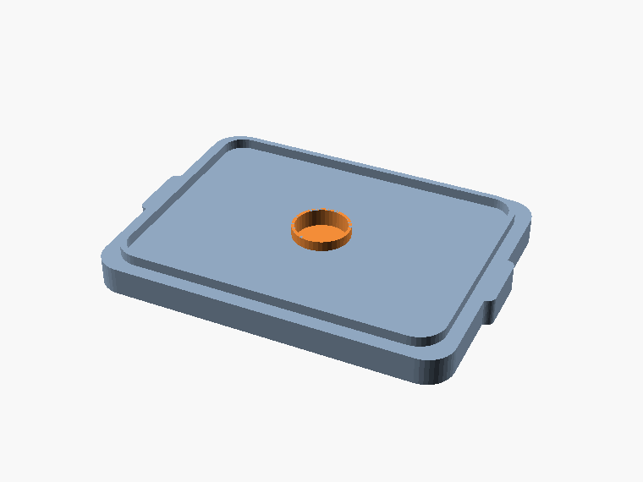
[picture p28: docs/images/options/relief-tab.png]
Lid_Relief_Style Tab


### Enable_Lid_Magnets: corner bosses

`Enable_Lid_Magnets=True`

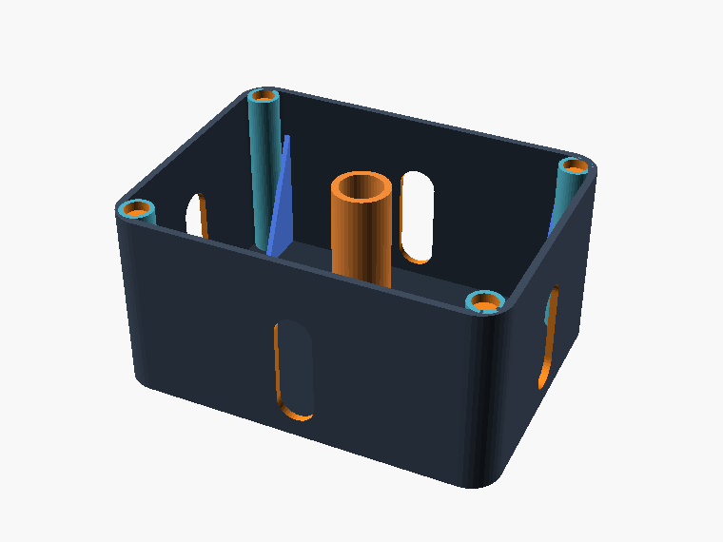
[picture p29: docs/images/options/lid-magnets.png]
Enable_Lid_Magnets: corner bosses


## Side openings

Where cables enter and leave.

### Default: 10 wide x 30 tall, 5 up from the floor

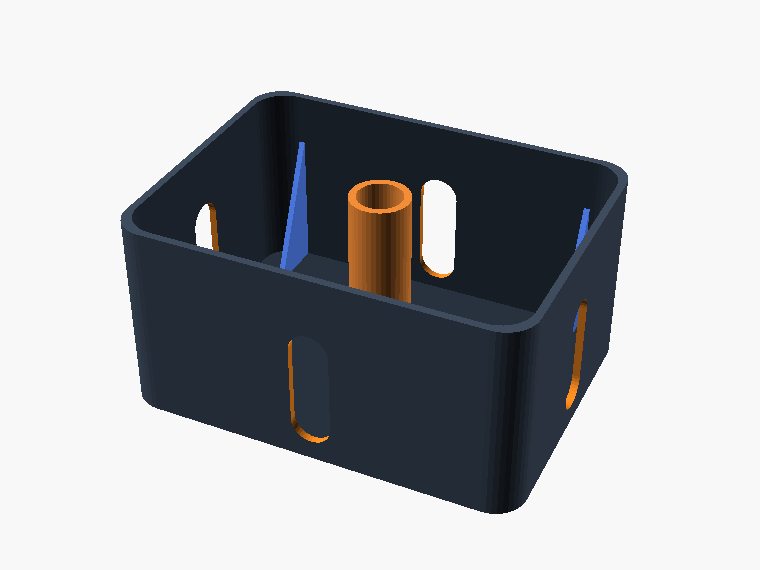
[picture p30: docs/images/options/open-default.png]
Default: 10 wide x 30 tall, 5 up from the floor


### Width 30

`All_Opening_Width=30`

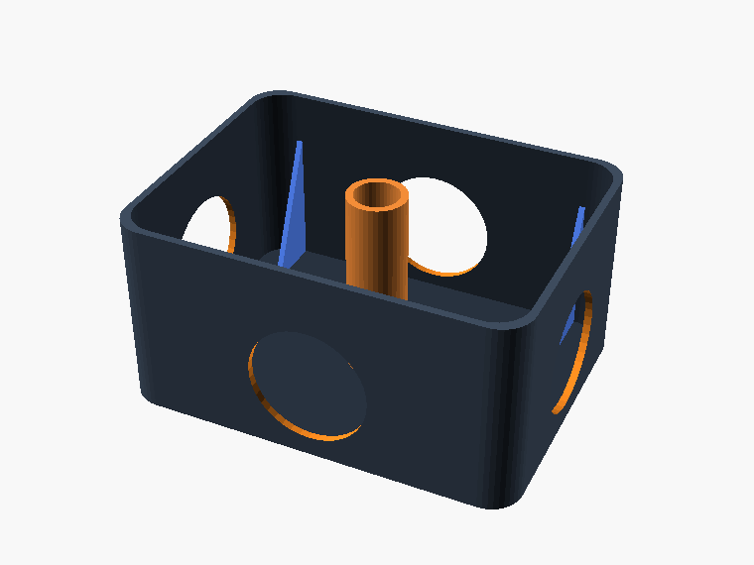
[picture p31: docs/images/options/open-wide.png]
Width 30


### Height 15

`All_Opening_Height=15`

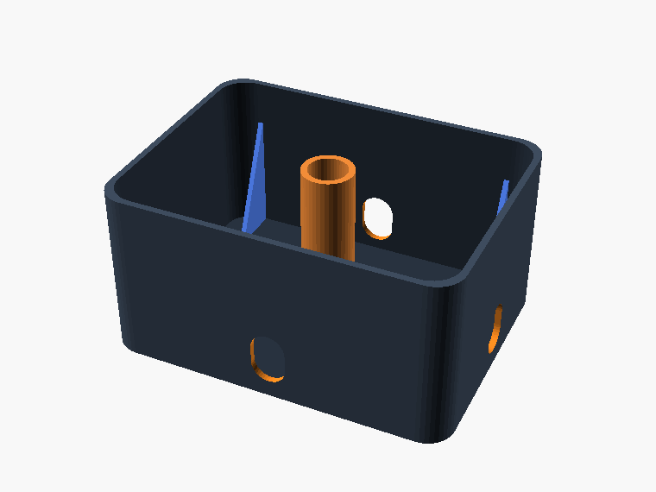
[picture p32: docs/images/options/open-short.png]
Height 15


### All_Openings_Up 0: flush with the floor

`All_Openings_Up=0`

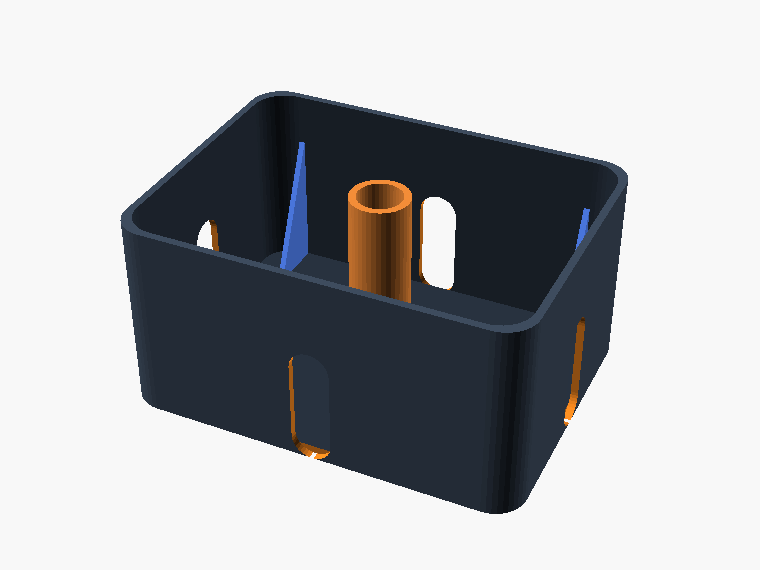
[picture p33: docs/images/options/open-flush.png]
All_Openings_Up 0: flush with the floor


### All_Openings_Up 12: lifted further off the floor

`All_Openings_Up=12`

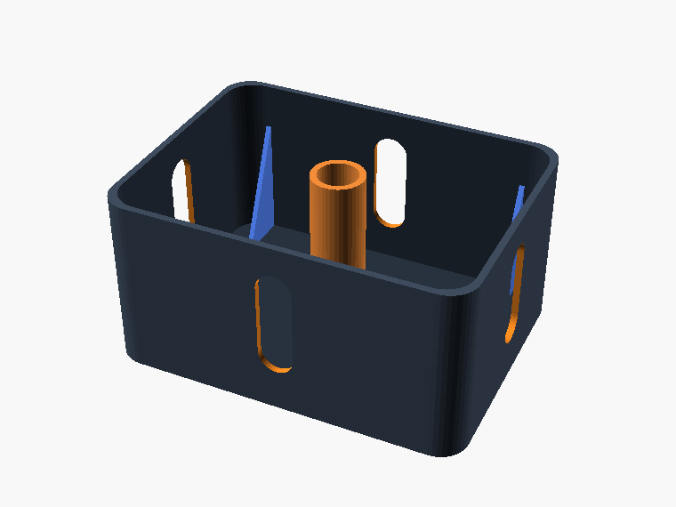
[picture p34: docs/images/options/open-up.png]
All_Openings_Up 12: lifted further off the floor


### Corner radius 0: square corners

`All_Opening_Corner_Radius=0`

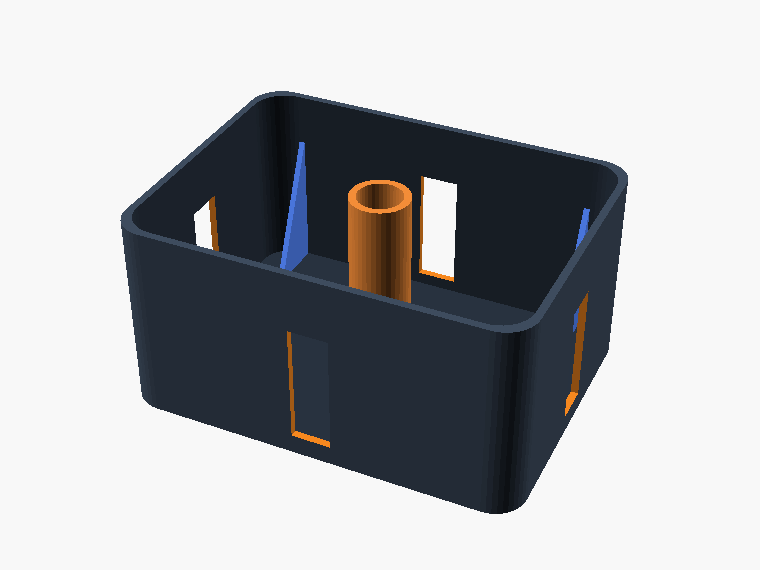
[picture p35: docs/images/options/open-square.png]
Corner radius 0: square corners


### Corner radius -1: fully rounded (default)

Corner radius -1: fully rounded (default)

### All_Opening_Top_Style Teardrop: tops print without support

`All_Opening_Width=20`, `All_Opening_Top_Style=Teardrop`

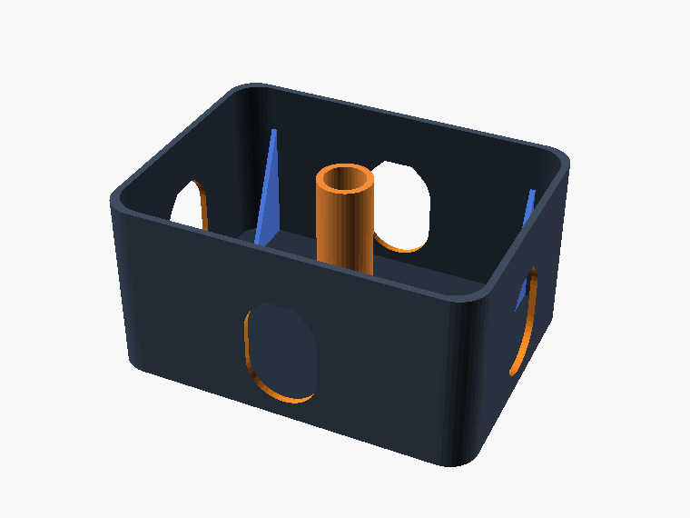
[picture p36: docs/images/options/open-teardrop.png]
All_Opening_Top_Style Teardrop: tops print without support


### Front and back only

`Opening_On_Left=False`, `Opening_On_Right=False`

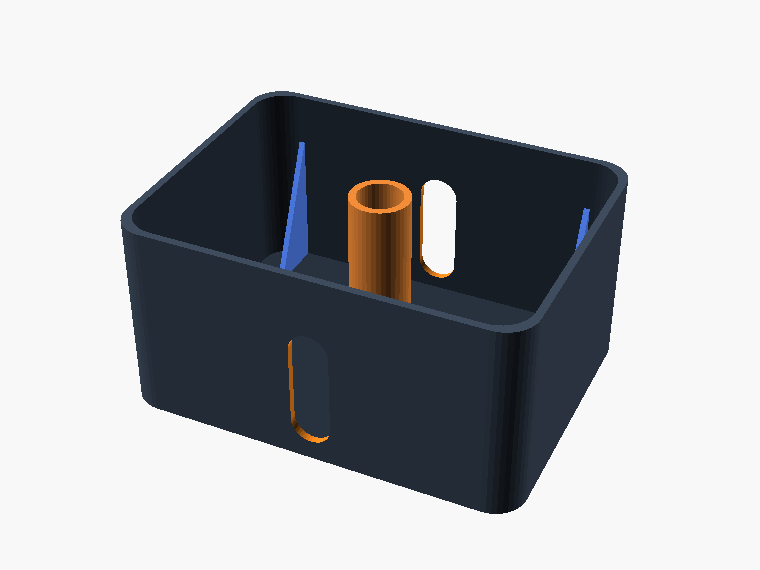
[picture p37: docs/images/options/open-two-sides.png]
Front and back only


### Per-side override: wide front opening

`Override_Opening_Width_Front=40`, `Override_Opening_Height_Front=20`

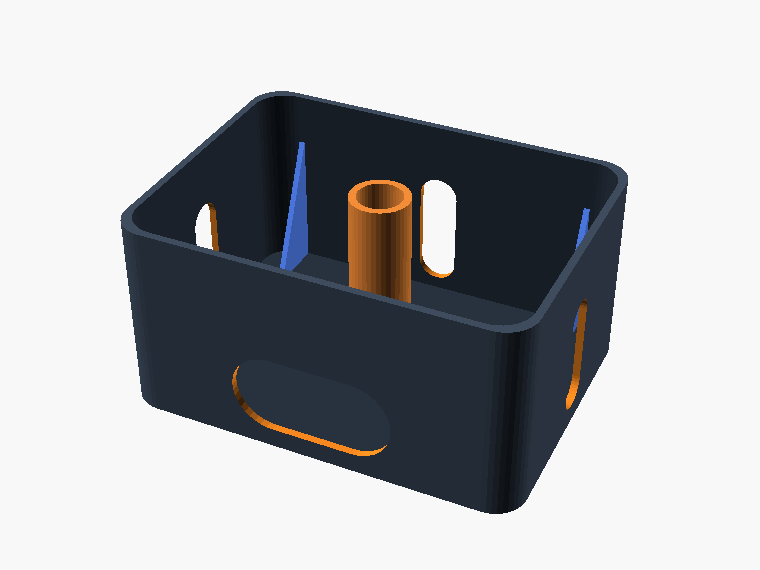
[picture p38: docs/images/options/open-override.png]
Per-side override: wide front opening


## Stabilizer fins

Interior ribs that stiffen the walls.

### Disabled

`Enable_Stabilizers=False`

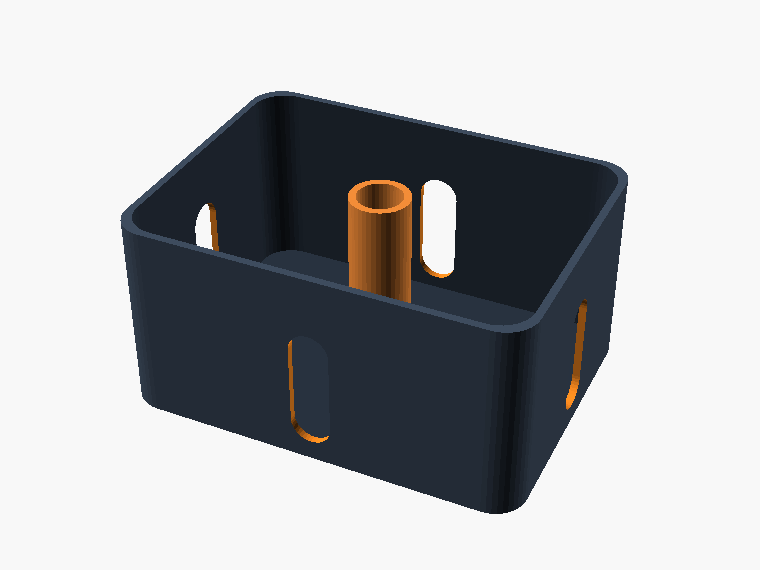
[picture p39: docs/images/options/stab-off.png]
Disabled


### 3 fins, centred (default)

3 fins, centred (default)

### 5 fins, distributed

`Stabilizers_Front_Back_Count=5`, `Stabilizers_Front_Back_Alignment=Distributed`

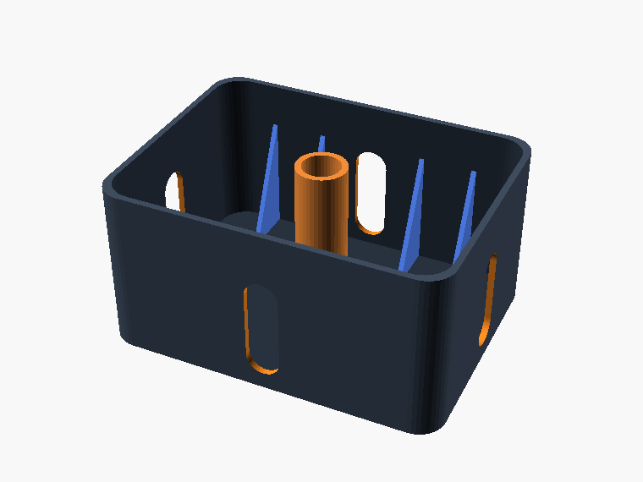
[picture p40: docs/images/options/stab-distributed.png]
5 fins, distributed


### All four walls

`Stabilizers_Left_Right_Count=2`

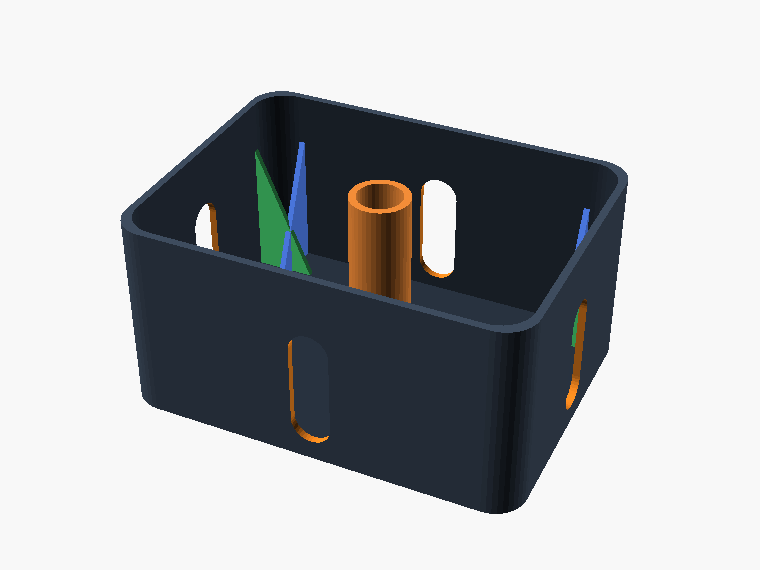
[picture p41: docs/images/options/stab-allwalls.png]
All four walls


### Taller and deeper fins

`Stabilizer_Height=44`, `Stabilizer_Depth=22`

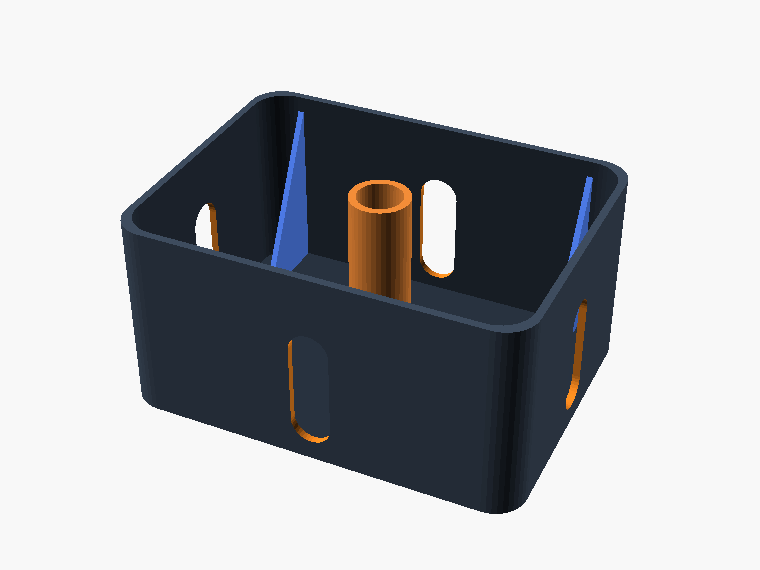
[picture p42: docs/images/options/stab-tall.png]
Taller and deeper fins


## Floor openings

Cutouts through the box floor.

### Disabled (default)

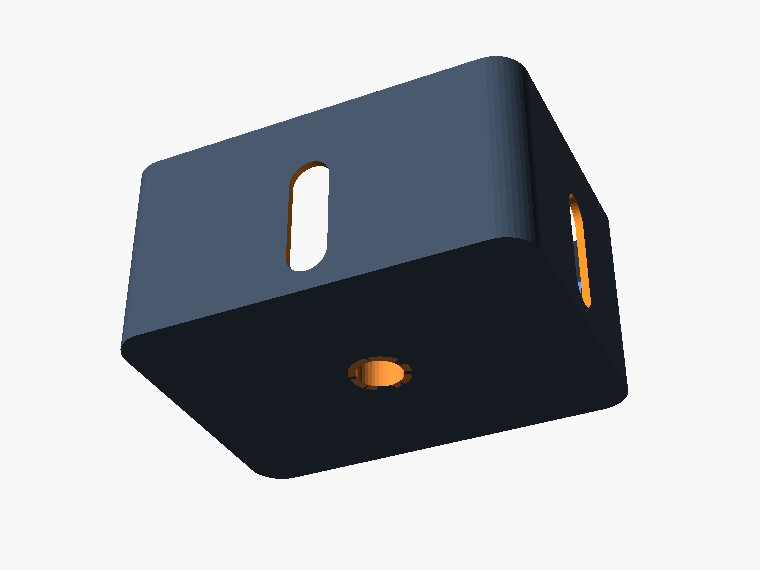
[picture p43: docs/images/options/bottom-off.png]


### 3 openings along X

`Enable_Bottom_Openings=True`

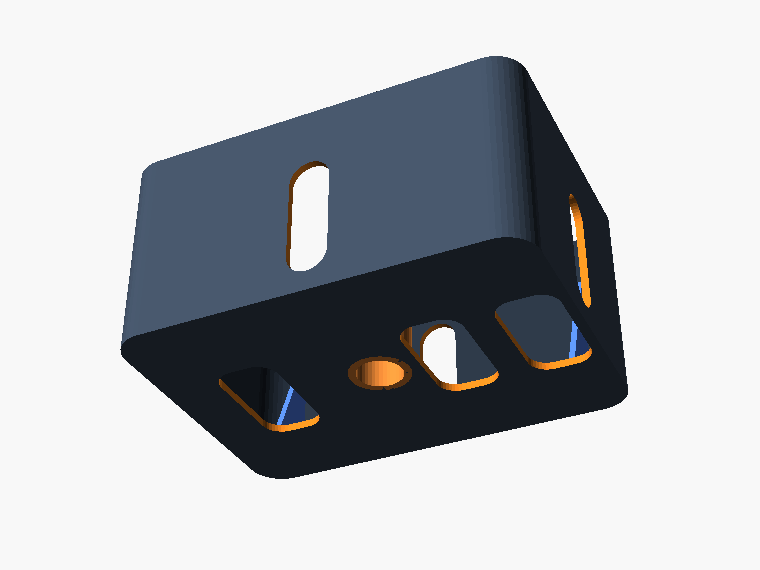
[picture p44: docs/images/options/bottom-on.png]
3 openings along X


### Arranged along Y

`Enable_Bottom_Openings=True`, `Bottom_Opening_Axis=Along Y`

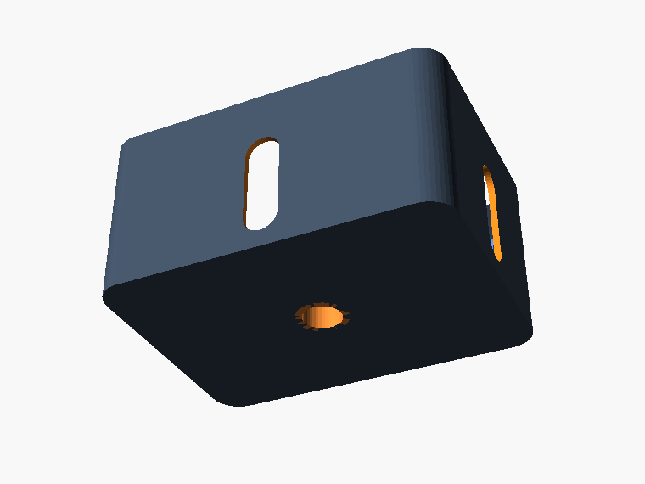
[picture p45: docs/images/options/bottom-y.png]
Arranged along Y


### 6 openings, distributed

`Enable_Bottom_Openings=True`, `Bottom_Openings_Count=6`, `Bottom_Opening_Alignment_Primary=Distributed`

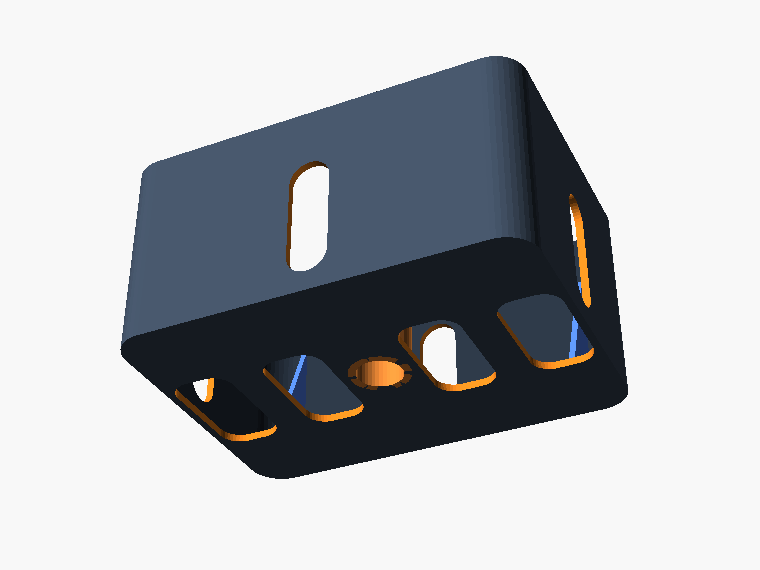
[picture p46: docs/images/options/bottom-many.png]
6 openings, distributed


## Slicing for small beds

Split the model into pieces that push together. Floor clips hold them in line, and 45-degree teeth in the walls hold them level.

### 2 pieces, preview layout

`Enable_Slicing=True`, `Slice_Count=2`, `Part_To_Render=Box Only`

2 pieces, preview layout

### 3 pieces

`Enable_Slicing=True`, `Slice_Count=3`, `Part_To_Render=Box Only`

3 pieces

### Exporting a single piece

`Enable_Slicing=True`, `Slice_Count=2`, `Slice_Piece_To_Render=1`, `Part_To_Render=Box Only`

Exporting a single piece

### 4 clips per seam

`Enable_Slicing=True`, `Slice_Count=2`, `Clips_Per_Edge=4`, `Part_To_Render=Box Only`

4 clips per seam

### Flat seam, without teeth

`Enable_Slicing=True`, `Slice_Count=2`, `Seam_Tooth_Depth=0`, `Part_To_Render=Box Only`

Flat seam, without teeth

## Gridfinity

Optional interfaces, both shown from below.

### Disabled (default)

`Closed_Post=True`

Disabled (default)

### Feet under the box, rounded up to whole cells

`Enable_Gridfinity_Bottom=True`, `Closed_Post=True`

Feet under the box, rounded up to whole cells

### Profile on the lid

`Enable_Gridfinity_Lid_Top=True`, `Part_To_Render=Lid Only`

Profile on the lid

### Both, with magnet and screw holes

`Enable_Gridfinity_Bottom=True`, `Enable_Gridfinity_Lid_Top=True`, `Closed_Post=True`, `Enable_Gridfinity_Magnet_Screw=True`

Both, with magnet and screw holes

---

Generated by `scripts/build_options_guide.py`. Rebuild after model changes.

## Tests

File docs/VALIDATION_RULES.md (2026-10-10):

# Validation Rules

This page documents every model assertion in `cable-box-parametric.scad`, what
triggers it, and how to resolve it.

## Why the model asserts at all

OpenSCAD will happily render geometry that cannot be printed. A stabilizer fin
taller than the box, an opening taller than the wall it cuts, or a post wider
than the box all produce a valid mesh and exit code `0`. The assertions below
convert that class of silent nonsense into an actionable message, and replace
low-level BOSL2 errors with ones that name the parameter you actually typed.

## Box and Wall

### Box dimensions must be positive

```scad
assert(Box_Width > 0 && Box_Depth > 0 && Box_Height > 0,
       "Box_Width, Box_Depth, and Box_Height must be > 0");
```

Why: a non-positive extent produces a degenerate solid, and BOSL2 aborts with an
internal `all_positive(size)` message that does not name the parameter.

Fix: set all three above `0`.

### Wall thickness must be positive and must fit

```scad
assert(Wall_Thickness > 0, "Wall_Thickness must be > 0");
assert(Wall_Thickness * 2 < min(Box_Width_Effective, Box_Depth_Effective),
       "Wall_Thickness is too large for the box footprint; Inner_Width and Inner_Depth would be <= 0");
```

Why: `Inner_Width` and `Inner_Depth` are derived as the outer size minus two
walls. If the walls meet or cross, the interior inverts and every placement
calculation downstream operates on a negative span.

`Box_Width_Effective` and `Box_Depth_Effective` are the footprint the model
builds. They equal `Box_Width` and `Box_Depth` unless a Gridfinity base rounds
the footprint up to whole cells, as the Gridfinity section below describes.
Every rule that tests the footprint reads them.

Fix: keep `Wall_Thickness` below half the smaller footprint dimension.

### Corner radius must be non-negative

```scad
assert(Box_Corner_Radius >= 0, "Box_Corner_Radius must be >= 0");
```

Why: negative rounding has no geometric meaning.

Fix: use `0` for square vertical edges, or any positive value.

An over-large radius is clamped rather than rejected. See
[Clamped values rather than assertions](#clamped-values-rather-than-assertions).

## Post

### Post must have a wall, and must fit inside the box

```scad
assert(!Enable_Post || Post_Diameter > Wall_Thickness * 2,
       "Post_Diameter must exceed Wall_Thickness*2 so the post has a wall");
assert(!Enable_Post || Post_Diameter < min(Inner_Width, Inner_Depth),
       "Post_Diameter must fit inside the box interior");
```

Why: the post is an outer cylinder minus a bore of
`Post_Diameter - Wall_Thickness*2`. If that bore is not smaller than the outer
diameter, no post wall remains. If the post is wider than the interior it
consumes the box walls instead of standing inside them, which previously
rendered successfully and produced a collapsed model.

Fix: keep `Post_Diameter` between `Wall_Thickness*2` and the smaller interior span.

## Lid

### Lid style must be a known value

```scad
assert(Lid_Style == "Skirt" || Lid_Style == "Plug", "Lid_Style must be Skirt or Plug");
```

Why: any other string would silently build the Plug branch.

Fix: use `Skirt` or `Plug`.

### A Plug lid needs room inside the walls

```scad
assert(Lid_Style != "Plug" || min(Plug_Outer_Width, Plug_Outer_Depth) > Wall_Thickness * 2,
       "The box is too small for a Plug lid: ...");
```

Why: the plug ring is `Wall_Thickness` thick and sits `Lid_Lip_Gap` inside the
wall on every side. In a very small box the ring's inside would invert, and
BOSL2 aborts with a message about a negative size.

Fix: use `Lid_Style=Skirt`, or enlarge `Box_Width` or `Box_Depth`.

### A Plug lid needs the stabilizer fins to stop below it

```scad
assert(Lid_Style != "Plug" || !Enable_Stabilizers ||
       Stabilizer_Height + Wall_Thickness <= Box_Height - Lid_Lip_Gap_Height,
       "With Lid_Style Plug, Stabilizer_Height must be at most ...");
```

Why: the plug ring sits in the top `Lid_Lip_Gap_Height` of the box, against
the walls the fins grow from. A fin reaching into that band renders cleanly and
stops the lid from seating, so nothing but a print would show it. The box's own
fin check allows fins right up to the rim, which a Skirt lid tolerates. Plug
is the default, so this check applies unless you choose Skirt, and it applies
even when only the box is rendered.

Fix: lower `Stabilizer_Height` to the value in the message, or use
`Lid_Style=Skirt`.

### A Plug lid needs the post to clear the ring

```scad
assert(Lid_Style != "Plug" || !Enable_Post ||
       Post_Diameter / 2 + Lid_Lip_Gap <= min(Plug_Outer_Width, Plug_Outer_Depth) / 2 - Wall_Thickness,
       "With Lid_Style Plug, Post_Diameter is too large: ...");
```

Why: the post stands in the middle of the cavity. A post that fits the box can
still reach the inside face of the plug ring in a narrow box, and the lid would
not seat.

Fix: reduce `Post_Diameter`, or use `Lid_Style=Skirt`.

The plug ring is notched around the magnet bosses instead of asserting,
because the bosses sit in the corners where a notch leaves the rest of the ring
intact.

The model runs these three Plug checks after the box's own post and stabilizer
checks. A value that breaks both limits therefore reports the box limit first,
because that limit holds for either lid style.

## Stabilizers

### Fins must fit inside the box

```scad
assert(!Enable_Stabilizers || Stabilizer_Height + Wall_Thickness <= Box_Height,
       "Stabilizer_Height plus the floor exceeds Box_Height");
assert(!Enable_Stabilizers || Stabilizer_Depth * 2 < min(Inner_Width, Inner_Depth),
       "Stabilizer_Depth is too large for the box interior");
assert(!Enable_Stabilizers || Stabilizer_Width > 0,
       "Stabilizer_Width must be > 0");
```

Why: fins sit on top of the floor, so their usable height is
`Box_Height - Wall_Thickness`. A taller fin protrudes above the rim and stops the
lid seating. A fin deeper than half the interior meets the fin on the opposite wall.

Fix: reduce `Stabilizer_Height` or `Stabilizer_Depth`, or increase the box.

### Fin counts must be non-negative

```scad
assert(Stabilizers_Front_Back_Count >= 0 && Stabilizers_Left_Right_Count >= 0,
       "Stabilizer counts must be >= 0");
```

Why: negative counts were previously treated as zero, which hid the typo.

Fix: use `0` to disable a wall pair, or any positive count.

### Fin spacing must be non-negative

```scad
assert(Stabilizer_FB_Spacing >= 0 && Stabilizer_LR_Spacing >= 0,
       "Stabilizer spacing must be >= 0");
```

Why: negative spacing would overlap adjacent fins into a single mass.

Fix: use `0` for touching fins, or any positive gap.

## Side Openings

### Global opening dimensions must be positive and must fit

```scad
assert(All_Opening_Height > 0 && All_Opening_Width > 0,
       "All_Opening_Height and All_Opening_Width must be > 0");
assert(len([for (side = OPENING_SIDES) if (opening_enabled(side)) side]) == 0 ||
       All_Opening_Height <= Box_Height, "All_Opening_Height must not exceed Box_Height");
```

Why: openings must have real dimensions, and an opening taller than the wall
removes the entire wall rather than cutting a slot in it. The height bound
applies only when at least one side opening is on, so a shallow box with
closed walls is not blocked by an opening height it never cuts.

Fix: keep the height at or below `Box_Height`. Width may be larger or smaller
than height; vertical, horizontal, and square profiles are all allowed.

This bound covers the height alone. An opening's top edge also moves with
`All_Openings_Up` and its wall's `Move_Opening_*_Up`, and a lifted opening can
end above the rim. That is reported rather than rejected; see
[Clamped Values Rather Than Assertions](#clamped-values-rather-than-assertions).

### Override dimensions must be non-negative

```scad
for (side = OPENING_SIDES)
    assert(min(opening_size_overrides(side)) >= 0,
           str(side, " opening width and height overrides must be 0 (use the global size) or positive"));
```

The check runs once per wall, so the message names the wall at fault, for
example "Left opening width and height overrides must be 0 ...".

Why: override values use `0` as the sentinel for "use the global default".

Fix: keep overrides at `0` or any positive number.

### Corner radius values must be at least -1

```scad
assert(All_Opening_Corner_Radius >= -1 &&
       Override_Opening_Corner_Radius_Front >= -1 &&
       Override_Opening_Corner_Radius_Back >= -1 &&
       Override_Opening_Corner_Radius_Left >= -1 &&
       Override_Opening_Corner_Radius_Right >= -1,
       "Corner radius values must be >= -1");
```

Why: `-1` is the sentinel for fully rounded slot ends. Values below it have no
meaning.

Fix: use `-1` for fully rounded, `0` for square, or a positive radius.

### Opening top style must be a known value

```scad
assert(len([for (side = OPENING_SIDES) if (opening_enabled(side)) side]) == 0 ||
       All_Opening_Top_Style == "Round" || All_Opening_Top_Style == "Teardrop",
       "All_Opening_Top_Style must be Round or Teardrop");
```

Why: any other value would silently render round tops, which is the overhang
the option exists to remove. Checked only while a side opening is on.

Fix: use `Round`, the default, or `Teardrop`.

## Bottom Openings

### Count must be at least one when enabled

```scad
assert(!Enable_Bottom_Openings || Bottom_Openings_Count >= 1,
       "Bottom_Openings_Count must be >= 1 when bottom openings are enabled");
```

Why: this is the highest-consequence guard in the file. At `0`, the placement
loop `for (i = [0:Bottom_Openings_Count-1])` becomes `[0:-1]`, and OpenSCAD's
deprecated reverse-range behavior iterates it as `-1` then `0`. That cut two
unintended openings straddling the box center, which with the post enabled
undercut the post footprint and detached it from the floor. The result was two
disconnected solids returned at exit code `0`.

Fix: set `Enable_Bottom_Openings=false` to disable the feature, or use a count of
`1` or more.

### Opening dimensions must be positive when enabled

```scad
assert(!Enable_Bottom_Openings || (Bottom_Opening_Width > 0 && Bottom_Opening_Depth > 0),
       "Bottom opening width and depth must be > 0");
```

Why: a zero-extent cutout produces a degenerate subtraction.

Fix: set both above `0`.

### Post margin must be non-negative

```scad
assert(Bottom_Opening_Post_Margin >= 0, "Bottom opening post margin must be >= 0");
```

Why: a negative margin would pull openings toward the post rather than away.

Fix: use `0` for openings that touch the post clearance circle, or a positive gap.

## Slicing and Clips

### Slice index must be a valid integer

```scad
assert(is_int(Slice_Piece_To_Render) &&
       Slice_Piece_To_Render >= 0 &&
       Slice_Piece_To_Render <= Slice_Count,
       "Slice piece to render must be an integer in range 0..slice count");
```

Why: `0` is reserved for the all-slices preview, and `1..Slice_Count` map to
specific outputs. A fractional or out-of-range index has no output to select.

Fix: use `0` or an integer from `1` to `Slice_Count`.

### Slice count must be at least 2 when slicing

```scad
assert(!Enable_Slicing || Slice_Count >= 2,
       "Slice count must be >= 2 when slicing is enabled");
```

Why: slicing into one piece is a no-op with extra clip geometry attached.

Fix: set `Slice_Count >= 2`, or disable slicing.

### Clips per edge must be at least 1 when slicing

```scad
assert(!Enable_Slicing || Clips_Per_Edge >= 1, "Clips per edge must be >= 1");
```

Why: a seam with no clips leaves the printed pieces with nothing to join them.

Fix: keep `Clips_Per_Edge` at `1` or higher.

### Clip tolerance must be non-negative

```scad
assert(Clip_Tolerance >= 0, "Clip tolerance must be >= 0");
```

Why: negative tolerance inverts male and female clearance, producing an
interference fit that cannot be assembled.

Fix: use `0` or a positive tolerance. Start at `0.2` and tune from a test print.

### Clip dimensions must be positive

```scad
assert(Clip_Tab_Width > 0 && Clip_Tab_Depth > 0 && Clip_Tab_Height > 0,
       "Clip tab dimensions must be > 0");
```

Why: zero or negative clip geometry yields invalid seam bodies.

Fix: set all clip dimensions above `0`.

### Seam tooth depth must be non-negative

```scad
assert(!Enable_Slicing || Seam_Tooth_Depth >= 0,
       "Seam_Tooth_Depth must be >= 0; use 0 for a flat seam");
```

Why: a negative depth has no meaning. `0` is the deliberate way to ask for the
flat seam that releases before 2.0.0-rc.6 used.

Fix: use `0` for a flat seam, or a positive depth. The default is `3`.

### Seam teeth must fit inside one slice

```scad
assert(!Enable_Slicing || Seam_Tooth_Depth + Clip_Tolerance < Slice_Width / 2, ...);
```

Why: a middle piece carries notches from both of its seams. Each notch reaches
`Seam_Tooth_Depth` plus half of `Clip_Tolerance` into the piece. Deeper teeth
from the two seams would meet and cut the piece apart. The lid's pieces are
slightly wider than the box's, so the box's pieces set the limit. The message
gives the largest depth that fits.

Fix: reduce `Seam_Tooth_Depth`, or reduce `Slice_Count` so each piece is wider.

### A sliced lid must be thick enough for its seam clips

```scad
assert(!Enable_Slicing || GF_Lid_Active || Lid_Height >= Clip_Tab_Height + SPACER, ...);
```

Why: a lid seam clip spans from `Lid_Height - Clip_Tab_Height` to `Lid_Height`,
sunk 0.04 mm below the slab's face. A thinner lid hangs the clip below the
print bed, so a slicer stands the piece on its clips. The sliced box floor had
the same fault until 2.0.0-rc.5. A lid-top Gridfinity plate lies under the slab
and holds the clip instead, so the check is off when that interface is active.
This closes backlog item 19 (lid seam clips below the bed).

Fix: raise `Lid_Height` to at least `Clip_Tab_Height` plus 0.04 mm (3.04 mm at
the defaults), or lower `Clip_Tab_Height`.

### Edge treatment cannot exceed the wall it cuts into

```scad
assert(Bottom_Edge_Fillet <= Wall_Thickness, ...);
assert(Top_Edge_Chamfer <= Wall_Thickness, ...);
```

Why: the floor and the rim are both `Wall_Thickness` deep. A fillet larger than
that breaches the floor from outside; a chamfer larger than that consumes the
rim the lid seats on.

Fix: reduce the treatment or increase `Wall_Thickness`.

There are two companions: `Bottom_Edge_Fillet + Top_Edge_Chamfer < Box_Height`
so the two treatments cannot meet in the middle of a short box, and
`Top_Edge_Chamfer * 2 < Lid_Height` because both lid faces are chamfered.

### Bottom edge style must be a known value

```scad
assert(Bottom_Fillet_Effective <= 0 || Bottom_Edge_Style == "Fillet" ||
       Bottom_Edge_Style == "Teardrop" || Bottom_Edge_Style == "Chamfer", ...);
```

Why: the style shapes the bottom edge, so an unknown value would leave the
shape undefined. Checked only when there is an edge to shape: a
`Bottom_Edge_Fillet` above `0` and no Gridfinity base. Every style is at most
`Bottom_Edge_Fillet` deep and tall, so the size limits above cover all three.

Fix: use `Fillet`, the default, `Teardrop`, or `Chamfer`.

### Lid relief must fit the lid

```scad
assert(Lid_Relief_Style != "Scallop" || Lid_Relief_Depth * 2 < Lid_Height, ...);
for (side = OPENING_SIDES)
    assert(!lid_relief_requested(side) || Lid_Relief_Width < wall_length(side) - Corner_Radius * 2, ...);
```

Why: a scallop is a half-cylinder groove, so its diameter is `Lid_Relief_Depth *
2` and a deeper one cuts through both faces of the lid. A relief wider than the
flat part of a wall runs into the rounded corners, where there is no flat face
to cut or build on.

The width check runs once per wall that has a relief turned on, against that
wall's own length: `Box_Width` for Front and Back, `Box_Depth` for Left and
Right. A long, narrow box can therefore carry a wide relief on its long walls.
The message names the wall, for example "Lid_Relief_Width must leave the
rounded corners alone on the Front wall".

Fix: reduce `Lid_Relief_Depth`, reduce `Lid_Relief_Width`, or reduce
`Box_Corner_Radius`.

### Magnet bosses must fit the cavity and clear the post

```scad
assert(!Enable_Lid_Magnets || Magnet_Boss_Diameter * 2 < min(Box_Width_Effective, Box_Depth_Effective) - Wall_Thickness * 2, ...);
assert(!Enable_Lid_Magnets || !Enable_Post || <boss and post do not overlap>, ...);
```

Why: four bosses at the inside corners need room to exist without meeting each
other across a small box, or swallowing the centre post. Both would render as a
silent merge rather than an error.

Fix: reduce `Lid_Magnet_Diameter` or `Lid_Magnet_Wall`, reduce `Post_Diameter`,
or enlarge the box.

Two depth rules go with them: the lid must keep `GF_MIN_FLOOR` of material above
its pocket so the magnet is captured rather than showing through the exposed
face, and the box pocket cannot be deeper than the wall is tall.

## Gridfinity

### A Gridfinity base excludes bottom openings and an open post

```scad
assert(!(Enable_Gridfinity_Bottom && Enable_Bottom_Openings), "... mutually exclusive ...");
assert(!Enable_Gridfinity_Bottom || !Enable_Post || Closed_Post, "... requires Closed_Post=true ...");
```

Why: the feet sit directly under the floor. They would cover any floor cutout,
and they would block an open post's bore, which runs through the floor.

Fix: turn off `Enable_Bottom_Openings`, and set `Closed_Post=true` or turn the
post off.

### The bridging layer height must be printable

```scad
assert(!(Enable_Gridfinity_Bottom && Enable_Gridfinity_Magnet_Screw) ||
       (Print_Layer_Height > 0 && Print_Layer_Height <= 0.6), ...);
```

Why: each of the two bridging steps above a foot's magnet pocket is one
`Print_Layer_Height` tall. Zero leaves the pocket's ceiling unbridged. The
0.6 mm ceiling is 75 percent of a 0.8 mm nozzle, the largest in common use.
Nothing else reads the value yet, so it is checked only with the feet's
magnets on.

Fix: set it to the layer height you slice at.

### A foot's magnet pocket must fit inside the foot

```scad
assert(!(Enable_Gridfinity_Bottom && Enable_Gridfinity_Magnet_Screw) ||
       (Gridfinity_Magnet_Depth > 0 &&
        Gridfinity_Magnet_Depth + 2 * Print_Layer_Height <= GF_BASE_HEIGHT), ...);
```

Why: each pocket is cut up from the foot's bottom face. Two bridging layers,
each `Print_Layer_Height` tall, sit above it, so the screw hole's ceiling
prints without supports. The pocket and both layers must stay inside the
4.75 mm foot, or they would cut up into the box floor. The message gives the
deepest pocket that fits: 4.35 mm at the default 0.2 mm layer.

Fix: reduce `Gridfinity_Magnet_Depth`. The default is `2.4`, the spec's depth.

## Clamped Values Rather Than Assertions

Not every out-of-range input deserves a hard stop. `Box_Corner_Radius` has an
obvious correct interpretation when it is too large, so the model clamps it and
reports what it did:

```scad
Max_Corner_Radius = max(0, (min(Box_Width_Effective, Box_Depth_Effective) - Wall_Thickness * 2) / 2 - 1e-6);
Corner_Radius     = min(Box_Corner_Radius, Max_Corner_Radius);
```

The ceiling comes from the **inner cavity**, not the outer shell. The same
rounding value is applied to the inner cuboid, which is `Wall_Thickness*2`
smaller on each axis, so a clamp derived from the outer half-extent lets values
through that BOSL2 then rejects with
`rounding radius must be smaller than half the cube width or length`.

When clamping occurs the model emits:

```
ECHO: "Box_Corner_Radius reduced from 40 to 35.65 (limited by the inner cavity at Wall_Thickness=1.85)"
```

A side opening whose top edge ends above the rim is reported the same way. Its
top edge is the wall's lift (`All_Openings_Up` plus `Move_Opening_*_Up`) plus
its height. Above `Box_Height`, the cut opens through the top of the wall as a
notch, and its upper corners are lost. That shape is legal, since a slot open
to the rim is a real use, so the model reports it and does not stop:

```
ECHO: "Front opening top edge at 65 mm is above Box_Height 50 mm; it is cut open to the rim as a notch"
```

An opening sized exactly to the wall stays quiet, because the check is strictly
above `Box_Height`.

A Gridfinity base rounds the footprint up rather than rejecting it. With
`Enable_Gridfinity_Bottom` on, the box's width and depth each become the
smallest `(N - 1) * 42 + 41.5` mm that is at least the typed value, which is the
outside of `N` spec feet. A box wider than its feet would overhang them, and on
a baseplate the neighbouring pockets fill the space under that overhang. The
model reports the size it built:

```
ECHO: "Gridfinity base: box footprint rounded up to 125.5 x 83.5 mm (3 x 2 cells) from Box_Width x Box_Depth = 100 x 75"
```

A footprint that is already a whole number of cells stays quiet.

Seam clip placement is corrected the same way. A clip whose center falls inside
the post opening has no material to bond to, so its position is pushed clear of
the opening rather than the render being rejected.

## Authoring Guidance for New Assertions

When adding new constraints:

1. Keep the condition narrow and user-actionable.
2. Make the message name the parameter the user typed, not the internal or
   library-level symbol it eventually breaks.
3. Gate the assertion on the relevant feature toggle (`!Enable_X || ...`) so a
   disabled feature never blocks a render.
4. Prefer clamping with an `echo` when the correct interpretation is obvious, and
   assert when it is not.
5. Document it here and in `docs/PARAMETER_REFERENCE.md` in the same commit.
6. Add a smoke scenario if it protects a failure mode that exits `0`.

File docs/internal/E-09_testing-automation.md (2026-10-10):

# E-09: Testing automation

**Handle:** Testing automation. Automated geometry regression testing beyond
compile checks.

**Status:** Shipped in v1.1.1 (2026-07-29). `tests/run_tests.py` and
`tests/scenarios.json` assert exit code, solid count, manifoldness, warning
cleanliness and point probes; 118 scenarios today, run in CI on every push.

**Effort:** M
**Depends on:** nothing. Should land before
[E-02 (BOSL2 migration)](E-02_bosl2-migration.md).

## The premise this doc pushes back on

The working assumption has been that each feature needs human smoke testing.
That is half right. Physical fit, tolerance, and print quality genuinely require
a human and a printer. But **the defects that actually shipped were all
machine-detectable**, and several were caught in this repo by numeric signals
rather than by looking at anything.

Of the five geometry bugs fixed in v1.1.0:

| Defect | Would a machine have caught it? | By what signal |
|---|---|---|
| Openings delivered half their height | yes | bounding-box or point-probe assertion |
| `Bottom_Openings_Count=0` detached the post | **yes** | solid-body count, and a `DEPRECATED` line nothing was reading |
| Corner radius clamp | yes | non-zero exit code across a parameter sweep |
| `Closed_Post` capped the wrong end | yes | point probe at two coordinates |
| Clip floated over the post bore | **yes** | solid-body count |

Every one exits `0` and produces a valid mesh. None would be caught by "does it
compile". Two of them are invisible in a render unless you already suspect them,
because a detached solid looks completely normal on screen. Those two are
arguably *harder* for a human to catch than for a machine.

## Test pyramid

**Tier 0: compiles and asserts.** What you have. Free. Catches nothing subtle.

**Tier 1: solid-body count.** Parse `Volumes: N` from OpenSCAD's CSG summary;
`N - 1` is the number of disconnected solids. Assert the expected count per
scenario. This alone catches the two worst v1.1.0 bugs, because both manifested
purely as an unexpected extra body. Cheapest high-value test available.

**Tier 2: clean-output assertion.** Fail if stdout contains `WARNING` or
`DEPRECATED`. The `Bottom_Openings_Count=0` bug announced itself with a
`DEPRECATED` range line for months and nothing was reading it.

**Tier 3: point probes.** Boolean-intersect the exported STL with a small cube
and assert material present or absent:

```scad
intersection() {
  import("out.stl", convexity=10);
  translate([x, y, z]) cube([dx, dy, dz]);
}
```

An empty top-level object means no material. This is a precise geometric
assertion needing no mesh library, and it is how `Closed_Post` and the opening
extents were pinned down. Two cautions learned the hard way:

- OpenSCAD on Windows is a native binary and cannot resolve MSYS-style `/tmp`
  paths in `import()`. Use native paths or the test silently passes on an
  empty import.
- Size the probe smaller than the feature. A probe wide enough to clip a
  rounded corner reports material and reads as a false negative.

**Tier 4: bounding box and volume.** Parse the STL for min/max per axis, and
compute mesh volume via the signed-tetrahedron sum. Catches whole-model scaling
errors and "the cut removed twice as much as it should" without knowing where
to probe. `numpy-stl` or `trimesh` if you want a dependency; roughly 30 lines of
Python if you do not.

**Tier 5: manifold and watertightness.** `admesh` or `trimesh.is_watertight`.
Catches meshes a slicer will reject.

**Tier 6: normalised golden geometry.** For refactors that must not change
output, compare the **sorted multiset of coordinates**, not a file hash.

> Do not hash STL files. The same input rendered three times produced three
> different SHA-256 hashes at identical byte length, because OpenSCAD's ASCII
> STL facet ordering is not deterministic between runs. Extracting all numeric
> tokens, sorting them, and hashing that is stable and was used to prove the
> v1.1.0 fixes were geometry-neutral at defaults.

**Tier 7: visual regression.** Render to PNG and perceptually diff against
goldens. Catches what nothing else does, but brittle across OpenSCAD versions
and colour schemes. Lowest priority; consider it a reviewer aid rather than a
gate.

## What still needs a human

- Fit and tolerance: lid engagement, clip snap force, magnet seating.
- Printability: overhangs, bridging over openings, warping, elephant foot.
- Aesthetics.
- Real-world function: does the cable bundle actually fit and route.

Everything else should be a gate in CI. The right split is that a human tests
the *physical* claims once per release, and the machine tests the *geometric*
claims on every push.

## Proposed implementation

A `tests/` directory with a scenario matrix as data, not code:

```
tests/
  scenarios.json        # {name, defines[], expect: {rc, solids, bbox, probes[]}}
  run-tests.sh          # renders each scenario, evaluates expectations
  golden/               # normalised geometry fingerprints for refactor guards
```

Run in CI on push and pull request. Keep it data-driven so adding a scenario is
a JSON entry, not a new script.

## Acceptance criteria

- [ ] Every parameter has at least one boundary scenario (0, 1, max, max+1).
- [ ] Every enum value of every enum parameter is rendered at least once.
- [ ] Solid-body count asserted for all scenarios.
- [ ] Build fails on `WARNING` or `DEPRECATED` in OpenSCAD output.
- [ ] The five v1.1.0 defects each have a regression scenario that fails against
      the v1.0.0 model and passes against current.
- [ ] `scad-smoke` runs on `pull_request`, not only `push`.
- [ ] Test runtime stays under about 5 minutes.

## Note on the existing workflow

`scad-smoke.yml` filters on `paths: ["**/*.scad", ...]`, so a change to the test
scripts themselves does not trigger it. Add `tests/**` and `scripts/**`, or drop
the filter.

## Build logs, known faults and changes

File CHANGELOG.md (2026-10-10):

# Changelog

All notable changes to this project will be documented in this file.

The format follows [Keep a Changelog](https://keepachangelog.com/en/1.1.0/),
and this project adheres to [Semantic Versioning](https://semver.org/spec/v2.0.0.html).

## [Unreleased]

### Added
- **Edge treatment.** `Bottom_Edge_Fillet` rounds the box's outer bottom edge
  and `Top_Edge_Chamfer` chamfers the box's top rim and both exposed lid edges.
  Every horizontal edge was previously a hard 90 degrees, which is the largest
  visible gap between this and a commercial enclosure; the bottom fillet also
  absorbs elephant foot visually. Both default to `0`, and at `0` the code takes
  the same `cuboid()` path it always has, so an untreated model is unchanged by
  construction rather than by comparison. Non-zero, the shell switches to BOSL2
  `offset_sweep()`, which resolves how a horizontal fillet meets the vertical
  corner radius. Suppressed automatically wherever a Gridfinity interface owns
  the face, because those profiles are dimensioned by the standard.
- **Lid removal relief.** `Lid_Relief_Style` takes `Scallop` (a concave groove)
  or `Tab` (a protruding grip), placed by `Lid_Relief_On_Left/Right/Front/Back`
  mirroring the existing `Opening_On_*` block, and sized by `Lid_Relief_Width`
  and `Lid_Relief_Depth`. A friction-fit lid otherwise has nothing to grip.
  A side is skipped
  automatically when an opening on that wall reaches the rim, which is the only
  case where the lid feature and the box feature meet. Defaults to `None`.
- **Magnetic lid retention.** `Enable_Lid_Magnets` cuts mating pockets in the
  box and lid, held in bosses at the four inside corners. Corners rather than
  the rim because the rim is only `Wall_Thickness` wide and a 6 mm magnet does
  not fit it, and because corners are free of openings, stabilizers, the post
  and slice seams by construction rather than by avoidance logic. The four
  positions are symmetric in both axes, so they align however the lid is flipped
  onto the box. Bosses run the full box height so they print off the bed instead
  of hanging off the rim. `Lid_Magnet_Diameter` defaults to 6.2 for a nominal
  6 mm magnet. Asserts when
  the boss will not fit the cavity or would touch the post. Defaults to off.

  Magnets must be inserted with opposing poles facing. Symmetric geometry cannot
  enforce that.

All four features default to a state that leaves existing geometry unchanged.
Nine regression scenarios cover them, including that the defaults render
identically and that magnets survive slicing.

- **Release automation.** Pushing a `v*` tag runs `.github/workflows/release.yml`.
  It runs the version check, the geometry suite, and the standalone-bundle
  render, then drafts a GitHub release for review rather than publishing one.
  `scripts/package_release.py` builds the assets reproducibly, and
  `scripts/release_notes.py` writes the notes from this file. A final tag is
  refused while `[Unreleased]` still has entries.
- **Every release attaches all nine presets** as `cable-box-presets.zip`.
  Releases up to `v2.0.0-rc.3` carried only a few hand-picked sample STLs.
- **Options guide section for the finishing features**: the bottom fillet, the
  top chamfer, both lid reliefs, and the magnet bosses.

- **`Lid_Style` chooses how the lid locates.** `Plug`, the default, drops a
  ring just inside the box wall and leaves the lid's edge overhanging as a
  finger grip. The ring is notched around the magnet bosses, and the model
  asserts when stabilizer fins or the post would reach it, or when the box is
  too small to hold it. `Skirt` wraps a wall around the outside of the box and
  has none of those limits. Both styles fitted well in the rc.5 test prints.

  The Plug default is stricter about fins than a Skirt: they must stop
  `Lid_Lip_Gap_Height` below the rim, even when only the box is rendered. At
  the defaults that caps `Stabilizer_Height` at `Box_Height - 4.85`. The
  defaults and all nine presets are well inside it. Set `Lid_Style=Skirt` for
  fins that reach the rim.

- **`Seam_Tooth_Depth` cuts sliced seams as a 45 degree sawtooth.** Above the
  floor, each seam zigzags through the walls, the post, and any fin it crosses,
  so joined pieces cannot slide vertically and their rims meet flush. The teeth
  have no undercut, so the pieces still push together the way the floor clips
  go in, and every tooth face prints without support. The default is `3` mm;
  `0` restores the flat seam exactly. Where a front or back opening crosses a
  seam, the teeth skip its height range, so they never leave slivers against
  its rounded edges. See
  [E-13 (seam joints)](docs/internal/E-13_seam-joints.md).
- **`All_Opening_Top_Style` gives side openings a top that prints without
  support.** `Round`, the default, keeps today's arcs, which flatten near the
  top and print there as an overhang. `Teardrop` turns each rounded top corner
  into a 45 degree flank with a short flat cap. The cap sits where the round
  top was, so every opening keeps its typed width and height, and the rim,
  lid-relief and seam-teeth checks that read an opening's top are unaffected.
  Square openings are unchanged. One setting covers all four walls. See
  [E-14 (printability options)](docs/internal/E-14_printability-options.md).
- **`Bottom_Edge_Style` shapes the bottom edge treatment.** `Fillet`, the
  default, is the quarter round that `Bottom_Edge_Fillet` has always made, and
  its lowest layers overhang the bed. `Teardrop` keeps the rounded look but
  finishes in a 45 degree chamfer at the bed. `Chamfer` is a plain 45 degree
  bevel. `Bottom_Edge_Fillet` sets the size for every style, and the setting
  shapes only the box's bottom edge, never the lid's.
- **`Print_Layer_Height` sizes the Gridfinity bridging layers.** The two
  stepped layers above each foot's magnet pocket were fixed at 0.2 mm. A
  slicer samples each layer near its middle height, so at a thicker layer a
  0.2 mm step can be skipped and the pocket's ceiling sags. Set it to the
  layer height you slice at. The default `0.2` reproduces the earlier steps
  exactly, and `Gridfinity_Magnet_Depth` may now reach
  `4.75 - 2 * Print_Layer_Height`.

### Changed
- **A Gridfinity base rounds the box up to whole cells, and its feet follow the
  spec.** With `Enable_Gridfinity_Bottom` on, `Box_Width` and `Box_Depth` each
  become the smallest `(N - 1) * 42 + 41.5` mm that holds the typed value, and
  the model echoes the size it built. The default 100 x 75 box becomes
  125.5 x 83.5, a 3 x 2 grid, and the lid grows with it. The
  `gridfinity-module` preset now types its 3 x 2 footprint exactly, 125.5 x
  83.5 instead of 140 x 100, which would have rounded up to 4 x 3. Each cell
  gets one solid foot swept along the spec's 0.8 / 1.8 / 2.15 mm profile. Where
  the box corner is rounder than a foot's 3.75 mm corner, the corner feet are
  trimmed to the box's outline. `Gridfinity_Edge_Keepout` now applies only to
  the lid top. `Gridfinity_Magnet_Diameter` defaults to `6.25`, so the pocket
  with its clearance is the spec's 6.5 mm. See
  [E-12 (Gridfinity to spec)](docs/internal/E-12_gridfinity-to-spec.md).
- **`Lid_Lip_Gap` is now a clearance on each side, and defaults to `0.15`.**
  It was added once to the lid's overall width, which made it a total. The
  same value now separates the lip from the wall on every side, for both lid
  styles, and also opens up the lid's post socket. The lid's footprint is
  `Box + 2*(Wall_Thickness + Lid_Lip_Gap)`, so the default lid is 104 x 79 mm
  instead of 103.8 x 78.8. The rc.5 test prints confirmed `0.15` for both lid
  styles, with and without magnets, on a Bambu Lab P1S printing PLA+. No preset
  sets `Lid_Lip_Gap`.
- **`All_Openings_Up` now defaults to `5` instead of `0`.** Side openings are
  anchored at their bottom edge, so every enabled side opening now sits 5 mm
  above the box floor instead of flush with it. Set `All_Openings_Up=0` to
  restore the previous output.

  This changes geometry for unchanged inputs, which under
  [E-10 (versioning)](docs/internal/E-10_versioning.md) is a **major** bump
  rather than the minor one the features above would have been. No preset sets
  `All_Openings_Up`, so all nine inherit the new value and every preset STL and
  GLB shifts with it. A print made from `v2.0.0-rc.2` no longer matches what the
  model produces from the same parameters.
- **Calibration coupons no longer ship.** `v2.0.0-rc.4` attached them as
  `cable-box-calibration.zip`, built from a `calibration/` folder. They are now
  maintainer tooling outside the repository. `docs/PRINTING.md` describes a fit
  test box made from your own settings instead. Their two print rounds found
  the lid and floor-clip defects fixed below, and confirmed both fixes.
- **The code inherited from the 2022 original is rewritten.** Side openings
  are placed by one loop over the four walls instead of four copied blocks.
  The lid's post socket and the part layout use named values, and the override
  check names the wall at fault. Every preview colour is now a named constant.
  Geometry is unchanged, proven by canonical mesh hash across twelve
  configurations rather than by inspection. `THIRD_PARTY_NOTICES.md` now
  records where the earlier versions came from.
- **README.** It leads with the preset library, and its options-guide links go
  to the site, because GitHub shows a `.html` file as source. A fourth feature
  image shows the finishing features. The Gridfinity text no longer promises a
  fit that no print has confirmed yet, and print reports are now the first
  contribution it asks for.
- **CI.** The docs site now builds, without deploying, on every pull request,
  so a dependency break shows up in review rather than at deploy time.
  Dependabot proposes grouped monthly updates for the site and the workflows,
  and holds back `three` until `@google/model-viewer` accepts a newer version.
- **New preview palette.** Teal, red and yellow become slate with an orange
  post. This changes the OpenSCAD preview and every generated PNG render;
  STLs carry no colour. The README's hero and feature images are now
  rendered by `scripts/build_readme_images.py` instead of by hand, which
  also corrects two that had drifted: the Gridfinity image still showed the
  retired lid studs, and the hero showed openings flush with the floor.

### Fixed
- **The lid fits the box.** In every version from v1.0.0 to v2.0.0-rc.4,
  including v1.4.1, the lid's lip ring was sized to land on top of the box
  wall: on a 50 mm box it spanned 48.25 to 50.10 mm against a wall from 46.30
  to 50.00. The lid stood on the rim instead of fitting, which the rc.4
  `lid-fit` coupon confirmed by stacking 19 mm instead of 16. The lip is now a
  plug inside the wall by default, or a skirt around it (see `Lid_Style`
  above). The suite never caught it because it rendered one part at a time;
  `tests/assembly/lid_seated.scad` now seats the lid on the box and asserts
  that the two do not overlap. This changes the lid for unchanged inputs, a
  **major** change under [E-10 (versioning)](docs/internal/E-10_versioning.md),
  and every preset's lid changes with it.
- **The lid's post socket has clearance.** Its bore was exactly
  `Post_Diameter`, a zero-clearance fit that no lid reached while the lip held
  it off the rim. It now takes `Lid_Lip_Gap` on each side, and the sleeve
  around it grows to match.
- **The Gridfinity base fits a standard baseplate.** Each cell was a
  square-cornered 41.5 mm block whose corners reached 29.35 mm from the cell
  centre, where a baseplate pocket's rounded corner reaches only 28.04, so the
  base could not enter one. It was also hollowed from below with a 37 mm bridge
  in every cell, and the box overhung it with a flat ledge that printed as
  loose loops. Its magnet and screw holes cut only the hollow's 0.45 mm
  ceiling, so they held nothing. The feet are now solid and print without
  supports (see "A Gridfinity base rounds the box up" above). Magnet pockets are
  cut up from each foot's bottom, 6.5 x 2.4 mm, with two stepped bridging
  layers so the screw hole's ceiling prints. `Gridfinity_Magnet_Depth` beyond
  4.35 mm is now rejected instead of silently capped.
  `tests/assembly/gridfinity_seated.scad` seats the feet in a baseplate built
  from the spec's own numbers and asserts that they do not overlap it. This
  changes every box with the base on, a **major** change.
- **Sliced pieces sit on their floor (F-51).** Each floor clip was centred on
  the floor, so a 3 mm clip in a 1.85 mm floor hung 0.575 mm below the piece. A
  slicer stands the part on its lowest point, which left the floor and walls in
  the air on the clip footprints alone: the rc.4 tab-clip coupon's first layer
  was exactly the two clips' 80 mm². Clips now start at the floor's bottom face
  and keep their full height, rising inside the box instead. This changes
  every sliced box piece, another **major** change.
- **Sliced pieces stay level once joined.** With either clip style, the halves
  of a sliced box could slide vertically against each other, and their rims
  did not meet flush in the rc.5 test prints. Each floor clip's socket runs
  through the floor, so nothing on the seam resisted vertical movement. The
  seam teeth from `Seam_Tooth_Depth` (see above) now lock it. This changes
  every sliced box and lid piece for unchanged inputs, a **major** change.
  `tests/assembly/slices_joined.scad` joins two pieces and asserts that they
  collide when one is moved 0.5 mm up or down.
- **A sliced lid too thin for its seam clips is rejected.** A lid seam clip
  hung below the print bed when `Lid_Height` was less than `Clip_Tab_Height`,
  the same fault the floor clips had. The model now asserts and names
  `Lid_Height`, unless a lid-top Gridfinity plate lies under the clip.
- **Lid relief over a raised opening.** The check that drops a relief above an
  opening reaching the rim counted only `All_Openings_Up`. An opening raised to
  the rim by its own `Move_Opening_*_Up` still got a tab standing over it. The
  check now uses the opening's real top edge.
- **Relief width on long, narrow boxes.** `Lid_Relief_Width` was checked
  against the shorter of `Box_Width` and `Box_Depth` for every wall, so a
  150 mm wall rejected a 100 mm relief because the box was 60 mm wide. Each
  enabled wall is now checked against its own length, and the message names
  the wall.
- **Openings lifted past the rim are reported.** An opening whose top edge ends
  above `Box_Height` is cut open to the rim as a notch. That is still allowed,
  but it used to happen without any message; the model now prints one.
- **Closed boxes shallower than the default opening.** `All_Opening_Height`
  was checked against `Box_Height` even with every side opening off, so a
  12 mm box with closed walls was rejected for a 30 mm opening it never cuts.
  The check now applies only when a side opening is on.

Five regression scenarios cover the four fixes from the lid relief onward,
and each fails against the previous model. The lid, post socket and floor clip
changes, together with `Lid_Style`, add eleven scenarios and update eight, and
all nineteen fail against rc.4. The seam teeth and the thin-lid check add
thirteen scenarios. Nine fail against rc.5. The other four guard the fit of
joined box and lid pieces, the middle piece of a three-piece box, and the flat
seam that `Seam_Tooth_Depth=0` keeps.

- **Sliced preset sizes.** `surge-strip-6-sliced` reported 270 mm, the width
  of the preview layout with both halves side by side. It now reports the
  assembled box (265 mm) and the largest printed piece (136 mm) separately, in
  `library/index.json` and on the site. The site's printer-bed filter checks
  that piece instead of passing every sliced preset regardless of bed size.
- **Docs site links and metadata.** Canonical links, `og:url` and the sitemap
  pointed at the `github.io` address, which only redirects to
  `projects.prisantlabs.com`. Each page now also has its own meta description,
  and the preset filter and tables follow the theme and fit a phone screen.
- **Docs site dependencies.** `npm audit fix` cleared the critical Astro
  advisory, and Starlight 0.42 plus one more in-range fix cleared the five
  high ones that sat behind it. `npm audit` now reports no vulnerabilities.
  The workflows use `upload-artifact` v7 and `download-artifact` v8.
- **Tooling.** The test harness wrote Windows paths with backslashes into the
  `.scad` it uses for point probes, where a backslash is an escape, so a run
  from PowerShell reported false probe failures. A hung render now fails its
  own scenario instead of the whole run, and `SCAD_TEST_TIMEOUT` sets the
  limit. The options guide and the bundle header printed the model version as
  "unknown", because they searched only the top of the file. Generated files
  are written with LF line endings on Windows, and the maintenance scripts run
  on macOS. `scripts/package_release.py` now imports the `NoReturn` it
  annotates with.
- **Lid magnet wording (F-54).** The FAQ and the parameter reference said "a
  4.8 mm magnet sits flush", which read as one magnet spanning both halves.
  They now say what the pockets take: one magnet per pocket, up to 2.4 mm
  thick.

## [2.0.0] - 2026-08-07

Major release, because `Enable_Gridfinity_Lid_Top` now renders different
geometry from the same parameter set. Under
[E-10 (versioning)](docs/internal/E-10_versioning.md) that is a major bump even
though the new geometry is the one the parameter always claimed to produce.

**Not yet print-validated.** The Gridfinity socket clearances and the lid clip
placement are arithmetic, not measurements. E-10's flow for this state is a
`v2.0.0-rc.1` prerelease with STLs attached, so the print test has a citable
artifact; the date above belongs to the final release and should be corrected
when it ships.

### Added
- **A preset browser on the docs site**, at `/library/`. A card grid filterable
  by printer bed size and by feature, and a page per preset with an orbitable
  3D view of each part, the parameters that define it, and downloads. Cards use
  the fixed-camera render, so the grid reads as a size comparison rather than
  nine models each zoomed to fill its own frame.
- **`library/index.json`**, the machine-readable twin of `library/README.md`:
  every preset with its overrides, printed envelope, feature flags, and file
  paths, plus the model's full parameter defaults once at the top. It carries a
  schema version, and like the README it always covers every preset even when
  `--only` rebuilt one.
- **A GLB beside every library STL**, converted at build time by
  `scripts/build_library.py`, for 3D preview in a browser. About a tenth the
  size: the 481 KB `gridfinity-module` box-and-lid becomes 51 KB. The mesh is
  canonicalised before export, which is not cosmetic: OpenSCAD emits identical
  geometry in a different facet order every run, so a straight conversion
  produced 27 changed binaries on every rebuild and a canonical one produces
  zero. `trimesh` is an optional dependency; without it the GLBs are skipped
  and the rest of the build is unaffected.

### Changed
- **BREAKING: `Enable_Gridfinity_Lid_Top` now produces sockets, not studs.**
  Under [E-10 (versioning)](docs/internal/E-10_versioning.md) this is a major
  bump, because the same parameter set renders different geometry.

  The lid inverts in use: its lip is the mating face, so the panel's other side
  is the exposed top of a closed box. The previous implementation added a
  two-stage stud to that face, which meant a closed box carried Gridfinity feet
  pointing at the ceiling. Nothing can rest on a foot. The feature's own
  documentation described a baseplate, so the code and the docs had disagreed
  since the feature shipped.

  It is now a 4.75 mm plate spanning the lid, with a mating socket cut into each
  cell, so a Gridfinity bin or another box drops onto the closed lid.

  The socket mouth is sized from the widest part of a foot (`GF_BASE_CELL`,
  41.5 mm) plus clearance, not from `GF_CAVITY_ENTRY_SIZE`. That constant is
  39.4 mm and describes the cavity hollowed *into* the box base, which is the
  inside of the male half; a mouth that size held every part 1.85 mm proud.
  Verified: the model's own base fits with 0.25 mm clearance, and a standard bin
  foot seats on the shoulder at 3.2 mm depth.

  Lid height with the feature on goes from 4.5 mm to 4.75 mm added. Constants
  `GF_LIDTOP_BASE_HEIGHT`, `GF_LIDTOP_TOP_HEIGHT`, `GF_LIDTOP_BASE_SIZE` and
  `GF_LIDTOP_TOP_SIZE` are replaced by `GF_LIDTOP_PLATE_HEIGHT`.

  **Still unvalidated by print.** Nothing here has been fitted to physical
  Gridfinity hardware. The clearance is a number, not a measurement.

### Fixed
- **Lid magnet pockets were unusable and are now magnet-only.** (Found by
  adversarial review.) The pocket cut still started at the lid-panel interface
  as in the stud era, so it overlapped the socket void and left a 0.45 mm
  pocket: a 2.4 mm magnet glued there stood proud into the socket and held
  every foot off the floor. Pockets now open at each socket floor and reach
  into the lid panel, keeping `GF_MIN_FLOOR` of panel above them. The screw
  hole and counterbore are gone from the lid entirely: a baseplate's screws
  fasten it to a surface, and here that surface is the sealed lid, so a
  through hole would breach the closed box. The bottom base keeps its screw
  holes. Regression probes assert the pocket void and the solid panel above.
- **Slicing a lid shorter than the Gridfinity plate left a full-width layer on
  every piece.** (Found by adversarial review.) The slice cutters were sized
  from `Lid_Height` alone, and the plate hangs `Gridfinity_Lid_Offset` below
  z=0, so at the legal `Lid_Height=4.6` each cutter stopped 0.15 mm short:
  piece 1 measured 103.8 mm wide instead of ~52, defeating the small bed that
  slicing exists for. Both lid and box cutters now span an explicit envelope
  from below the Gridfinity offset to above the lip. Regression asserted by
  bounding box, and the box cutter fix closes the same latent gap for boxes
  shorter than twice the base height.
- **`build_library.py --only` truncated the public preset index.** (Found by
  adversarial review.) The README was rewritten from only the presets in the
  filtered build, so one `--only gridfinity-module` run shipped an index
  listing a single preset while eight valid ones sat beside it on disk. The
  index now always covers every preset, reading dimensions from the on-disk
  STL for presets not rebuilt in that run.
- **Point probes can no longer return a verdict from a broken mesh.** A CGAL
  assertion inside a probe intersection still prints "top level object is
  empty", so a degenerate exported mesh read as a confident "empty" at every
  point. The test harness now raises on CGAL errors instead. The sliced-lid
  export was the mesh that exposed this; that degeneracy is fixed below, and
  the scenario probes it again.
- **Sliced lid pieces exported four zero-area triangles.** The lid's seam clip
  was placed with its top face exactly flush with the top of the lid panel
  (`z_pos = Lid_Height - Clip_Tab_Height/2` on a centred cube puts the top at
  exactly `Lid_Height`). Flush, the clip's top and the panel's top are one
  coplanar face, so on the slice seam the clip's corners became extra collinear
  vertices along an otherwise straight edge, and OpenSCAD's tessellator fanned
  across them into slivers. Measured on every sliced lid configuration: four
  such triangles with Tab clips, eight with Snap, none anywhere else, and none
  on any box piece or unsliced lid. Slicers tolerated them; CGAL did not, so
  every point probe against an exported sliced lid raised instead of answering.
  The clip is now sunk by `SPACER` (0.04 mm, the constant this codebase already
  uses to break tangency). Male and female clips share that offset, so the fit
  is unchanged, the part envelope is unchanged, and 0.04 mm is a fifth of a
  typical layer. Verified: zero degenerate triangles across Tab, Snap, thin
  lids and the Gridfinity plate, and the regression now asserts by probe.
- **Rebuilding the library no longer reports every render as modified.**
  OpenSCAD rasterises through OpenGL, so pixels along polygon edges land
  differently between runs: two renders of an identical model differ by up to
  993 bytes of 2,250,750, invisible to the eye but not byte-equal. Git compares
  bytes, so every rebuild dirtied images that had not changed, and real changes
  were indistinguishable from noise. `scripts/build_library.py` now compares a
  new render against the existing file and keeps the old one when they are the
  same picture. The threshold sits in the gap between measured noise (up to 993
  bytes) and the subtlest real change (a 0.5 mm dimension shift moves 11,508),
  and the measurements are recorded beside it. The build reports how many
  renders it wrote versus left alone.
- `docs/WORKFLOWS.md` told contributors to add presets to `library/` by hand.
  Everything in that directory is generated and hand-added files are overwritten
  on the next build.

### Changed
- **Docs site rebuilt on Astro Starlight, replacing MkDocs.** Same URL, same
  page set, same nav structure. The site lives in `web/` and syncs its content
  from `docs/` at build time (`web/sync-docs.mjs`), so `docs/` remains the
  single source of truth: README links keep working, GitHub browsing keeps
  working, and `build_options_guide.py` keeps generating into the same place.
  Page URLs changed from uppercase (`/PARAMETER_REFERENCE/`) to kebab-case
  (`/parameter-reference/`); old deep links 404. `mkdocs.yml` is gone, its nav
  now lives in `web/astro.config.mjs`, and the Pages workflow builds with Node
  instead of Python. The offline `options-guide.html` is served unchanged. The
  landing page's stale claim that Gridfinity was developed outside this
  repository is corrected.
- `docs/RELEASE.md` rewritten from a seven-line checklist to the actual release
  process: which of the three generated artifacts embed `Model_Version`, the
  version consistency check, the standard release assets, and the snapshot step.
- `docs/FAQ.md` gains preset-loading instructions and the recovery note for the
  1.4.0 `config.json` type error.
- `docs/WORKFLOWS.md` quick start covers starting from a preset.
- `README.md` and `docs/DOCS_INDEX.md` document `cable-box-parametric.json`.

## [1.4.1] - 2026-08-04

Bugfix release. The model itself is untouched, so geometry is unchanged and the
STLs in `library/` are byte-identical to 1.4.0. What changed is the preset
metadata and the preview renders around it.

### Fixed
- **Preset `config.json` files were rejected by OpenSCAD outright.** Booleans
  were written capitalised (`"True"`), where the Customizer parameter-set format
  requires `"true"`. Loading such a set fails with
  `Cannot apply Parameter Set 'conversion of data to type "b" failed'`, and
  OpenSCAD then discards the *entire* set rather than skipping the offending
  key. That made `gridfinity-module`, `surge-strip-6-sliced` and
  `under-desk-passthrough` unusable through the `-p` / `-P` invocation that
  `library/README.md` documents. The STLs were never affected, because the
  render path lowercased booleans correctly; only the JSON path was wrong, and
  nothing exercised it.
- **Preview renders hid the difference between presets.** Images were rendered
  with `--viewall`, which zooms each model to fill the frame and therefore
  discards scale. Five of the nine presets differ only in dimensions, so a
  265 mm surge strip and a 120 mm charger were drawn the same size. The
  `box-and-lid` view now renders every preset at one fixed camera distance, so
  the library reads as a size comparison. Detail views keep fit-to-frame, where
  only shape matters.
- **Release snapshots recorded the wrong commit.** `scripts/backup-release.sh`
  used `git rev-parse <tag>`, which returns the annotated tag object rather than
  the commit it wraps, so every `MANIFEST.txt` stored a tag SHA in a field
  labelled `commit:`. Snapshot contents and checksums were correct throughout.

### Added
- **`cable-box-parametric.json`**, one parameter-set file beside the model
  carrying all nine presets. OpenSCAD's Customizer offers the full list when the
  model is opened, and `-p cable-box-parametric.json -P <preset>` selects one
  from the command line. It is generated from the same table as the per-preset
  files, so the two cannot disagree.

## [1.4.0] - 2026-08-03

Completes E-02 (BOSL2 migration) phases 2 and 3. Geometry is unchanged at
default settings: mesh volumes match 1.3.0 exactly across box, lid, both,
Gridfinity bottom, Gridfinity lid, and slicing.

### Added
- **Snap-fit seam clips.** `Clip_Style` adds `"Snap"`, a BOSL2 `rabbit_clip`
  cantilever joint, alongside the original `"Tab"`. The tab is a rectangle in a
  slightly larger hole held by friction; the snap has an engagement bump and an
  arm that flexes, so it absorbs print inaccuracy instead of jamming.
  Tuning parameters: `Clip_Snap_Length`, `Clip_Snap`, `Clip_Arm_Thickness`,
  `Clip_Compression`, `Clip_Lock`.
  **The default remains `"Tab"`** until a print validates the snap geometry.
  Clip correctness cannot be established by rendering: manifoldness, solid
  counts, and probes all pass for a joint far too tight to assemble or too loose
  to hold.
- **Attachment interface.** `m_box()` and `m_lid_part()` expose the box and lid
  as BOSL2 attachables with named anchors: `floor`, `rim`, `wall-front`,
  `wall-back`, `wall-left`, `wall-right`, `post-top`, `lid-face`, `lip`.
  `lid-face` names the face that ends up exposed when the box is closed, which
  is the thing v1.2.0's Gridfinity lid interface got wrong.
- **Library mode.** `Render_On_Include=false` suppresses the auto-render so the
  file can be included and composed against.
- **A missing-dependency guard.** Without BOSL2 the model previously produced
  "Can't open include file", a wall of unknown-module warnings, no geometry, and
  **exit code 0**, which looks like success. It now fails with one message
  naming what to install and pointing at the standalone bundle.
- `scripts/bump-bosl2.sh` makes moving the pinned BOSL2 version a verified act:
  renders nine scenarios against old and new refs, compares mesh volumes, runs
  the suite, and refuses to apply on any change.

### Fixed
- Snap clips did not overlap their slice. The existing offsets assume a centred
  cube; a `rabbit_clip` is base-anchored and grows away from the slice, so the
  pin was left floating with nothing to bond to.
- Preview layout now accounts for clip protrusion. An 8 mm snap pin crossed the
  default 5 mm preview spacing and fused the all-slices preview into one body.
  `"Tab"` previews are unchanged.

### Testing
- 65 scenarios, up from 48. Adds bounding-box assertions, `output_contains`, and
  per-scenario source files for anchor and fixture tests.
- The harness now reports which BOSL2 version OpenSCAD actually loads, before
  any scenario runs. This exists because a full green local run turned out to be
  testing a different library than CI: on Windows, `~/Documents` is redirected to
  OneDrive, so a clone into that literal path went somewhere OpenSCAD never looks
  while a stale copy kept being loaded. That masked the clip-overlap bug above.

## [1.3.0] - 2026-07-31

Replaces the embedded BOSL2 copy with a real dependency. Dimensionally identical:
mesh volumes match the previous release to four decimal places across every
configuration tested, with only corner-rounding tessellation differing.

### Changed
- **BOSL2 is now a dependency, not embedded.** The model declares
  `include <BOSL2/std.scad>`. This removes a single 214,500-character line that
  was 79 percent of the file and froze the project on a February 2022 snapshot;
  CI pins BOSL2 2.0.747. The model file drops from 271 KB to 72 KB and is
  reviewable, diffable, and searchable for the first time.
  - MakerWorld's parametric customizer bundles BOSL2, so this also makes the
    model publishable there. A local `lib/` split would not have been, since
    MakerWorld forbids custom library uploads.
  - Local users install BOSL2 once; see the README. Releases attach a standalone
    bundle for anyone who would rather not.

### Fixed
- **The lid was relying on coplanar-face fusion.** Its lip ring and post collar
  both met the lid panel on a shared plane with zero overlap. Whether such a
  pair fuses into one body is kernel-dependent: the 2022 BOSL2 fused them, the
  current one does not, so the lid exported as three detached solids. Both now
  overlap into the panel by a `WELD` allowance. The same applied to the
  Gridfinity base and lid profile.

  This was a latent defect, not a migration regression. Any BOSL2 or CGAL change
  could have triggered it, and it would have shipped a lid in three pieces
  without a single error message. Caught by the geometry suite's
  disconnected-solid assertion.

### Added
- `scripts/build_bundle.py` produces a standalone model with BOSL2 inlined,
  verified in CI to render with no library installed.
  - The bundle is two files: the model plus `builtins.scad`. That file cannot be
    inlined. BOSL2 pulls it in with `use` rather than `include` because it wraps
    OpenSCAD's builtins (`module _translate(v) translate(v) children();`).
    `use` scopes it so `translate` resolves to the builtin; inlining it makes
    the body resolve to BOSL2's own `translate`, and the two recurse forever.
- CI installs a pinned BOSL2, builds the bundle, and verifies the bundle renders
  with BOSL2 moved out of reach.

## [1.2.0] - 2026-07-30

Adds optional Gridfinity interfaces. Geometry with both toggles off is
byte-identical to 1.1.1, verified by normalised STL comparison across all three
`Part_To_Render` modes.

### Added
- **Gridfinity base under the box** (`Enable_Gridfinity_Bottom`). Adds a 42 mm
  grid of base cells with the two-stage mating cavity so the box drops into a
  standard Gridfinity baseplate.
- **Gridfinity profile on the lid** (`Enable_Gridfinity_Lid_Top`). Puts the
  interface on the lid's exposed face so the closed box participates in a
  Gridfinity stack.
- Optional magnet pockets and screw holes on both interfaces
  (`Enable_Gridfinity_Magnet_Screw`), keeping `GF_MIN_FLOOR` of material between
  a pocket and the box floor.
- `Gridfinity_Profile_Clearance` and `Gridfinity_Edge_Keepout` for fit tuning.
- Assertions: Gridfinity bottom conflicts with bottom openings, and requires
  `Closed_Post` because the base would otherwise block an open post bore.
- Nine Gridfinity test scenarios, including probes that confirm the mating
  cavity is actually cut and that a box too small for one cell does not float.

### Added (tooling and content)
- **Preset library**: nine generated presets in `library/`, covering a compact
  desk tidy through a six-outlet surge strip split for a 180 mm bed. Each ships
  a complete `config.json`, STLs, renders, and notes.
- `scripts/build_library.py` generates all of it from a data table, so presets
  cannot drift from the model the way the hand-made v1 artifacts did.
- **Visual options guide**: `docs/options-guide.html`, a self-contained page with
  43 renders embedded as data URIs that works offline, plus a Markdown companion
  at `docs/OPTIONS_GUIDE.md`. Generated by `scripts/build_options_guide.py`.
- `scripts/backup-release.sh` snapshots a release (mirror clone, model file,
  changelog, and a manifest with the commit and model hash) into gitignored
  `_local/backup/`.
- README rewritten around a photograph of a printed box, feature renders, and
  the preset table.

### Changed (CI)
- All GitHub Actions bumped past the Node 20 deprecation: `checkout` v4 to v7,
  `setup-python` v5 to v7, `configure-pages` v5 to v6, `upload-pages-artifact`
  v3 to v5, `deploy-pages` v4 to v5.

### Notes on the height convention
The base is **added below** the box rather than carved out of the floor, so
`Box_Height` keeps meaning "the box body" and enabling Gridfinity never silently
steals interior height. Carving instead would have required a separate
`Floor_Thickness` threaded through stabilizer, bottom-opening, clip, and post
placement, all of which currently treat `Wall_Thickness` as the floor. The whole
box is lifted by the base height at render time so the exported object still
sits on z=0.

The same reasoning applies to the lid. Its lip is the mating face, so z=0 is the
exposed top, and the profile grows downward from there with the lid lifted to
match. The original prototype placed it on the lip side, which would have buried
it inside the closed box.

### Provisional: the lid Gridfinity profile
The lid interface is currently a **positive stud**, so the closed box behaves
like a bin that sits in a baseplate. If the intent is instead for Gridfinity
bins to sit on top of the closed lid, it needs to be a socket. This is unresolved
pending a physical print, and may change. The box underside interface is not
affected. Both are off by default.

Gridfinity is by Zack Freedman and is MIT licensed. See `THIRD_PARTY_NOTICES.md`.

## [1.1.1] - 2026-07-29

### Fixed
- Side openings anchored flush with the box floor produced a non-manifold solid.
  The cut stopped exactly on the box bottom plane, leaving a zero-thickness
  tangency that CGAL reports as `Simple: no` and a slicer may reject. The cut is
  now sunk `SPACER` below its own bottom edge so it crosses that plane with real
  cross-section. Caught by the new geometry test harness on its first run.

### Changed
- **Licence changed from `CC BY-NC-SA 4.0` to `MIT`.** The NonCommercial clause
  blocked selling printed copies, blocked print-on-demand, and was at best
  ambiguous on platforms with creator rewards. MIT matches Gridfinity's own
  licence, suits a model that is really source code, and is GPL-compatible for
  a future browser customizer.

### Added
- `Model_Version` constant, echoed at render, so an exported STL can be traced
  back to the source that produced it.
- `scripts/check-version.sh`: fails the build when `Model_Version`, the top
  `CHANGELOG.md` section, and the git tag disagree. Handles `-rc` suffixes.
- `tests/`: a data-driven geometry regression harness. 39 scenarios asserting
  exit code, assertion text, manifoldness, disconnected-solid count, absence of
  warnings, and point probes against the exported mesh. Every defect fixed in
  1.1.0 has a regression scenario.

## [1.1.0] - 2026-07-28

First release published under `prisant-labs`. Fixes four geometry defects that
could produce unprintable output without any error, and adds validation so
out-of-range parameters fail with an actionable message instead of silently
generating broken solids.

### Fixed
- Side openings now deliver their full requested height. The cut was centered on
  the box floor, so half of it fell below the model and `All_Opening_Height = 30`
  produced a 15 mm opening. Openings are now anchored at their bottom edge.
- `Bottom_Openings_Count = 0` no longer cuts two unintended floor openings.
  The count reached `for (i = [0:count-1])` as `[0:-1]`, which OpenSCAD's
  deprecated reverse-range behavior iterates as `-1` then `0`. With the center
  post enabled the two cutouts undercut the post footprint and detached it from
  the floor, producing two disconnected solids at exit code 0.
- `Box_Corner_Radius` is now clamped against the inner cavity rather than the
  outer shell. The previous clamp used `min(R, Box_Width/2, Box_Depth/2)` but the
  same value was reused for the inner cuboid, which is `Wall_Thickness*2` smaller,
  so any radius above `(min(Box_Width, Box_Depth) - Wall_Thickness*2)/2` aborted
  inside BOSL2. A radius that has to be reduced is now reported via `echo`.
- `Closed_Post = true` now closes the post bottom as documented. It previously
  shortened the bore from the top, which left a cap at the post's upper end and
  the floor still open.
- Seam clips are no longer placed over the post opening. With `Clips_Per_Edge = 1`
  the single clip landed at the box center, directly above the open post bore,
  where it had no material to bond to and exported as a loose solid. Box and lid
  clip positions are now pushed clear of the post opening.

### Added
- Validation for degenerate inputs that previously rendered successfully and
  produced unusable geometry: box and wall dimensions, post diameter versus the
  interior, stabilizer height and depth versus the box, negative stabilizer
  counts, side-opening height versus box height, and bottom opening count and size.
- `Max_Corner_Radius`, `Corner_Radius`, `Floor_Clip_Clearance`, and
  `Lid_Clip_Clearance` derived values, so the constraints above are computed once
  and reused rather than restated at each call site.

### Changed
- **Breaking:** `All_Openings_Up` and the per-side `Move_Opening_*_Up` values now
  measure the opening's bottom edge above the box floor, rather than offsetting a
  cut centered on the floor. `0` sits an opening flush with the box bottom so a
  cable on the desk passes straight in. To centre an opening in the wall, use
  `(Box_Height - All_Opening_Height) / 2`. Saved presets that compensated for the
  old behavior need their vertical offsets revisited.
- Primary model renamed to `cable-box-parametric.scad`.
- Repository moved to `prisant-labs/3d-cable-box-parametric-openscad`; all
  references, the docs site config, and the SCAD header updated to match.
- Agent working notes and private scratch directories are no longer tracked.
- `Closed_Post` Customizer help corrected to describe the actual behavior.

## [1.0.0] - 2026-02-16

### Added
- Initial project scaffold with GitHub best-practice baseline files.
- CC BY-NC-SA 4.0 licensing documents and contribution terms.
- Full parameter documentation in `docs/PARAMETER_REFERENCE.md`.
- Workflow guide in `docs/WORKFLOWS.md`.
- Docs set covering FAQ, printing, release, architecture, modules, and validation.
- Folder scaffolding and contribution guides for `library/` and `community/`.
- OpenSCAD smoke automation:
  - `.github/workflows/scad-smoke.yml`
  - `scripts/scad-smoke.ps1`
  - `scripts/scad-smoke.sh`
- Initial release artifact preset under `library/v1-default/`:
  - `stl/` baseline outputs
  - `images/` baseline previews
  - `config.json` and `notes.md`
- Per-side opening corner radius overrides and a global default.
- Stabilizer spacing controls for front/back and left/right walls.
- `Bottom_Opening_Post_Margin` for clearance around the center post.

### Changed
- Rewrote SCAD Customizer inline help for concise, parameter-level guidance.
- Removed numeric slider range annotations from user-facing Customizer parameters.
- Implemented true `Custom` placement behavior for front/back and left/right
  stabilizer alignment modes.
- Implemented true `Custom` behavior for bottom opening secondary alignment
  (centers within the custom margin window).
- Tightened slicing validation (`Slice_Piece_To_Render` integer and range checks,
  plus clip parameter guards).
- Clarified opening offset directionality in SCAD inline help and docs.
- Hardened local smoke scripts for real-world execution:
  - PowerShell runner uses deterministic process checks and parameter-set
    handling for `Part_To_Render`.
  - Bash runner supports `OPENSCAD_BIN` override and Windows Bash fallback paths.

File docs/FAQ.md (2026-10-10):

# FAQ

## Which OpenSCAD version should I use?

Use a current stable OpenSCAD release (2021.01+ recommended).

## I only want numeric entry fields in Customizer. Are sliders required?

No. This project intentionally avoids numeric slider range annotations in the primary parameter block so typed values and step arrows are the main input method.

## Why do my lid and box not fit well?

Tune `Lid_Lip_Gap` in `0.05 mm` increments and print a short calibration pair. Printer, material, and cooling profile all affect final fit.

## What is a good starting value for `Lid_Lip_Gap`?

The default `0.15` is a clearance on each side of the wall the lid fits against. It fitted well with both lid styles on a Bambu Lab P1S printing PLA+. Other printers and materials differ, so print a [fit test box](PRINTING.md#fit-test-box) and adjust in `0.05 mm` steps. PETG and ABS often need slightly larger values.

## Why are my side openings not where I expect?

Global offsets (`All_Openings_Right`, `All_Openings_Up`) combine with each side-local move parameter. Reset one layer of offsets to zero and re-apply intentionally.

Vertically, openings are anchored at their **bottom edge**. The default `All_Openings_Up=5` lifts that edge 5 mm above the box floor. Set `All_Openings_Up=0` to place it flush with the box bottom, so a cable lying on the desk passes straight in without climbing a lip. To centre an opening in the wall instead, set `All_Openings_Up` to `(Box_Height - All_Opening_Height) / 2`.

## How tall is my opening really?

Exactly `All_Opening_Height` (or the per-side override). Earlier builds centred the cut on the box floor, so half of it fell below the model and the visible opening was only half the requested height. That is fixed; if you previously compensated by doubling the height or by setting `All_Openings_Up`, revisit those values.

## Which way is positive for side-local opening move values?

- `Move_Opening_Front_to_Right`: positive moves right (`+X`)
- `Move_Opening_Back_to_Right`: positive moves left (`-X`)
- `Move_Opening_Right_to_Right`: positive moves toward back (`+Y`)
- `Move_Opening_Left_to_Right`: positive moves toward front (`-Y`)

## Why are my side override sizes not applied?

Side override width/height values apply only when greater than `0`. A value of `0` means "use global opening size".

## Why do I get an assertion failure about opening height and width?

`All_Opening_Height` and `All_Opening_Width` must both be greater than `0`.
Either dimension can be larger (vertical, horizontal, or square opening profiles are allowed).

## Why are bottom openings colliding with the center post?

Enable both `Enable_Post=true` and `Bottom_Opening_Avoid_Post=true` so the model splits openings around the center clearance region.

## What do `Bottom_Opening_Axis` and `Bottom_Opening_Orientation` each control?

- `Bottom_Opening_Axis`: where openings are arranged as a sequence.
- `Bottom_Opening_Orientation`: rotation of each individual opening shape.

## What does bottom-opening secondary `Custom` alignment do?

Secondary `Custom` centers the opening line inside the custom margin window on the perpendicular axis (left/right window for `Along Y`, front/back window for `Along X`).

## Why does `Bottom_Opening_Spacing=0` look different from a fixed number?

`0` enables auto spacing derived from alignment mode and available room. Any positive number forces explicit spacing.

## My stabilizers overlap side openings. How do I prevent that?

Use the relevant avoid toggles:

- `Stabilizer_Avoid_Front_Opening`
- `Stabilizer_Avoid_Back_Opening`
- `Stabilizer_Avoid_Left_Opening`
- `Stabilizer_Avoid_Right_Opening`

Then adjust stabilizer counts/margins.

## What does stabilizer `Custom` alignment do?

`Custom` uses the custom margins as bounds and attempts fixed-pitch placement from the start margin. The pitch is `Stabilizer_Width + Stabilizer_FB_Spacing` for front/back walls and `Stabilizer_Width + Stabilizer_LR_Spacing` for left/right walls. If that pattern does not fit inside the margins, it falls back to distributed placement within the same bounds.

## What does `Closed_Post` do?

With `Closed_Post=false` (the default) the post is a tube open at both ends, so cables can be routed down through it and out of the box floor.

With `Closed_Post=true` the bore starts above the floor, leaving a solid base `Wall_Thickness` thick. Use this when you want the post purely as a cable-wrapping core and do not want debris or cable ends dropping through onto the desk.

The post's top is open in both modes.

## When should I use slicing mode?

Use slicing when full-size parts exceed your printer bed limits or when you want smaller printable modules that snap together.

The pieces push together along each seam. Floor clips keep them in line, and a 45 degree sawtooth through the walls keeps them level, so the rims meet flush. `Seam_Tooth_Depth` sets the teeth's depth, and `0` gives a flat seam. For a permanent box, glue the tooth faces.

## How do I export slices correctly?

1. Set `Enable_Slicing=true`.
2. Set `Slice_Count`.
3. Set `Slice_Piece_To_Render` to `1..Slice_Count`.
4. Export each index as an STL.

Use `Slice_Piece_To_Render=0` only for multi-part preview.

## Why did I get an assertion failure for slice/clip parameters?

The model enforces:

- `Slice_Piece_To_Render` is an integer in `0..Slice_Count`
- `Slice_Count >= 2` when slicing is enabled
- `Clips_Per_Edge >= 1` when slicing is enabled
- `Clip_Tolerance >= 0`
- `Seam_Tooth_Depth >= 0`, and less than half a slice width minus `Clip_Tolerance`, when slicing is enabled
- `Lid_Height` at least `Clip_Tab_Height` plus 0.04 mm when slicing is enabled, so the lid's seam clips stay inside the lid
- Clip tab width/depth/height all `> 0`

## How do I run automated OpenSCAD smoke checks?

- GitHub Actions: `.github/workflows/scad-smoke.yml`
- Windows local: `scripts/scad-smoke.ps1`
- Linux/macOS local: `bash scripts/scad-smoke.sh`
- Bash fallback: set `OPENSCAD_BIN` if `openscad` is not on PATH.

The smoke set includes an expected-fail assertion case to guard invalid slicing input.

## Slice clips are too tight. What should I change first?

Increase `Clip_Tolerance` by `0.05` and test one seam before reprinting all pieces.

## Slice clips are too loose. What should I change first?

Decrease `Clip_Tolerance` in small steps and retest. You can also increase `Clip_Tab_Width` or clip count for more retention.

## Can I disable the center post entirely?

Yes. Set `Enable_Post=false`.

## Is there somewhere I can browse the presets before downloading?

Yes. The [preset library](../library/) on the docs site shows all nine with a 3D
view of each part you can orbit, the parameters that define it, and downloads
for STL, GLB and `config.json`. It filters by printer bed size and by feature,
so you can narrow to what actually fits your machine.

The same catalogue is available as data at `library/index.json` if you want to
script against it. Everything there is generated from the model by
`scripts/build_library.py`, so a preset cannot drift from the geometry.

## What is the GLB file next to each STL?

The 3D preview format the docs site uses. `<model-viewer>` reads glTF and not
STL, and a GLB is roughly a tenth the size of the same mesh as ASCII STL. Print
the STL; the GLB is for looking at.

## The lid is very hard to get off. What can I do?

Three options, cheapest first.

1. Increase `Lid_Lip_Gap` in `0.05 mm` steps. It is a friction fit, and
   the default `0.15` has been confirmed on one printer so far.
2. Set `Lid_Relief_Style` to `Scallop` or `Tab`. That adds finger purchase to
   the lid edge: a scallop is a concave groove and does not change the outer
   size, a tab is a protruding grip and is more effective. Choose walls with
   `Lid_Relief_On_Left` and friends.
3. If the problem is that the lid falls off rather than sticks, that is the
   opposite fix: see `Enable_Lid_Magnets` below.

## How do the lid magnets work?

`Enable_Lid_Magnets` cuts a pocket in the box and a matching pocket in the lid
at each of the four inside corners, so a magnet in each holds the lid shut.
Corners rather than the rim, because the rim is only `Wall_Thickness` wide
(1.85 mm by default) and a 6 mm magnet does not fit in it.

`Lid_Magnet_Diameter` defaults to `6.2` for a nominal 6 mm magnet.
`Lid_Magnet_Depth` is the depth in *each* half, and each pocket takes its own
magnet: at the default `2.4`, one magnet per pocket, up to 2.4 mm thick.

**Insert the magnets with opposing poles facing.** The pockets are symmetric so
they align however the lid goes on, which also means the model cannot enforce
polarity for you. Glue one pair at a time and check attraction before the
adhesive sets.

## My box edges are sharp. Can they be rounded?

`Bottom_Edge_Fillet` rounds the outer bottom edge and `Top_Edge_Chamfer`
chamfers the top rim and the lid edges. Both are `0` by default, so nothing
changes until you ask.

Keep the bottom fillet modest. It is the first thing printed, and a large one
becomes an overhang on the opening layers; around `1.0` is a good starting
point. If those layers curl, set `Bottom_Edge_Style` to `Teardrop`, which keeps
the rounded look but meets the bed at 45 degrees, or to `Chamfer`, a plain 45
degree bevel. `Bottom_Edge_Fillet` sets the size for all three styles. Both
treatments are ignored where a Gridfinity interface owns the face, because
those profiles have to match the standard.

## Can I print the box without supports?

Yes, at the defaults. Every feature either stands on the bed or rises at 45
degrees or steeper, except for a few short arcs and bridges. Three options
remove those:

- `All_Opening_Top_Style=Teardrop` replaces the flat top of each rounded side
  opening with 45 degree flanks and a short flat cap. The opening keeps its
  typed width and height.
- `Bottom_Edge_Style=Teardrop` or `Chamfer` makes a bottom edge treatment meet
  the bed at 45 degrees instead of curling under.
- `Print_Layer_Height` should match the layer height you slice at when the
  Gridfinity base has magnets, so the two bridging steps above each pocket
  print as separate layers.

All three keep today's shapes by default, so a saved preset renders exactly as
before. `docs/PRINTING.md` has the details.

## How do I load one of the presets?

Open `cable-box-parametric.scad` and press `F3`. All nine presets appear in the
Customizer's preset dropdown, because `cable-box-parametric.json` sits next to
the model and OpenSCAD reads parameter sets from it.

From the command line:

```bash
openscad -o out.stl cable-box-parametric.scad \
  -p cable-box-parametric.json -P desk-compact
```

Each preset also keeps its own copy at `library/<preset>/config.json`, which
takes the same `-p` and `-P` arguments.

## A preset config.json will not load and OpenSCAD reports a type error

If you see:

```
ERROR: Cannot apply Parameter Set 'conversion of data to type "b" failed'
```

you have a `config.json` from release 1.4.0 or earlier. Boolean values were
written capitalised (`"True"`) where the format requires `"true"`, and OpenSCAD
rejects the whole parameter set rather than skipping the bad value. It affected
`gridfinity-module`, `surge-strip-6-sliced` and `under-desk-passthrough`. Fixed
in 1.4.1: take the current files, or lowercase the booleans by hand.

## Where should reusable preset builds and assets go?

`library/` holds the curated presets, but everything in it is generated. Add an
entry to `PRESETS` in `scripts/build_library.py` and rerun it rather than adding
files by hand.

## Where should community-created variants go?

Use `community/` for user-contributed builds, remixes, and showcase assets.

## What license applies to this repository?

`MIT` for project content, with third-party portions retaining their original licenses (see `THIRD_PARTY_NOTICES.md`).

## Can this box work with Gridfinity?

Yes, in two independent ways, and they are opposite halves of the same joint.

`Enable_Gridfinity_Bottom` puts solid Gridfinity feet under the box, built to
the spec's profile, so it drops into a 42 mm baseplate. The footprint rounds up
to whole cells, so the default `100 x 75` box becomes `125.5 x 83.5`.

`Enable_Gridfinity_Lid_Top` puts a Gridfinity **baseplate** on the lid's exposed
face: a plate with sockets cut into it, so bins or another box sit on the closed
box. Sockets rather than studs, because the lid inverts in use and studs would
end up pointing at the ceiling with nothing able to rest on them. It adds
4.75 mm to the closed height.

Turn on either, both, or neither. Both together gives a box that sits in a
baseplate and is itself a baseplate.

The feet follow the spec's profile, and the test suite seats them in a
baseplate built from the spec's own numbers. The lid top is still experimental:
test prints show its sockets do not yet print or fit as cleanly as a standard
baseplate. Test a one-cell [fit test box](PRINTING.md#fit-test-box) against
real Gridfinity parts before you print a full box.

## Why does Gridfinity require `Closed_Post`?

An open post bores through the box floor. A Gridfinity base sits directly under
that floor and would block the bore, so the model asserts rather than producing
a passage that goes nowhere. Set `Closed_Post=true`, or turn the post off.

## Why did my box get bigger when I turned on the Gridfinity base?

The base rounds the footprint up to whole cells: each side becomes the smallest
`(N - 1) * 42 + 41.5` mm that holds what you typed. A box wider than its feet
would overhang them, and on a baseplate that overhang blocks the neighbouring
cells anyway, so rounding up costs no desk space. The model echoes the size it
built in the OpenSCAD console. To keep the box close to a size you have in
mind, type the nearest whole-cell size: `41.5`, `83.5`, `125.5`, `167.5`, and
so on.

## I enabled the Gridfinity lid top but nothing appeared

The lid is probably too small for a single 42 mm cell once
`Gridfinity_Edge_Keepout` is taken off each side. The model says so via `echo`
in the OpenSCAD console. At the default `4 mm` keepout the lid needs roughly
`50 mm` in both directions for one cell.

## Does enabling Gridfinity shrink the inside of my box?

No. The base is added below the box rather than carved out of the floor, so
`Box_Height` still describes the box body and interior volume is unchanged.
Total printed height grows by `4.75 mm`.

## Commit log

2026-07-28 feat: parametric cable box v1.1.0
    Public release under prisant-labs. Fixes five geometry defects that could
    produce unprintable or wrong-sized output without raising an error, and adds
    validation so out-of-range parameters fail with an actionable message.
    Fixed:
    - Side openings delivered half their requested height. The cut was centred on
    the box floor, so only its top half intersected the model and
    All_Opening_Height=30 produced a 15mm opening. Openings are now anchored at
    their bottom edge and sit flush with the box bottom by default, so a cable
    resting on the desk passes straight in.
    - Bottom_Openings_Count=0 cut two unintended floor openings. The count reached
    for (i = [0:coun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
    [cable-box-parametric.scad]
2026-07-29 docs: scope 11 planned efforts in docs/internal/
    Adds scoping documents for the roadmap discussed after the v1.1.0 release,
    plus an index with dependencies and a suggested order. Excluded from the
    published docs site via exclude_docs so they live in the repo without
    appearing on the public site.
    E-01 (Gridfinity promotion) - ship the prototyped box-underside and
    lid-topside interfaces
    E-02 (BOSL2 migration) - replace the embedded 2022 subset with a real
    dependency, adopt attachments
    E-03 (openings array) - lift the one-opening-per-wall limit
    E-04 (quick wins) - edge treatment, lid relief, magnet retention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
2026-07-29 feat: MIT licence, SemVer tooling, and geometry regression tests (1.1.1)
    Licence
    -------
    Relicensed from CC BY-NC-SA 4.0 to MIT. The NonCommercial clause blocked
    selling printed copies and print-on-demand, and was at best ambiguous on
    platforms with creator rewards programmes. MIT matches Gridfinity's own
    licence, suits a model that is really source code, and is GPL-compatible for
    a future browser customizer. Decision and reasoning recorded in
    docs/internal/E-11_distribution.md.
    Versioning
    ----------
    Model_Version constant echoed at render, so an exported STL can be traced back
    to the source that produced it. scripts/check-version.sh fails the build when
    Model_Version, the top CHANGELOG.md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
    [cable-box-parametric.scad]
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2026-07-31 feat: preset library, visual options guide, README, and CI action bumps
    Preset library
    --------------
    Nine generated presets in library/, organised by what the user physically has
    rather than by dimensions: usb-charger, desk-compact, gridfinity-module,
    laptop-brick, under-desk-passthrough, monitor-junction, router-shelf,
    surge-strip-6, and surge-strip-6-sliced. Each ships a complete config.json,
    box/lid/assembled STLs, renders, and notes with measured envelopes.
    All of it is generated by scripts/build_library.py from a data table. Adding a
    preset is a dict entry. This is the fix for the failure mode the audit found,
    where the hand-made v1 artifacts silently showed half-height openings for m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
2026-07-31 feat: replace embedded BOSL2 with a real dependency (1.3.0)
    E-02 (BOSL2 migration) phase 1. The model declares include <BOSL2/std.scad>
    instead of carrying a February 2022 subset minified onto a single
    214,500-character line that was 79 percent of the file. 271 KB to 72 KB, and
    reviewable for the first time.
    Dimensionally identical. Mesh volumes match 1.2.0 to four decimal places across
    every configuration tested; only corner-rounding tessellation differs, by a
    handful of facets. Volume rather than a coordinate hash is the right invariant
    here, and the original acceptance criterion has been corrected to say so.
    The API surface turned out to be tiny and entirely stable across the four-year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
    [cable-box-parametric.scad]
2026-08-03 feat: E-02 phases 2 and 3, snap clips and attachables
    Both phases on a branch; main and v1.3.0 are untouched.
    Phase 2: snap-fit seam clips
    ----------------------------
    Clip_Style enum adds "Snap", a BOSL2 rabbit_clip cantilever joint, alongside
    the original "Tab". The tab is a rectangle in a slightly larger rectangular
    hole held by friction, with Clip_Tolerance as its only knob trading "will not
    go in" against "falls apart". The snap has an engagement bump and an arm that
    flexes, so it absorbs print error instead of jamming.
    Default stays "Tab". Clip geometry is the one part of this model whose
    correctness cannot be established by rendering it: manifoldness, solid counts,
    and probes all pa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
    [box_floor.scad, box_rim.scad, cable-box-parametric.scad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]
2026-08-03 fix: snap pin never overlapped its slice, and local tests used the wrong BOSL2
    CI caught two real problems that a green local run had hidden.
    The pin did not overlap its slice
    ---------------------------------
    The existing clip offsets assume a CENTRED cube: Clip_Tab_Depth/2 - SPACER
    pulls a centred tab's near face back to the seam. A rabbit_clip is
    BASE-anchored, so its geometry starts at the placement point and grows away
    from the slice. The same offset left the pin floating in the gap with nothing
    to bond to, and the slice exported in three pieces. Offsets are now style-aware.
    Local tests were running against a different BOSL2 than CI
    ----------------------------------------------------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
    [cable-box-parametric.scad]
2026-08-03 feat: missing-BOSL2 guard, README and changelog for 1.4.0
    Guard
    -----
    Without BOSL2 installed the model produced "Can't open include file", a wall of
    "Ignoring unknown module" warnings, no geometry, and exit code 0. Nothing in
    that named what to install, and the zero exit made it look like it worked.
    It now stops with one message pointing at both remedies: install BOSL2, or use
    the standalone bundle attached to every release. BOSL_VERSION comes from BOSL2
    itself, so its absence is the signal.
    Tested by a generated fixture: the model with its include redirected to a
    library that does not exist, so the guard is exercised without uninstalling
    anything. Regenerate with scripts/regen_missing_bo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
    [missing_bosl2.scad]
2026-08-05 release: 1.4.1, preset configs that OpenSCAD will actually load
    1.4.0 shipped three preset config.json files that OpenSCAD rejects outright,
    so this is a patch release rather than a silent fix. No geometry change: the
    model is untouched apart from Model_Version, and no STL in library/ differs.
    Bumps Model_Version, adds the 1.4.1 CHANGELOG section, regenerates the
    standalone bundle and the missing-BOSL2 fixture (both embed the version), and
    documents cable-box-parametric.json in the README next to the per-preset form.
    Version consistency check passes across scad, changelog and tag. 65 tests pass.
    Claude-Session: https://claude.ai/code/s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
    [cable-box-parametric.scad, missing_bosl2.scad]
2026-08-06 feat!: Gridfinity lid top is a baseplate with sockets, not studs
    BREAKING. Same parameter set, different geometry, so this is a major bump
    under E-10 when it is released.
    The lid inverts in use: its lip is the mating face, so the panel's other side
    is the exposed top of a closed box. The old implementation added a two-stage
    stud to that face, which left a closed box carrying Gridfinity feet pointing
    at the ceiling with nothing able to rest on them. The parameter's own doc
    comment described a baseplate, so code and docs had disagreed since it
    shipped; the docs were right about the intent.
    Now a 4.75mm plate spanning the lid with a mating socket cut into each cell,
    so a bin or another box dr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
    [cable-box-parametric.scad]
2026-08-07 fix: three defects from adversarial review of the lid socket change
    All three were found by an adversarial review of the v1.4.1...HEAD diff and
    verified before fixing.
    Lid magnet pockets were unusable. The pocket cut still started at the lid
    panel interface as in the stud era, overlapping the socket void: only the
    0.45mm between socket and panel remained, so a 2.4mm magnet stood proud into
    the socket and held every foot off the floor. Pockets now open at each socket
    floor and reach into the panel, capped to keep GF_MIN_FLOOR solid. The screw
    hole and counterbore are removed from the lid: a baseplate's screws fasten it
    to a surface, and here that surface is the sealed lid. Bottom base unchan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
    [cable-box-parametric.scad]
2026-08-07 feat: docs site on Astro Starlight, synced from docs/ at build time
    Replaces MkDocs Material with Astro Starlight per phase 1 of the site plan
    (_local/plans/2026-08-03_gh-pages-astro-site.md). Same URL, same pages, same
    nav structure; page slugs move from uppercase to kebab-case.
    The structural decision: docs/ stays the single source of truth. The README
    links nine of these files by repo path, GitHub renders them in place, and
    build_options_guide.py generates one of them, so moving them into the site
    was wrong, and copying them would mean two maintained copies of every page.
    Instead web/sync-docs.mjs regenerates src/content/docs/ from docs/ on every
    dev run and build (predev/prebuild hooks)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
2026-08-08 release: open the 2.0.0 section and bump Model_Version
    The socket rework in a68db40 renders different geometry from the same
    parameter set, which E-10 (versioning) makes a major bump even though
    the new geometry is the one Enable_Gridfinity_Lid_Top always documented.
    This lands first rather than last so that every generated artifact
    committed after it carries the version its source actually declares.
    scripts/check-version.sh ties Model_Version to the top released
    CHANGELOG section, so the two have to move together in one commit
    anyway.
    The release itself is still gated on a physical print: the Gridfinity
    socket clearances and the lid clip placement are arithmetic, not
    measurements. E-10's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
    [cable-box-parametric.scad]
2026-08-08 fix: sliced lid exports no longer carry zero-area triangles
    The lid seam clip sat with its top face exactly flush with the top of the
    lid panel, because a centred cube placed at
    z_pos = Lid_Height - Clip_Tab_Height/2
    has its top at exactly Lid_Height. Flush, the clip's top face and the
    panel's top face are one coplanar face, so on the slice seam the clip's
    corners became extra collinear vertices along an otherwise straight edge.
    OpenSCAD's tessellator fans across those into zero-area triangles.
    Measured across every sliced configuration: four such triangles per piece
    with Tab clips, eight with Snap, and none on any box piece or unsliced
    lid. The meshes were otherwise sound - watertigh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
    [cable-box-parametric.scad]
2026-08-08 feat: machine-readable library index and GLB previews
    Two generated artifacts so the preset library can be consumed by
    something other than a human reading a Markdown table.
    library/index.json is the twin of library/README.md, emitted from the
    same loop over PRESETS so the two cannot disagree about which presets
    exist. Per preset: overrides, printed envelope, feature flags, and the
    path and byte size of every artifact. The model's parameter defaults sit
    once at the top of the file rather than being resolved into each preset,
    so the effective set is {...defaults, ...overrides} and there is no
    second copy to drift. Those defaults are parsed out of the .scad up to
    the /* [Hidden] */ marker rat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
2026-08-08 feat: preset browser with 3D previews on the docs site
    Phase 2 of the site plan. /library/ is a card grid over the nine
    presets, filterable by printer bed size and by feature, and
    /library/<name>/ is a page per preset with an orbitable view of each
    part, the parameters that define it, and downloads for STL, GLB and
    config.json.
    Cards deliberately use the box-and-lid render. That is the one view
    build_library.py renders at a fixed camera distance rather than
    --viewall, so the grid reads as a size comparison; five of the nine
    presets differ only in dimensions and a per-card zoom-to-fit would hide
    the only difference they have.
    The pages read library/index.json directly at build time and rend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
2026-08-08 chore: regenerate the missing-BOSL2 fixture for 2.0.0
    tests/fixtures/missing_bosl2.scad is generated from the model and embeds
    Model_Version, so it is one of the three artifacts docs/RELEASE.md calls
    out as going stale silently. It picks up the version bump and the lid
    clip comment from this branch.
    The standalone bundle is the other generated artifact that embeds the
    version; it is rebuilt too but lives in gitignored dist/ and is attached
    to a release rather than committed.
    Claude-Session: https://claude.ai/code/session_019jfKua194XeB7UDHHSbkqC
    [missing_bosl2.scad]
2026-08-08 fix: pin three to the version model-viewer declares as a peer
    npm install resolved three to 0.185.1, but @google/model-viewer 4.3.1
    declares a peer dependency of three@^0.183.0. npm install tolerated the
    mismatch locally; npm ci, which is what the Pages workflow runs, enforces
    it and failed the build with ERESOLVE.
    Pinned to ^0.183.2. Verified the way CI does it rather than the way that
    hid the problem: node_modules removed, npm ci from the lockfile, then a
    full site build. 23 pages, no errors.
    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
2026-08-10 fix: GLB previews were lying on their back
    OpenSCAD models the printed object Z-up, sitting on the bed at z=0. glTF
    specifies +Y as up, and trimesh's exporter writes vertices through
    unchanged, so every preview on the docs site was rotated 90 degrees: a
    viewer read the gridfinity-module box's 100mm depth as its height and its
    59.75mm height as depth. Reported from the live site.
    The GLB stored extents (140, 100, 59.75) with no node rotation at all, so
    nothing downstream could correct for it.
    Rotated -90 degrees about X in the converter, which maps (x,y,z) to
    (x,z,-y). That matrix has determinant +1, so winding and normals survive;
    verified watertight, winding-consistent and positive volume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
2026-08-11 feat!: side openings sit 5mm off the floor by default
    All_Openings_Up changes from 0 to 5. Openings are anchored at their bottom
    edge, so every enabled side opening now spans z 5 to 35 rather than z 0 to 30.
    Set All_Openings_Up=0 to restore the previous output.
    This changes geometry for unchanged inputs, which E-10 (versioning) rates a
    major bump rather than the minor one the E-04 (quick wins) features alone
    would have been. 2.0.0 has so far existed only as release candidates, so this
    folds into that version instead of needing a new major number.
    A side effect worth recording: the opening no longer meets the floor slab.
    That removes 12 triangles per opening and raises box volume by about 2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
    [cable-box-parametric.scad, missing_bosl2.scad]
2026-10-03 refactor: rewrite the code inherited from the 2022 original
    The model began as a derivative of a 2022 Creative Commons Attribution
    design. The direction now is to make it independent rather than keep
    crediting it, and this commit removes the inherited code. The inherited
    Customizer interface (parameter names, defaults and section headers) goes
    later, in E-03 (openings array), which replaces 24 of the original's 36
    parameters anyway; its effort doc now carries the checklist.
    What changed:
    - The four copied blocks that cut the side openings are one loop over
    OPENING_SIDES. Placement comes from two new helpers,
    opening_plan_position() and get_opening_lift(), so the per-wall
    differences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
    [cable-box-parametric.scad, missing_bosl2.scad]
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2026-10-03 fix: lid relief and rim checks reason per wall
    Four validation fixes from the 2026-10-02 audit. None changes default
    geometry: twelve configurations hash identical to 0e75391 by canonical
    mesh, and all 80 scenarios pass on OpenSCAD 2021.01.
    - Relief over a raised opening (F-45). opening_reaches_rim() added only
    All_Openings_Up, so an opening lifted to the rim by Move_Opening_*_Up
    still got a tab over it. It now uses opening_top(), which counts the
    wall's own lift.
    - Openings past the rim (F-46). An opening whose top edge ends above
    Box_Height is cut open to the rim as a notch. That stays legal, and it
    is now reported with an echo; the text avoids the words the harness
    rejects. T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
    [cable-box-parametric.scad, missing_bosl2.scad]
2026-10-03 feat: calibration coupons for the fits that need a print
    2.0.0 has waited on a full-box print to validate its Gridfinity, snap
    clip, magnet and edge features. Eight small coupons, each isolating
    one fit, make that print small. Further print validation would be
    helpful, and this is the cheap way to give it.
    calibration/config.json holds the coupons as OpenSCAD parameter sets.
    scripts/build_calibration.py exports each with -p/-P and checks it the
    way the suite checks a scenario: exit code, a clean log, and the
    expected number of separate bodies. All eight pass, and the STLs are
    committed (.gitignore now keeps calibration/**/*.stl).
    calibration/README.md and a rewritten docs/PRINTING.md cover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
    [edge-treatment.stl, gridfinity-base-1x1.stl, gridfinity-lid-socket-1x1.stl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]
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2026-10-03 fix(site): canonical host, sliced sizes, and a PR build
    - The site's canonical links, og:url and sitemap named the github.io
    address, which only 301-redirects to projects.prisantlabs.com. Astro's
    site now names the custom domain; HTTPS enforcement and the repo
    homepage were set alongside.
    - surge-strip-6-sliced reported 270 mm, the preview layout with both
    halves side by side. build_library.py now also emits
    assembled_size_mm (265) and largest_piece_mm (136, measured by
    splitting the box STL into bodies with trimesh). The bed filter uses
    the largest piece instead of passing every sliced preset. Additive to
    schema 1; other presets gain two null fields.
    - Each docs page gets it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
2026-10-03 chore: tooling fixes and project rules in the repo
    - run_tests.py: native() wrote Windows paths with backslashes into the
    probe .scad, where a backslash is an escape, so a run from PowerShell
    failed every probe scenario with "path resolution failed". It now
    uses as_posix(), keeping cygpath only for MSYS /tmp paths. Confirmed:
    the old harness fails both regression_openings probes from PowerShell
    and the new one passes. A hung render now fails its own scenario
    instead of ending the run, and SCAD_TEST_TIMEOUT sets the limit.
    - build_options_guide.py: read Model_Version from the first 60 lines,
    so the guide said "unknown"; writes LF on Windows; gains --only, so
    new scenes render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
2026-10-03 docs: changelog, README and planning docs match the tree
    - CHANGELOG [Unreleased] records everything in this branch under
    Added, Changed and Fixed.
    - README: the suite is 80 scenarios; site links use the canonical
    host; one paragraph explains that library/ tracks main while a
    release is a fixed snapshot, and that releases up to v2.0.0-rc.3
    carried only sample STLs; a pointer to the calibration coupons.
    - The backlog moves from a gitignored notes file into
    docs/internal/BACKLOG.md with stable item numbers, so the four effort
    docs that cite "backlog item N" resolve for everyone. Items 9 and 10
    are done, item 4 moved to E-06 (thermal and vents), and items 13 to
    16 record the ope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
2026-10-03 docs: README leads with the presets; prepare v2.0.0-rc.4
    README:
    - "Just want to print one?" leads with the preset library. GitHub's
    "Latest" release is still v1.4.1, from before 2.0.0, so the text
    says to take the newest pre-release until 2.0.0 is final, and that
    releases attach all nine presets from v2.0.0-rc.4 on.
    - Options-guide links go to the site; GitHub shows a .html file as
    source text. The file stays linked as an offline download.
    - The slicing row said "snap clips", but Tab is the default.
    - The Gridfinity row no longer promises a baseplate fit that no print
    has confirmed, and names the lid's socket correctly.
    - A fourth feature row and image cover the finishing features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
2026-10-05 fix!: the lid fits the box, and sliced floors sit flat
    Printing the rc.4 calibration coupons found two defects that block 2.0.0.
    The lid could not fit. Its lip ring was sized Box_Width + Lid_Lip_Gap
    outside and Box_Width - Wall_Thickness + Lid_Lip_Gap inside, so on a 50 mm
    box it spanned 48.25 to 50.10 mm against a wall from 46.30 to 50.00. The
    ring landed on the outer half of the wall and the lid stood on the rim: the
    lid-fit coupon stacked 19 mm instead of 16. Those formulas date from v1.0.0,
    so every release has shipped this lid.
    The fix is a new option, Lid_Style. Skirt, the default, cuts a pocket of
    the box outline plus Lid_Lip_Gap per side into the top of the lid shell, so
    the skirt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
    [cable-box-parametric.scad, lid_seated.scad, missing_bosl2.scad]
2026-10-05 chore: regenerate coupons, presets and previews for the rc.5 lid and clips
    Every output that shows a lid or a sliced floor is regenerated from the
    previous commit's model. Outputs whose geometry did not change were
    reverted, so this diff carries only real change. OpenSCAD orders facets
    differently on every run, so "did not change" was decided by comparing
    canonical meshes (vertices rounded to 1e-4 mm, triangles sorted), not
    bytes.
    Calibration: lid-fit, magnet-boss, gridfinity-lid-socket-1x1 and both clip
    pairs changed, and the two Plug coupons are new. gridfinity-base-1x1,
    edge-treatment and side-opening were mesh-identical and reverted. The clip
    pairs drop from 15.58 to 15.0 mm tall, which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
    [gridfinity-lid-socket-1x1.stl, lid-fit-plug.stl, lid-fit.stl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]
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2026-10-07 docs: scope E-12 (Gridfinity to spec) and E-13 (seam joints)
    The rc.5 prints left two problems: both Gridfinity interfaces print
    poorly, and neither clip style holds sliced halves level. The research
    reports were checked against the spec diagram, kennetek's constants, and
    the model, and the maintainer chose a design for each on 2026-10-07.
    E-12 rebuilds the Gridfinity interfaces on the spec's solid swept
    profile. The base footprint rounds up to whole cells, because the space
    under a ledge belongs to the neighbouring baseplate pockets. A Gridfinity
    lid prints pocket-side up with a solid plug. The check also found that
    the current base cannot seat in a standard baseplate at all, and that its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
2026-10-10 feat: options for printing without supports (E-14)
    E-14 (printability options) adds three opt-in parameters. Every default
    keeps today's geometry, so no saved preset or library preset changes.
    - All_Opening_Top_Style: "Teardrop" turns each rounded top corner of a
    side opening into a 45 degree flank with a flat cap at the circle's
    top, so the opening keeps its typed height and opening_top() stays
    true for the rim, lid-relief and seam-teeth checks.
    - Bottom_Edge_Style: "Teardrop" (os_teardrop) or "Chamfer" meets the bed
    at 45 degrees. The style is passed only from the box's shell call, so
    it never reaches the lid, which shares m_edge_treated_shell.
    - Print_Layer_Height replaces the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
    [cable-box-parametric.scad, missing_bosl2.scad]
